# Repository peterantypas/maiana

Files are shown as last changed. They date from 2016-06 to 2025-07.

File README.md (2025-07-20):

# MAIANA&trade;: The Open Source AIS Transponder

I started this project around 2015 with the intention of experimenting and eventually building something for my own boat.
I was not impressed with commercial AIS class B transponders. They seemed bloated, expensive and some of them were particularly power-hungry. Also, my boat is rather small and I have very little room for "nav" instruments, so I didn't want a huge enclosure inside plus two external RF cables, one for VHF and one for GPS. So I set out to create my own "lean and mean" design and I sailed with it for 2 years.

Fast forward to 2023, and it has taken a life of its own:

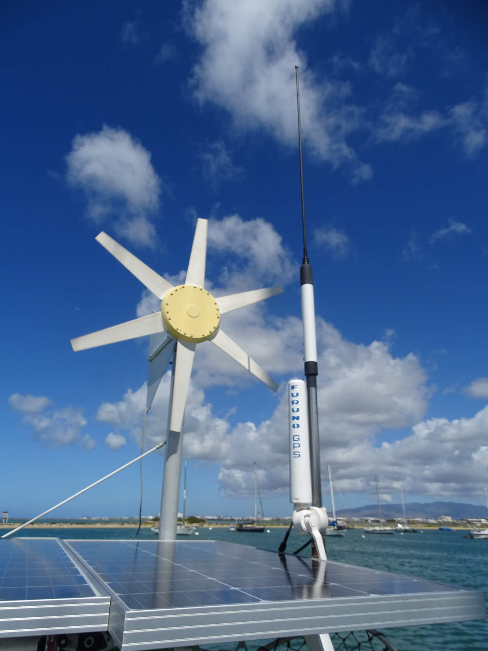
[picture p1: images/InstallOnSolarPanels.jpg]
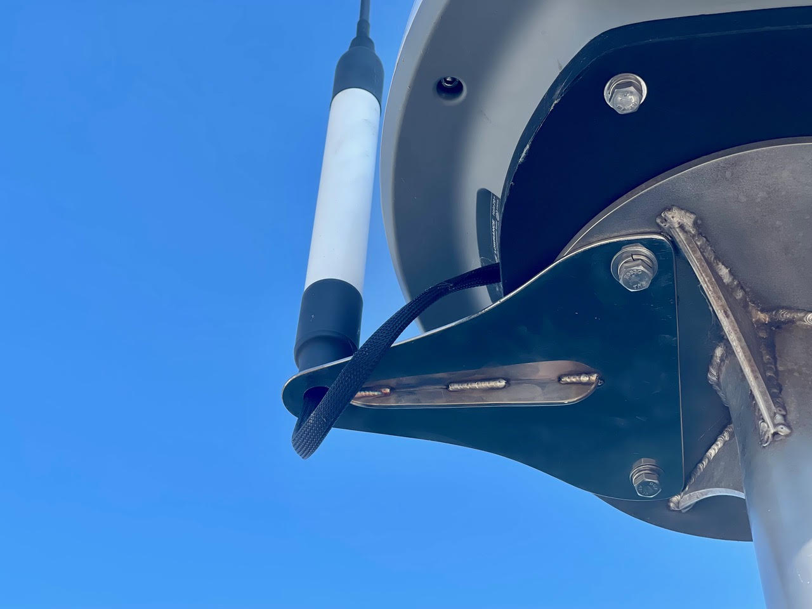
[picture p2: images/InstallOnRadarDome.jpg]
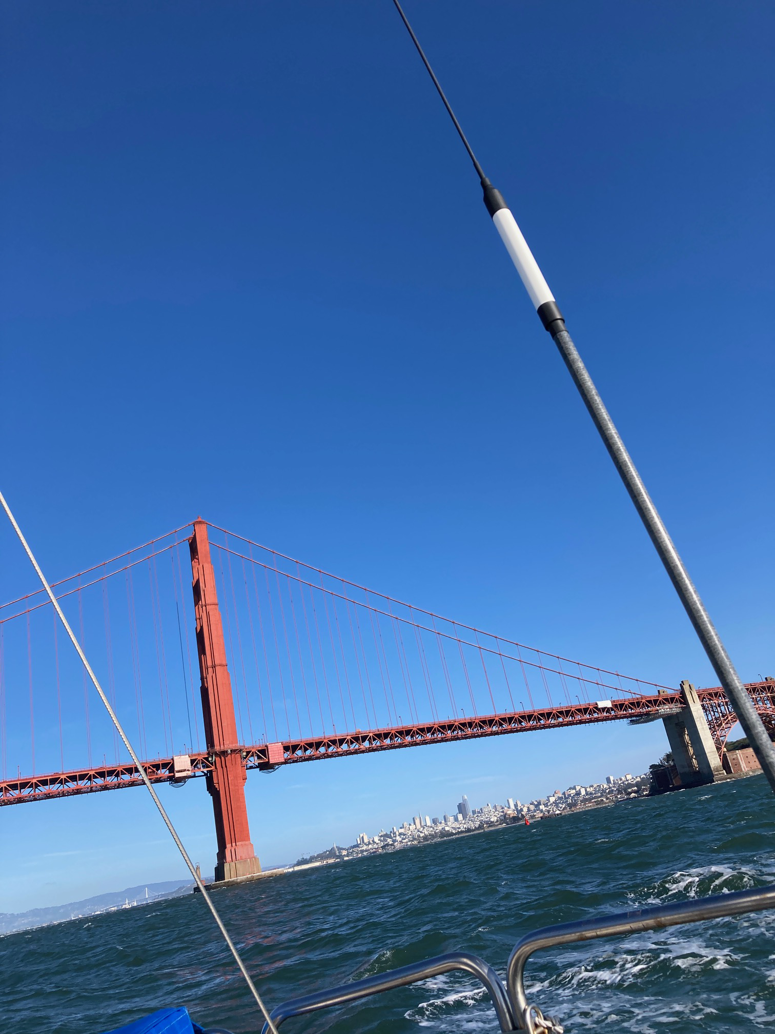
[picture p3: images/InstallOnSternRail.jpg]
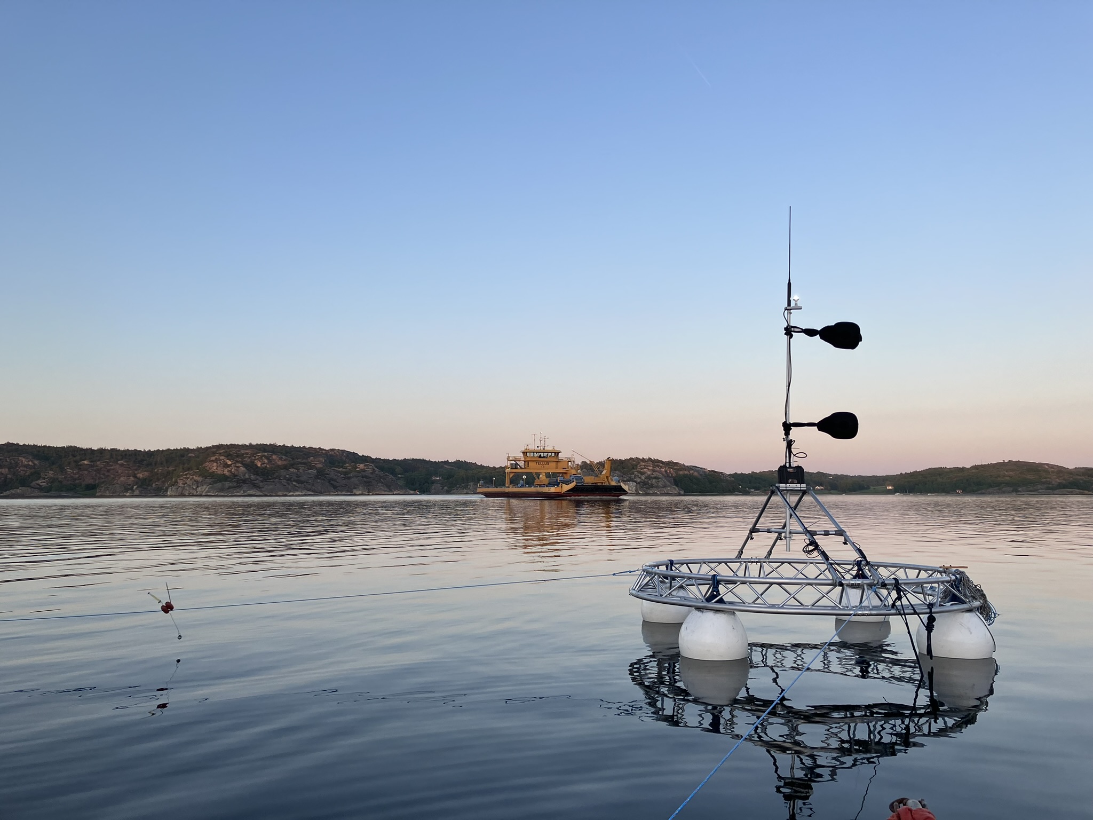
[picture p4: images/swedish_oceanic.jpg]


The main difference between MAIANA&trade; and every commercial transponder is that it's a self-contained unit, and thus its performance is 100% repeatable. The entire transponder circuit, the GNSS and all antennas are in the same housing. The design has been validated by fabricating _over 300 units_ now (July 2023).

So with all the core functionality kept outside and under tight control, the only other thing we need is power and data connections. Now, what's the most common cable that can carry a few signals 50 feet away? If you guessed "Ethernet", you guessed right. Commonplace Cat5 cable can deliver power plus serial data signals anywhere on an average sized pleasure boat. So that's how the exterior unit connects to the cabin, where one of these breakouts offers USB, NMEA0183 or NMEA2000 adapters to connect to the rest of the boat's systems. 

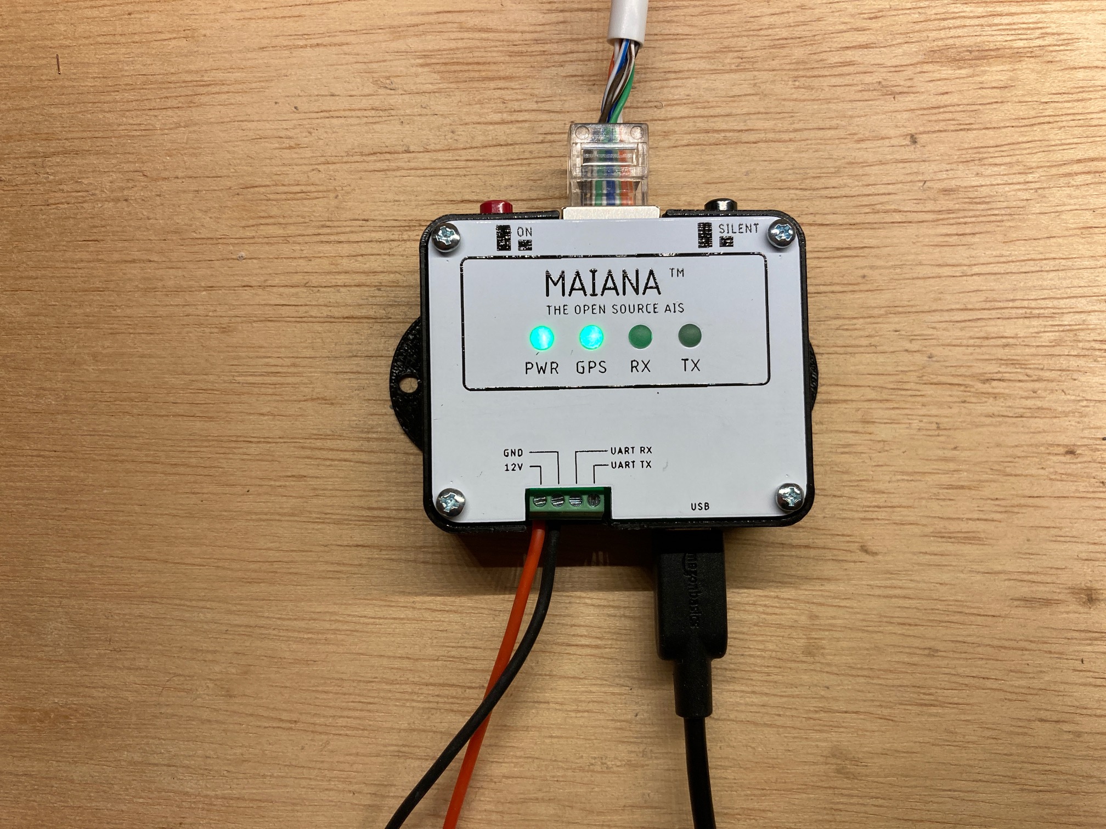
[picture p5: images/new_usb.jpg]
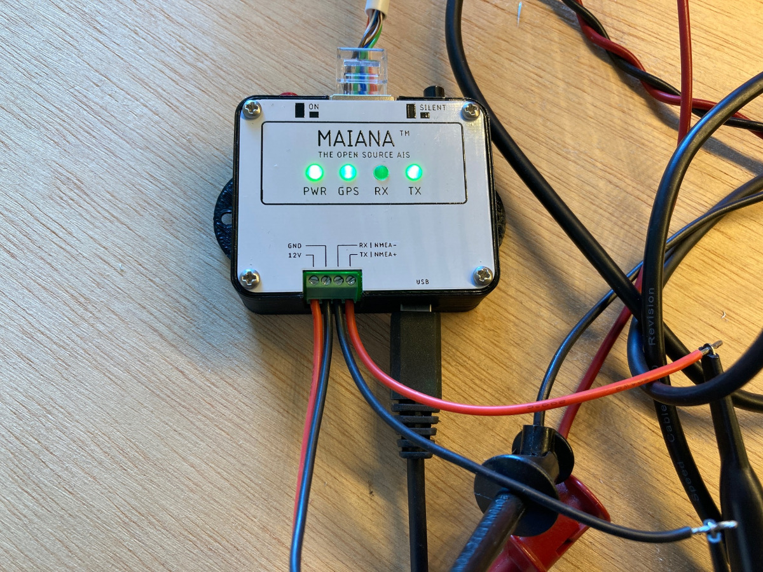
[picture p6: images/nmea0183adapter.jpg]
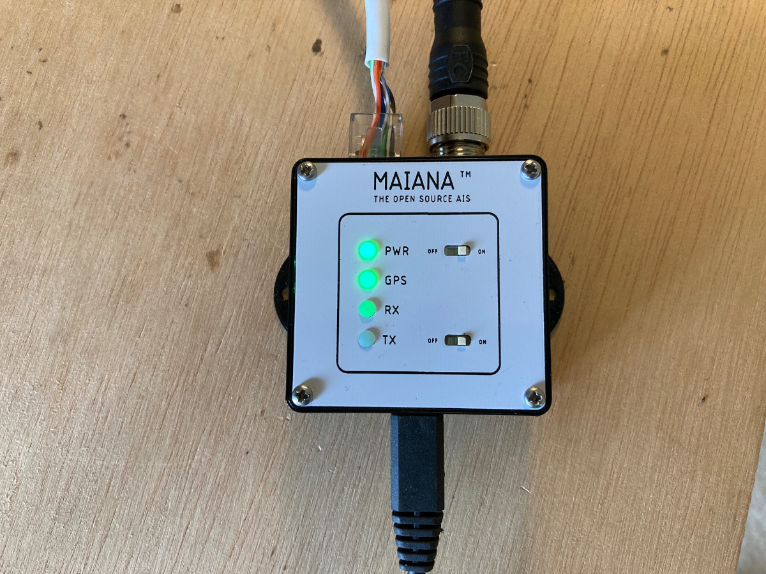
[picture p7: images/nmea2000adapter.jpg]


## Hardware Design

### Mechanical
The antenna casing that you see in these photos is a piece of 1" Schedule 40 "furniture" grade PVC pipe. It is the highest grade of such material, with a solid white PVC core (not a coated household grade pipe). Still, it's the most inexpensive UV resistant material available, and it looks great too!

The VHF antenna whip is built using an epoxy wound filament tube coated with high quality, UV resistant irradiated polyolefin ("heat shrink"). The company that makes this tubing (and helped me with this design challenge) also built the landing gear for NASA's Ingenuity helicopter on Mars, so they definitely understand how to deal with harsh environments. The bottomline is that unlike typical fiberglass antenna masts, this antenna is not going to degrade and "blossom" under continuous UV exposure. Starting with January of 2022, the antenna tube will be made of two telescopic pieces of the same material. This will greatly reduce the cost of shipping the kit to Europe and Australia.

The entire outdoor assembly is held together by the same high grade heat shrink tubing, so there is no need for any adhesives! The main water seal is formed by heat shrinking around a specially designed 3D printed cap made of PLA. This part naturally softens when heated and as it's compressed by the heat shrink tubing surrounding it, it forms a permanent, watertight colar around the antenna tube. This blocks rain water and salt spray from the top. A layer of clear heat shrink in the interior forms a secondary water seal encompassing the lower part of the antenna. Finally, the PCB can be sprayed with conformal coating for an added layer of protection. Silicone spray works best and has no appreciable detuning effect on the GNSS.

With no adhesives getting in the way, the unit can actually be opened and serviced by (carefully) cutting through the heat shrink tubing with a knife, then resealing with the same material and method as before. This, in fact, was one of my design goals from the beginning.

### Electrical
As I mentioned already, the transponder circuit is inside the antenna case. It's a 24mm x 84mm 4-layer PCB:

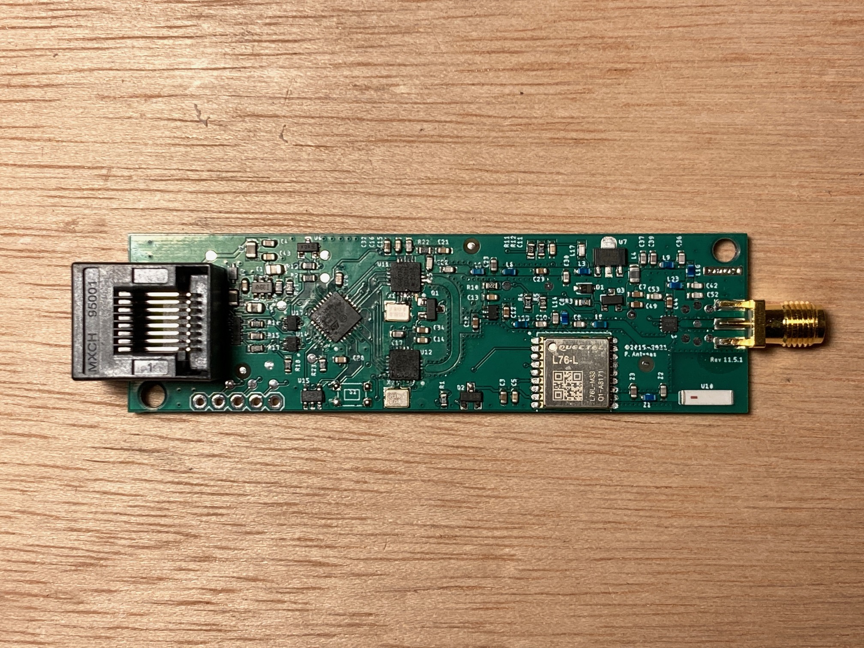
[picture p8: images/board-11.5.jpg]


The core design is based on two Silicon Labs "EZRadio Pro" series ICs. All kits shipping today are based on the Si4460.

The microcontroller on this board is a STM32L4 series (422, 431 and 432 supported). I chose these because the 80MHz clock allows the SPI bus to operate at exactly 10MHz which is the maximum supported by the Si446x ICs. This is important, as a transponder is a *hard real time* application, so SPI latency must be minimized. All kits today are based on the STM32L432KBU6.

The GNSS is now a Quectel L76L-M33 and relies on a Johansson ceramic chip antenna. It usually takes a minute to acquire a fix outdoors from a cold start. With the latest antenna tuning, it offers near-navigation grade accuracy (typical HDOP at sea is less than 2 meters).

The transmitter front end is based on a power MOSFET typically found in handheld VHF radios and outputs just over 2 Watts (+33dBm). It has a verified range of over 20 nautical miles on a masthead and 10+ miles on a pushpit.

The system is designed to run from a 12V battery and exposes a 3.3V-level UART for connecting to the rest of the boat. The UART continuously sends GPS and AIS data in NMEA0183 format at 38.4Kbps. It also accepts certain commands for management. The breakout boxes pictured above deliver this stream via USB, NME0183 (RS422) or NMEA 2000 (CAN). The 3 "fancy" breakouts feature _galvanic isolation_ of their USB connection to avoid causing unintended problems with laptops and other devices whose power supplies are meant to _float_. This also means that you cannot use USB to power MAIANA&trade; - it must connect to a 12V battery.

In addition, there is now a "bare bones" UART+USB breakout:

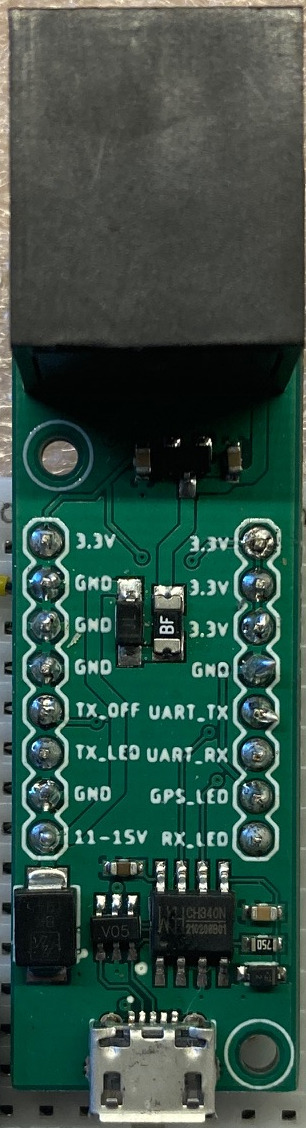
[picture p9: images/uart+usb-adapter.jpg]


This provides the simplest, lowest cost interface to a Raspberry Pi, Arduino or any other similar system you may want to wire directly. It is _not_ galvanically isolated to keep the cost really low. This adapter is now part of the base kit and ships with every configuration.

For the circuit to transmit, it must be configured with persistent station data (MMSI, call sign, name, dimensions, etc). This is stored in an EEPROM and is provisioned over a USB/serial connection via a command line interface. If station data is not provisioned, the device will simply run as a 2 channel AIS + GNSS receiver.

SOTDMA synchronization is based on the very acurate 1 PPS signal from the GNSS and the UTC clock. MAIANA&trade; does not synchronize itself to other stations because practical experience revealed that it's literally the "Wild West" out there: There are *many* commercial class A systems in operation today with buggy time slot management, so the simplest solution is to not rely on any of them. That said, the design behaves as a "class B" so it will not attempt to reserve time slots. It will just transmit autonomously and independently, based on Clear Channel Assessment, at the schedule permitted for this class of device. 

All adapters (except the "bare bones" one) feature a *silent mode* switch to explicitly disable transmission. If you need this for the UART adapter, you can wire one yourself.

In terms of power consumption, the main board draws about 45mA from 12V in receive mode, and spikes up to 700mA during transmission (for only 27 milliseconds). The adapters add an extra 0.5mA - 25mA depending on choice. So MAIANA&trade;'s most power hungry configuration needs about 0.6 Watts, which is a lot less than a typical LED-based cabin light.

### Software

The transponder firmware is an [Eclipse CDT project](latest/Firmware/Transponder) that you could clone and build. The code is C++ with a BSP abstraction layer so you need to tweak bsp/bsp.hpp or define one of the required symbols in the preprocessor to build for different board revisions. It contains snippets of STM32Cube generated code, but is does not follow ST's "spaghetti" structure.

The NMEA2000 adapter also has its own separate [firmware project](latest/Firmware/NMEA2000Adapter).

As of December 2021, MAIANA&trade; is fully integrated into [OpenPlotter](https://openmarine.net/openplotter). This means that it can be provisioned and managed entirely from its graphical interface, including firmware updates. To accomplish this, I had to make both a hardware and a software change: 

- The hardware change was to reinstate the I2C EEPROM that I used in earlier designs. This was necessary because STM32 applications that are interrupt heavy cannot safely erase and write any pages in the same flash bank, as the *entire* bank gets locked. This means that the next interrupt may be unable to execute, thus causing the processor to hang until the watchdog resets it. Moving persistence to an EEPROM solves this problem.

- The software change was to dust off the original [bootloader](latest/Firmware/Bootloader) that I wrote years ago and make it bulletproof: Even if you manage to brick the unit by uploading garbage firmware into it, it has a built-in "rescue" mode. All you have to do is toggle the TX switch a couple of times during the first 2 seconds after power-up and it will enter firmware update mode again.

### CAD

Everything is [here](latest/CAD). 

### Building the unit

This is going to be difficult for all but the most technically advanced. The board features all surface mounted components, with 4 QFNs, a few SOT-363s and tightly spaced 0603 passives. The antenna switch on board 11.3.0 is about 0.8 x 1 mm and you'll need a microscope to align it. So unless you're very skilled and well equipped, you will find it difficult to build. 

### Buying a kit

I have developed a kit which includes pre-soldered (and programmed) boards as well as the antenna, main casing and heat shrink tubing. See [the installation manual here](https://github.com/peterantypas/maiana/blob/master/latest/Manuals/MAIANA%E2%84%A2%20Assembly%20Manual%20(Rev%204).pdf) to get a better idea of the process.

If you are located in North America, send an email to *maiana.kits@_dontspam_gmail.com* (remove the spambot blocker of course). Tariffs have made it difficult to ship to Europe and vice versa, so [OpenMarine](https://shop.openmarine.net) is working with European based teams to build and ship directly from Barcelona, Spain.

### License

CAD and transponder firmware are licensed under GPLV3. I chose the most "copyleft" license to discourage commercial entities from ripping this off and then "close-sourcing" it. The flipside of this is that if you can fork the design and make something better, then you deserve the success! That said, MAIANA&trade; will become a registered trademark soon, so if you plan to do this you must use a different name.

The NMEA2000 adapter firmware is under MIT license to be consistent with the libraries it depends on. Feel free to use it as you wish.

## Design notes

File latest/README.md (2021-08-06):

## This is the current version

This folder contains the latest and greatest. Under CAD/, you'll find directories for each board revision with associated Eagle files and exports. 

Under Firmware/ you'll find two Eclipse CDT projects. One for the transponder, and one for the NMEA 2000 adapter.

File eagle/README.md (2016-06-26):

# Eagle CAD files

The hardware is made up of two boards. Although I officially baptised them the "Logic Stage" and the "RF Stage", I think it's better to think of them
as the "easy" board and the "tricky" board. 

The "easy" board holds the microcontroller (STM32F302, an ARM Cortex M4 running at 72Mhz), the USB interface, power regulator, EEPROM and GPS. It carries nothing
more than power and digital signals. No analog RF signal traverses any trace on it.

The "tricky" board, is effectively a mixed signal circuit. It holds the RF ICs (which share the same SPI bus), the LNA, the Front End Module and the associated 
analog filters. The critical RF traces are designed as coplanar waveguides with liberal quantities of via stitches, and they should be close to 50Ohm for 
Oshpark's 2-layer PCB and dialectric.

The two dual-layer PCBs are mirror images of each other and they mate with standard .01" male/female pins. Unlike Arduino and Pi hats, the boards mate 
"back-to-back", so as to maximize isolation between the MCU and the RF traces.

I chose to partition the hardware in this way to minimize the pain of iterating, since the analog RF stage went (and will continue to go) 
through more iterations than the MCU / EEPROM / GPS stage.

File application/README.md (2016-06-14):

# Main application

The main transponder application initializes the RF ICs and handles all interrupts from the GPS UART and the RF IC clock/data lines.
It also utilizes a few timers, one of which represents SOTDMA time slots and is continuously aligned with the PPS signal from the GPS.

Unlike many examples we see online, the microcontroller runs in _both_ thread and interrupt mode. After hardware initialization,
*main()* enters an infinite loop dispatching events and keeping the watchdog timer happy. Interrupt code (which is sprinkled throughout) 
performs as little work as possible and queues up events for non-real time operations to be processed in thread mode. There is no operating system (I could never
justify the overhead) so this is a very lean approximation of one.

Almost all memory is managed using pre-allocated pools of objects.

The Standard Peripheral Library for stm32f3xx is included.

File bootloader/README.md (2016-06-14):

# Bootloader
The bootloader is a small (~10K) application that occupies the first few pages of flash at 0x0800000.
Its only purpose is to determine whether an application is installed by inspecting a specific Flash page for special metadata. 
If the application is installed it just passes control to it, otherwise it enters UART software upload mode.

When an upload completes, the bootloader writes the special metadata page and resets the system, which will 
cause its next reincarnation to launch the application.

When the application receives a command to start a "software update", it will simply erase the special metadata
and reset the system, which will cause the bootloader to enter UART upload mode.

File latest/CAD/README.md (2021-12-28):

## Board design files

This directory contains Eagle CAD files as well as schematic PDFs and Gerber exports for board fabrication.

The board stackup is good enough for either OSH Park 4-layer, or JLCPCB 4-layer with controlled impedance (JLC2313). 

### Latest Board

Revision 11.5.2 does away with the (hard to source) regulator from ST and replaces it with a Zener + NPN combination that delivers about 8.5V to the PA under load.

### Breakouts
These directories contain Eagle and FreeCAD files for the NMEA0183, NMEA 2000 and USB adapters. Their front panels are PCBs so gerbers are
here as well. The UART+USB adapter is a very basic breakout board for those who would rather wire the transponder themselves.

### Antenna
This directory contains FreeCAD and STEP exports of the 3D printed parts that make up the antenna.

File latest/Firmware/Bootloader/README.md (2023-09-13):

# MAIANA Bootloader

This is a custom bootloader that installs at flash address 0x08000000. In addition to providing firmware updates, this bootloader
also performs integrity checking and can even rescue a board if a bad application firmware binary is installed.

## Installation

The bootloader must be built and flashed via SWD. An alternative is to use the ST ROM bootloader to install the binary via UART. 
This will require manipulation of the BOOT0 signal though, which is only exposed via a test pad for a bed-of-nails fixture.

## Firmware update

All application firmware must be installed via UART. See the example script in the Python subdirectory for the protocol.

## Integrity checking

This bootloader maintains a metadata page at flash address 0x08004000. It holds the size and checksum of the installed application image (if any). 
The application image must be linked for installation at address 0x08004800. If no application is present or the checksum fails, the bootloader enters
DFU mode automatically.

## Rescue mode

If the TX switch is toggled twice during the first 2.5 seconds after power-up, the bootloader enters DFU mode again, regardless of application firmware state.

## Pre-built binaries
The Binaries/ folder contains pre-built binaries for L422, L431 and L432. You can flash those via SWD into the top of flash (0x08000000) and then use one of the scripts in the Python folder for installing an application binary.

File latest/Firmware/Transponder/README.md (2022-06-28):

## Transponder firmware

This is a vanilla Eclipse CDT project. Import it into your workspace and (assuming you have ARM cross compiler installed) it should be straightforward.

The application is mainly interrupt driven, with an event queue being dispatched by main(). 

### Key updates

 - It turned out that FreeRTOS added no value, so it was removed
 - The TX_DISABLE signal is now supported. It is active low in board 9.x and active high in board 10.x and higher
 - Board 9.3 adds 3 "status" (LED driving) signals for GPS, RX and TX
 - Board 10.x needed a GPIO swap to make routing viable and inverted the logic of the TX_DISABLE signal, but it's all abstracted in the BSP 
 - The new 'cli' command was introduced to reboot the board into 'quiet' mode, making it a lot easier to program and verify the station data
 - Station metadata is now stored in EEPROM again.
 
### Building and flashing

You will need Eclipse CDT with the MCU package, plus the ARM GCC crosscompiler toolkit. You may need to tweak toolkit paths for the build to work.

The project supports the following STM32 MCUs: L412, L422, L431 and L432.

There are multiple build configurations. Some of these configurations can be installed directly at address 0x08000000, without any bootloader. 
Configurations with "bootloader" in the name are linked for use with the new MAIANA bootloader only and will not function if installed at the top of flash.

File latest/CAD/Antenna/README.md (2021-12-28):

### Antenna CAD

Cap version 7.0 and lower portion version 5.0 are used for the single piece antenna tube that currently ships domestically in the US. 

Cap version 9.0 and lower portion version 7.0 are used for the new split antenna tube that will ship starting January 2022.

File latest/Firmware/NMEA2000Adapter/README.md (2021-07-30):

# maiana-n2k
This is the firmware for MAIANA's NMEA 2000 breakout adapter.

It currently runs on an STM32L422 and relies on a MCP2515 CAN controller with a TCAN33 bus driver.

It incorporates a copy of [Timo Lappalainen's NMEA 2000 library](https://github.com/ttlappalainen/NMEA2000),  with a few modifications I found necessary. My main addition is PGN 129041 (AtoN report) which I was able to reverse engineer. I'm hoping to merge this back into Timo's library, but the rest of the changes are very much STM32-HAL specific so they probably won't be incorporated.

In addition, it incorporates a copy of the [modified CAN BUS Shield library](https://github.com/ttlappalainen/CAN_BUS_Shield), which I again had to modify slightly to be able to migrate away from Arduino.

Another library that is embedded here is [libais](https://github.com/schwehr/libais) which I had to modify to disable exceptions. This library is very good at parsing NMEA0183 messages, but it was really designed for a microprocessor rather than a microcontroller. Nevertheless, the STM32L422 seems to have enough RAM for it.

I am making no claims that this code base is clean and tidy ;P I can only attest to the fact that it works with at least 2 NMEA 2000 adapters: Digital Yacht iKonvert and Actisense NGW-1.

### Building
You will need Eclipse CDT with GNU ARM GCC. It's possible that the project configuration will not suit your own environment and you'll have to tweak settings. I never quite managed the art of Eclipse project sharing!

### Installing
The adapter must be placed into DFU mode using a pushbutton. This switches the USB serial adapter multiplexer to the MCU's USART1 so you can use ST's bootloader programmer for flashing the binary. There is no SWD interface exposed on that board. Also, the board is powered exclusively from the NMEA2000 bus so it must be plugged in.

### License
MIT, so it's consistent with Timo's license.

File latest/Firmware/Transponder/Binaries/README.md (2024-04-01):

## Pre-built binaries

This directory contains binaries for boards 11.3 and newer *purchased through the OpenMarine store*. **If you do not use OpenPlotter 
or you are unsure whether these apply to your board, please start a ticket or a discussion**. Do NOT attempt to flash these with an SWD programmer. They are not linked for the top of flash (0x08000000). Furthermore, they *must* be used in conjunction with the MAIANA bootloader and should only be written via the UART. The bootloader will checksum them, write their metadata in a dedicated flash page, and only then will it execute them.

### How to select the right firmware

Launch the MAIANA app and connect to the transponder. You may need to disable / disconnect MAIANA from Signal K first.
Make a note of:

- Your board's hardware revision (example: 11.6.0)
- Your board's MCU model (example: STM32L422)
- Your board's firmware revision (example: 4.0.0)

Locate the appropriate binary in this directory. Ignore the last digit of your board's revision -- it doesn't matter. So if you have board 11.3.0 with an STM32L422 processor, the right binary is maiana-stm32l422-hw11.3-fwXXX.bin where XXX is the latest revision you see here. If you already have this firmware on your board, there is no update.

## Firmware update history

### Version 4.4.1

This release fixes a bug introduced in 4.3.0, where boards with the L412 processor do not report the MCU in the CLI.

### Version 4.4.0

This release added a CLI for trimming the crystals during manufacturing. This will be necessary going forward.

### Version 4.3.0

This release includes enhancements for manufacturing

### Version 4.1.0

This firmware release corrects the tuning of the crystal oscillator for the Si4467 chips. This applies to boards made after November 2021 which contain the following
crystal:



The tuning changed by 5 KHz when the design had to migrate to this crystal due to supply problems. See issue [#103](https://github.com/peterantypas/maiana/issues/103)

### Version 4.0.0

This firmware release makes use of the new MAIANA bootloader.

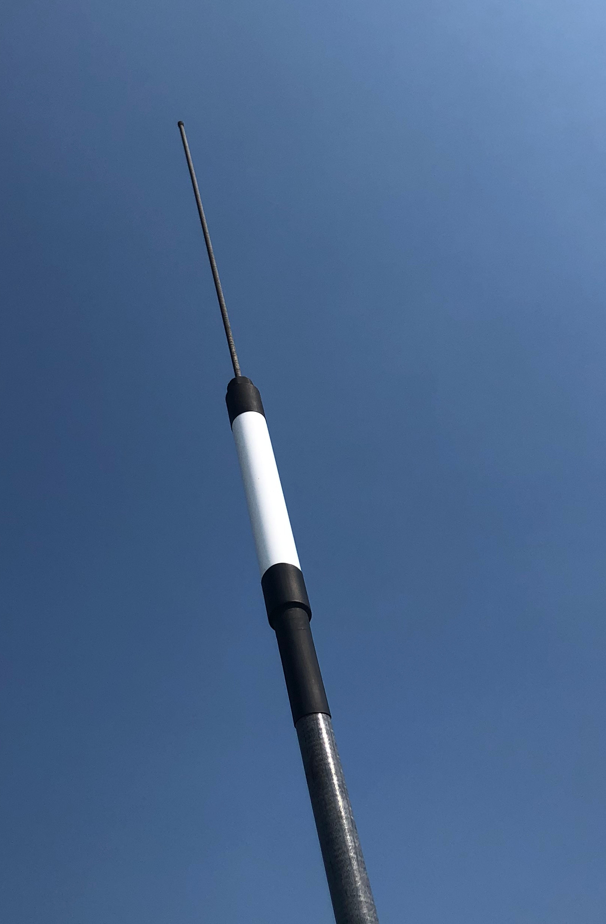
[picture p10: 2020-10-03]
images/UnitExterior.jpg

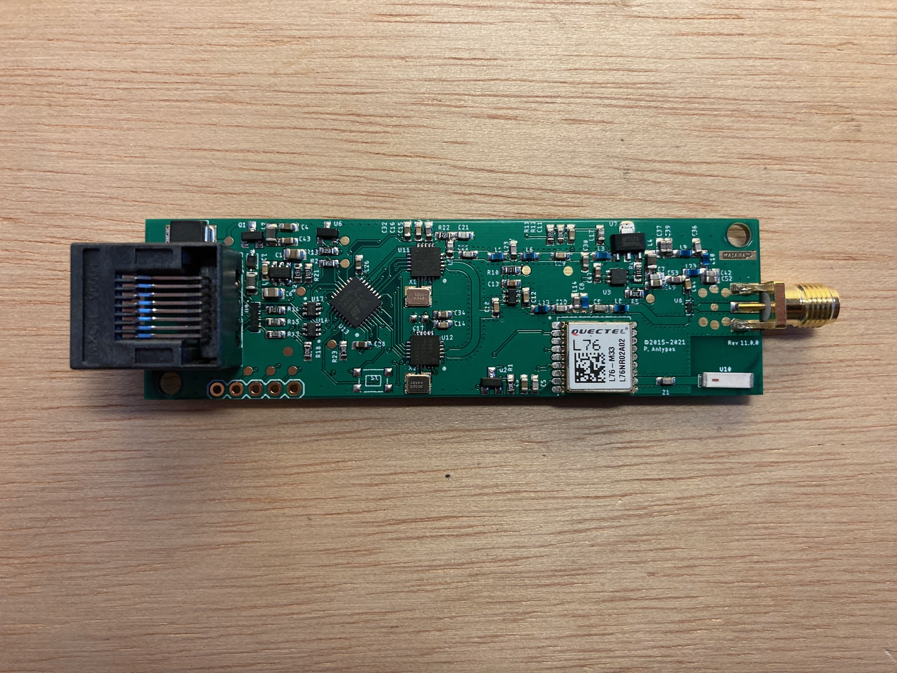
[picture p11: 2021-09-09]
images/board-11.jpg

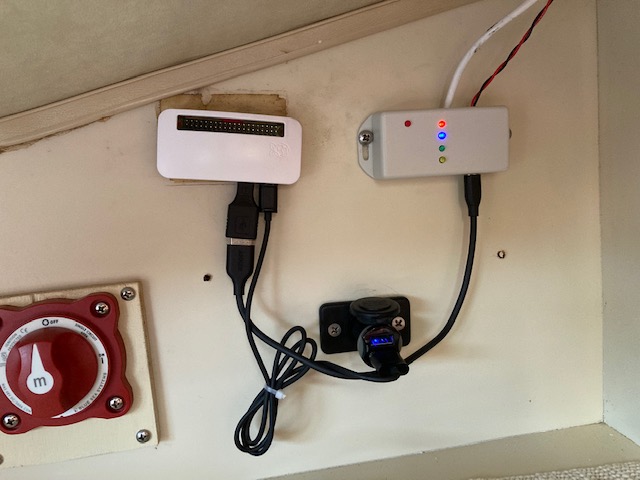
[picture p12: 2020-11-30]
images/MAIANA-ControlBox.jpg

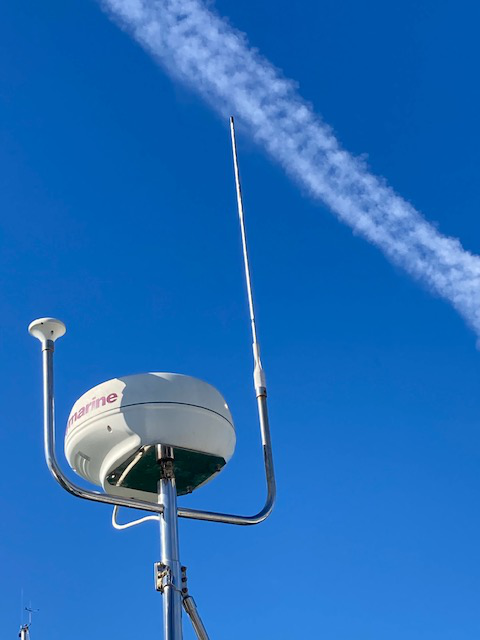
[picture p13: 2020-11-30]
images/Antenna-Example2.jpg

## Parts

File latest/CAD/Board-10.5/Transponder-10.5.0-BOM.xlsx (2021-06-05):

Qty | PartNo | Description | Value | Package | Reference Designators
2 | 1N4148WTQ-7 | Standard SMD silicon diode | 1N4148WTQ-7 | SOD523 | D5, D6
1 | 1575AT43A0040E | SMD Ceramic GNSS Antenna | 1575AT43A0040E | 1575AT43A0040E | U10
2 | 06035A360JAT2A | Standard SMD capacitor | 36pF | 0603 | C52, C53
1 | 54602-908LF‎ | RJ45 Jack | RJ45 | RJ45-8 | JP1
1 | AFT05MS003NT1 | RF MOSFET | AFT05MS003NT1 | SOT-89 | U7
1 | AP3211KTR-G1 | Buck converter | AP3211KTR-G1 | SOT23-6 | U1
1 | BAT41ZFILM | Diode | 250MA/100V | SOD-323 | D4
1 | BGA2818,115 | MMIC Wideband Amplifier | BGA2818,115 | SOT363 | U5
1 | BRC2012T2R2MD | Standard SMD inductor | 2.2uH | 0805 | L4
2 | BZT52C3V6T-7 | Zener Diode | BZT52C3V6T-7 | SOD523 | D1, D2
2 | CX3225SB30000D0FPLCC | Classic 4-pin 3.2 x 2.5mm crystal | CX3225SB30000D0FPLCC | NX3225 | X1, X2
1 | D3V3X8U9LP3810 | 8 CHANNEL LOW CAPACITANCE TVS DIODE ARRAY | D3V3X8U9LP3810 | U-DFN3810-9(B) | U9
3 | DMN63D8LDW-7 | Dual N-Channel MOSFET | DMN63D8LDW-7 | SOT363 | U4, U14, U17
1 | DMP3099L-7 | P-CHANNEL MOS FET | DMP3099L-7 | SOT23 | Q1
4 | EMK107B7104KAHT | Standard SMD capacitor | .1uF | 0603 | C4, C26, C28, C43
5 | EMK107BJ225KA-T | Standard SMD capacitor | 2.2uF | 0603 | C3, C32, C34, C47, C49
1 | EMK212ABJ106KG-T | Standard SMD capacitor | 10uF | 0805 | C1
1 | GCM1885C2A160JA16D | Standard SMD capacitor | 16pF | 0603 | C23
1 | GRM21BR61A226ME51L | Standard SMD capacitor | 22uF | 0805 | C6
6 | GRM188R71E223KA01D | Standard SMD capacitor | 22nF | 0603 | C2, C5, C11, C13, C14, C16
2 | GRM1885C1H3R3BA01D | Standard SMD capacitor | 3.3pF | 0603 | C9, C10
2 | GRM1885C1H200JA01D | Standard SMD capacitor | 20pF | 0603 | C22, C42
4 | GRM1885C1H222JA01J | Standard SMD capacitor | 2.2nF | 0603 | C12, C18, C29, C44
1 | GRM1885C1H390JA01D | Standard SMD capacitor | 39pF | 0603 | C36
2 | GRM1885C1H470JA01J | Standard SMD capacitor | 47pF | 0603 | C30, C37
2 | GRM1885C1H471JA01D | Standard SMD capacitor | 470pF | 0603 | C7, C21
1 | GRM1885C1H560JA01D | Standard SMD capacitor | 56pF | 0603 | C39
2 | GRM1885C2A240JA01D | Standard SMD capacitor | 24pF | 0603 | C24, C25
3 | GRM1885C2A910JA01D | Standard SMD capacitor | 91pF | 0603 | C8, C15, C17
2 | HK1608R47J-T | Standard SMD inductor | 470nH | 0603 | L5, L17
1 | L76-M33 | GNSS Module | L76-M33 | GPS_MODULE | U2
1 | LDFPVR | 1A Adjustable LDO | LDFPVR | DFN6-2X2 | U3
1 | LQW18AN10NG00D | Standard SMD inductor | 10nH | 0603 | L14
1 | LQW18AN18NG00D | Standard SMD inductor | 18nH | 0603 | L9
1 | LQW18AN22NJ00D | Standard SMD inductor | 22nH | 0603 | L10
1 | LQW18AN36NG00D | Standard SMD inductor | 36nH | 0603 | L3
1 | LQW18AN39NG00D | Standard SMD inductor | 39nH | 0603 | L23
1 | LQW18AN47NG00D | Standard SMD inductor | 47nH | 0603 | L1
1 | LQW18AN56NG00D | Standard SMD inductor | 56nH | 0603 | L11
1 | LQW18ANR10G00D | Standard SMD inductor | 100nH | 0603 | L7
1 | LQW18ANR13J00D | Standard SMD inductor | 130nH | 0603 | L6
2 | LQW18ANR27J00D | Standard SMD inductor | 270nH | 0603 | L8, L13
2 | MLZ2012M4R7WT000 | Standard SMD inductor | 4.7uH | 0805 | L2, L12
1 | RC0603FR-072K4L | Standard SMD resistor | 2k4 | 0603 | R11
1 | RC0603FR-1016KL | Standard SMD resistor | 16k | 0603 | R24
1 | RC0603JR-070RL | Standard SMD resistor | 0R | 0603 | R17
3 | RC0603JR-071K1L | Standard SMD resistor | 1k1 | 0603 | R2, R4, R13
8 | RC0603JR-0710KL | Standard SMD resistor | 10k | 0603 | R3, R5, R6, R7, R12, R16, R18, R23
1 | RC0603JR-0722RL | Standard SMD resistor | 22R | 0603 | R22
1 | RC0603JR-0751KL | Standard SMD resistor | 51k | 0603 | R21
3 | RC0603JR-07100RL | Standard SMD resistor | 100R | 0603 | R10, R14, R15
2 | SI4463-C2A-GMR |  | SI4463 | SI4463 | U11, U12
1 | SKY13330-397LF | SP2T RF Switch | SKY13330-397LF | QFN12 | U15
1 | SMBJ16CA-13-F | Bidirectional TVS diode | SMBJ16CA-13-F | SMB-BIDIR | D3
1 | STM32L412K8U6 |  | STM32L412K8U6 | QFN32 | U13
1 | ‎GRM1885C1H120GA01D‎ | Standard SMD capacitor | 12pF | 0603 | Z1

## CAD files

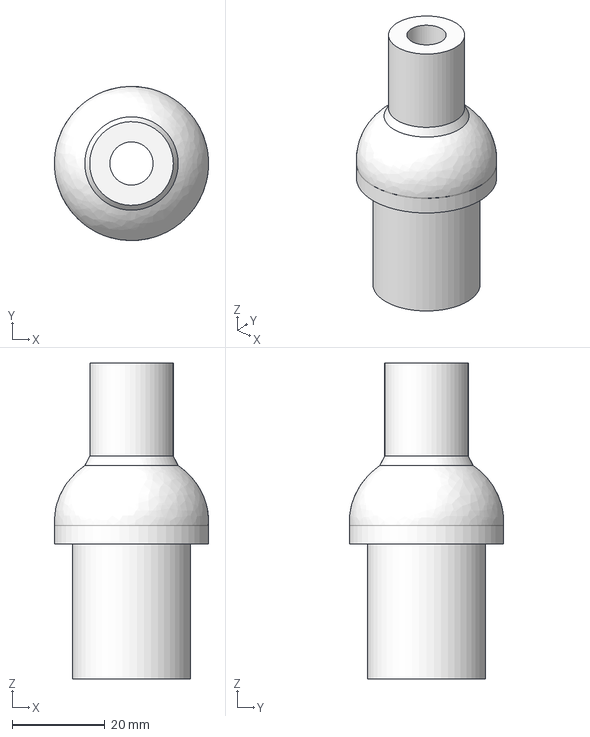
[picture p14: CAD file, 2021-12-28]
latest/CAD/Antenna/antenna_cap-9.0.step
33.2 x 33.2 x 68.0 mm

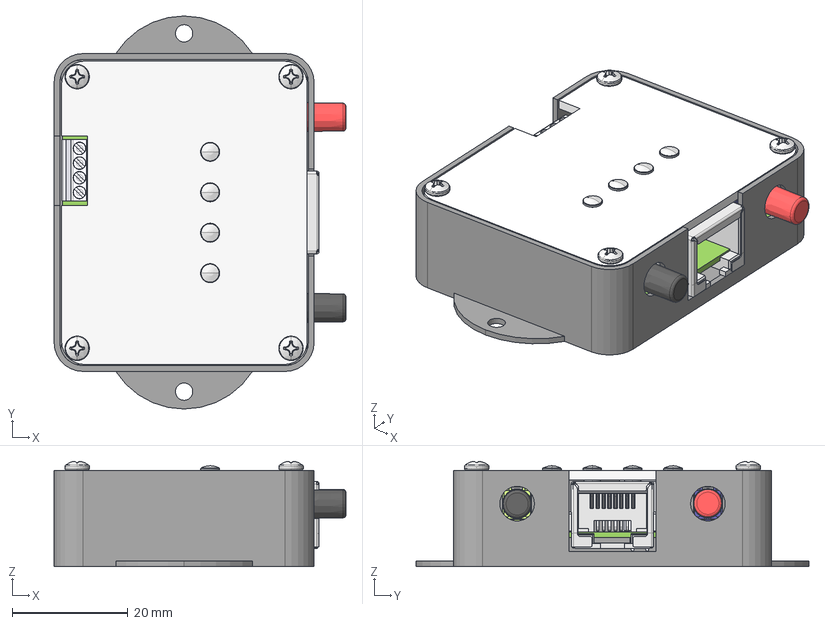
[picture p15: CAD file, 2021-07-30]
latest/CAD/NMEA0183Breakout/NMEA0183Breakout-3.0.FCStd
50.5 x 68.0 x 18.2 mm
PLP2_8MM001
PLP2_8MM
PLP2_8MM002
PLP2_8MM003
PCBWithCutouts
FrontPanelWithCutouts
RJ-82A86MMNL
P:\E-Switch Secure\3D_MODELS_STP_FORMAT\LC1258xxxP.stp
1Rxxx
P:\E-Switch Secure\3D_MODELS_STP_FORMAT\LC1258xxxP.stp001
1Rxxx001
mpt_0.5-4-2.54
90190A073
90190A074
90190A075
90190A076
90190A078
90190A077

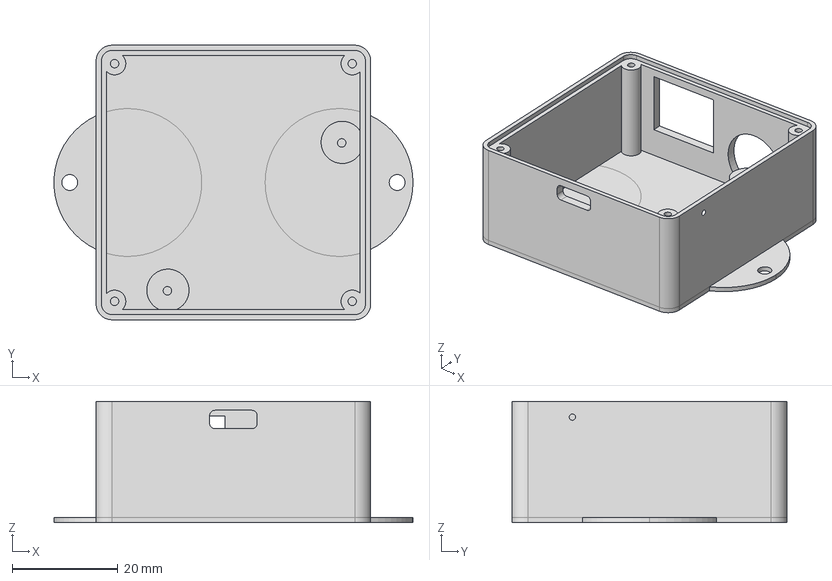
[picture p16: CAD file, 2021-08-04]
latest/CAD/NMEA2000Breakout/NewNMEA2000Breakout-1.1.step
68.0 x 52.0 x 23.0 mm

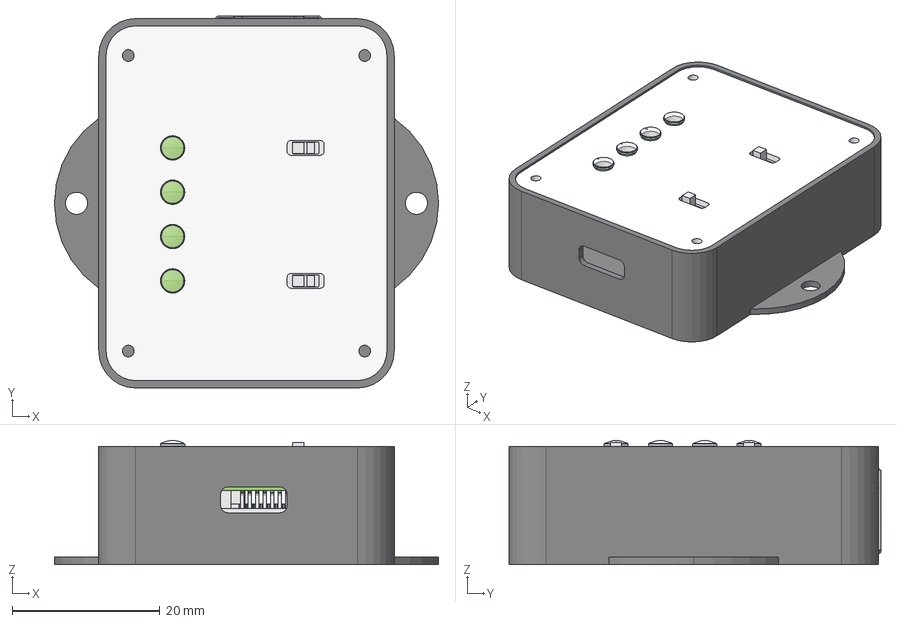
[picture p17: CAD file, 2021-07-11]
latest/CAD/USBBreakout/USBBreakoutEnclosure-2.0.FCStd
52.0 x 50.4 x 16.8 mm
RJ-82A86MMNL
691210910002 (rev1)
CL-SB-12B-01T001
CL-SB-12B-01T002
PLP2_125
PLP2_126
PLP2_127
PLP2_128
FrontPanelWithCutouts

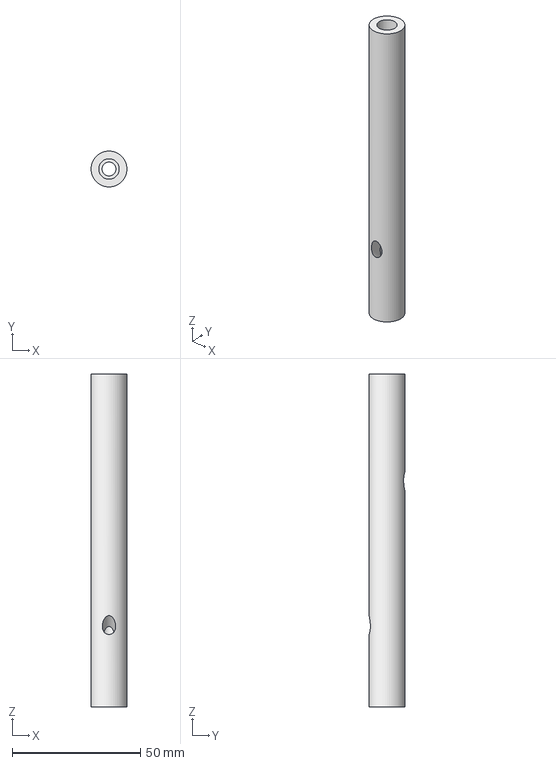
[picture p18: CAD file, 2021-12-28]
latest/CAD/Antenna/lower_antenna-5.0.step
14.0 x 14.0 x 130.0 mm

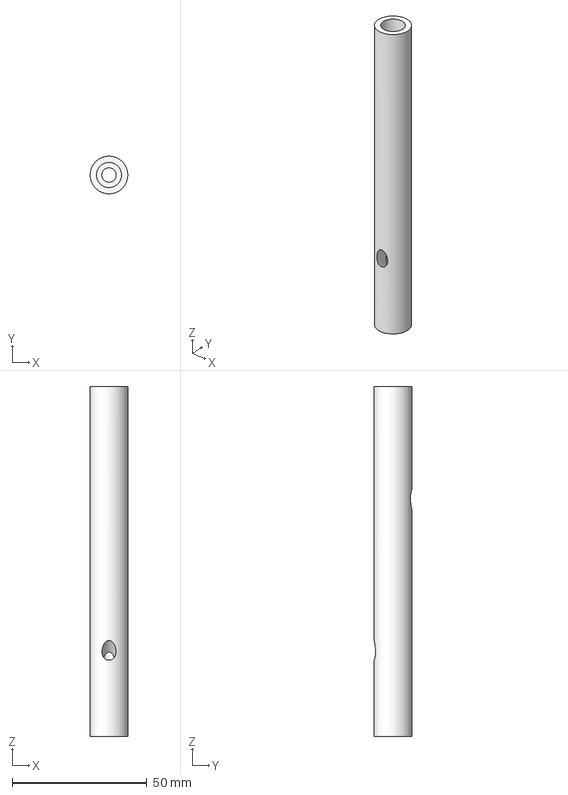
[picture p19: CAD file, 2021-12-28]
latest/CAD/Antenna/lower_antenna-7.0.step
14.0 x 14.0 x 130.0 mm

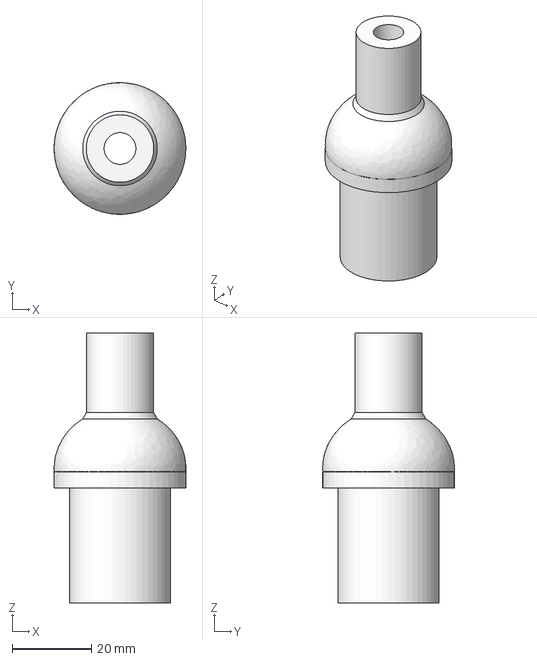
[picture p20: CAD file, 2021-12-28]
latest/CAD/Antenna/antenna_cap-7.0.step
33.2 x 33.2 x 68.0 mm

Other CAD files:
latest/CAD/Antenna/antenna_cap-7.0.FCStd
latest/CAD/Antenna/antenna_cap-9.0.FCStd
latest/CAD/Antenna/lower_antenna-5.0.FCStd
latest/CAD/Antenna/lower_antenna-7.0.FCStd
latest/CAD/NMEA2000Breakout/NewNMEA2000Breakout-1.1.FCStd

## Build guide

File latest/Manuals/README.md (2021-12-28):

### Assembly Manuals

As of January 2022, all kits ship in the configuration described in manual Rev 4. This manual combines and supersedes all other files in this directory.

Firmware updates for MAIANA will be carried out via the OpenPlotter app. The method described in the older manual here no longer applies.

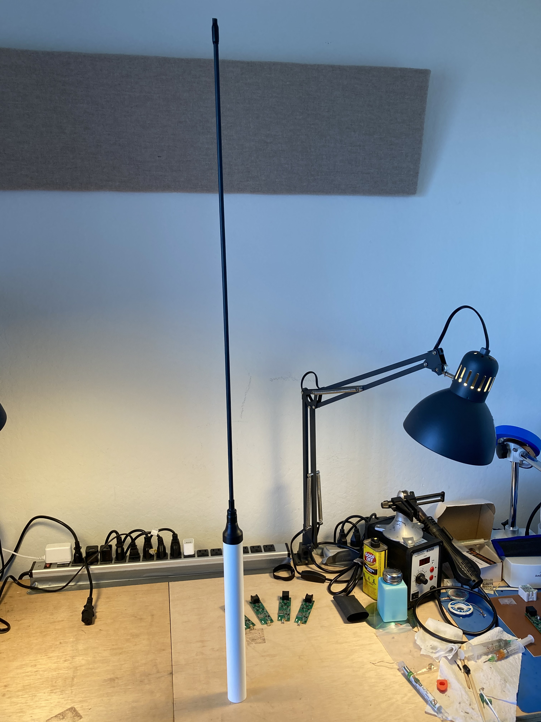
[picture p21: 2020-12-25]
images/Maiana-FinalAssembly.jpg

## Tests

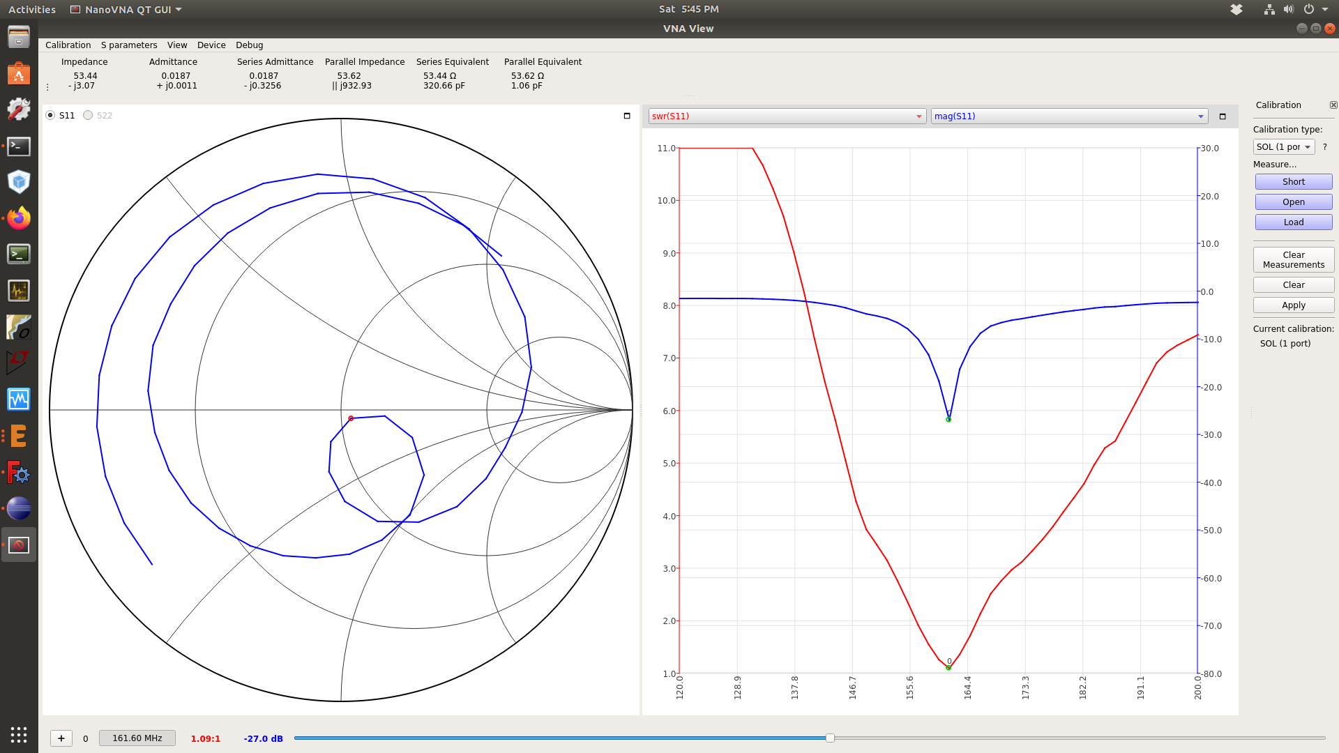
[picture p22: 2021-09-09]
images/maiana-tuning.png

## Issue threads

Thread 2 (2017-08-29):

AIS Transponder Full Development Kit

bobyboga092, 2017-08-29:
Dear Peter,

Do you have a complete set assembled development kit for ais transponder?
Thank you, hope hear from you soon.

Best Regards,

Boby H.

marktolson, 2017-11-09:
Is this project still in development?

peterantypas, 2017-11-13:
It depends on how you define "in development".

This project represents a snapshot of this effort that I decided to open source. There is a much more advanced private fork of this which has evolved substantially.

There's at least one party overseas who has built it and I'm helping them debug the firmware.

cerantonioclaudio, 2018-01-12:
Dear Peter, who has the transponder in recepction mode? Haw many nautical milles? Thank you
Best regards
Claudio

emanahov, 2018-03-01:
Dear Peter,

I am interested in getting access to this private fork and also to getting help from you for a more finished product.

Please, contact me at emanahov at gmail.com if you are interested to discuss your conditions.

Thanks
Eugeni

junkt1, 2018-08-07:
Dear Peter

I'm also interested in helping with prototypes. May I get access to the latest version? I have a plenty of HF measurement instruments available to qualify the RF part for instance and I’m interested in helping/realising a 5W SOTDMA Version

Thom

SvenHi, 2020-01-17:
Hi Peter,
thanks a lot for publishing this great project.
This is a great platform for my AIS experiments.
You wrote: "There's at least one party overseas who has built it and I'm helping them debug the firmware."
Does this already lead to a product? If yes it would be easier to buy the commercial one, and attach debug connector to it than build it up from scratch...
Could you explain, what's the purpose of the SI patch?
Thanks a lot.
Best Regards

junkt1, 2020-01-17:
Hi Sven & Peter
Can anyone of you explain me a bit how to get access to the project. As already written in august 2018 I’m interested in participating and helping in this project. The quasi standard AIS transceiver module from SRT is good but far not state of the art. Lets create our own!
Regards Thom

junkt1, 2020-01-17:
Hi Sven & Peter
Sorry I forgot to mention how to get access to more recent versions. The repository points to pretty old stuff

peterantypas, 2020-10-07:
It only took 2 years to finally get around to this ;P

SvenHi, 2020-10-11:
Hi Peter,
great job! Tindie would be best marketplace for this. It is serious, and there are already AIS items for sale.
If the kit will be available, I will buy one. Keep me informed when available.
I already ordered PCBs and parts for the previous design, but never started to build it up...
When there is a kit available, I could focus to set up the SDK for the firmware.
Thanks!
Best Regards Sven

Closed 2020-10-07.

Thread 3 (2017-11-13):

Missing component values

WillWill45, 2017-11-13:
Hello Peter,

I was just about to order the components to build the hardware.

However, a few of the component values seem to be missing. For example L20, C37 and R1 on the RF board are marked as 0 on the PDF schematic, also the values are not in the SCH file.

peterantypas, 2017-11-13:
Just replace them with 0 Ohm bridges.

peterantypas, 2017-11-13:
Also, C20 is not marked, can be anything between 100pF and 2.2nF.

WillWill45, 2017-11-13:
Thank you very much for the quick reply Peter. 👍

Also the logic board SCH file doesn't include any values around the STM32, I'll assume those values will be obvious from the datasheet.

adityadrs, 2017-11-13:
Can all the unmarked caps be of values ranging from 100pF to 2.2nF?
And the inductors in both the boards, what should be the value range?

WillWill45, 2017-11-21:
Hello Peter,

Having trouble working out the component values for the logic board. Any chance you could value them on the eagle file?

Many thanks,
William

peterantypas, 2017-11-24:
I pushed updated schematics with part values I used on my board.

veijavi, 2018-03-14:
Hello

I'm planing to order the components and build the project. Does anyone have ready made part list with digikey or mouser part numbers. It would ease the ordering process a bit.

BR
Vili

djcobylevy, 2018-12-04:
hey veijavi,
could you please share the list you have made?
im trying to build the project but also have some parts missing, such as C39 on RF board.

tnx

Closed 2020-10-07.

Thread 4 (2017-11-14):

Amazing project, but where to get (odd) components

GunnarHolm, 2017-11-14:
Hi !
This looks like a nice winter project to get going before the boating season starts again next summer.
But there are some unusual components that seems difficult and expensive to source one bye one from different ebay shops. Do you have any plans to sell kits with empty PCBs and the STM32F302, Silicon Labs 4463, GlobalTop  LadyBird, NXP BGA2869 and the Skyworks 66100 ?
Best regards,
Gunnar Holm (Stockholm Sweden)

peterantypas, 2017-11-16:
Generally these components are available from DigiKey. The GPS module is still being sold by Adafruit, I believe.

Closed 2020-10-07.

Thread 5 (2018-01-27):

Front end ?

robertobuti, 2018-01-27:
Hello,
i like this project and probably i will make two kit (single borad version) one for me and one for my friend, but i'm not expertise on AIS solutions, so what's about front end display ?
There are compatible software solutions with this project that can be used on tablet or something like it ?
can be connected to Nmea2000 interface to existing system on boat ?

peterantypas, 2018-01-27:
The output is NMEA0183, so it will need some kind of a bridge for NMEA2k. On my boat I pipe this to a Raspberry Pi which is a WiFi access point, and I connect iNavx on an iPad to it for overlaying AIS+GPS on the charts.

robertobuti, 2018-02-01:
ok great, but jut to know, implementation of NMEA2K my be a next SW step to be done ?
I see come commercial converter  from the two standard, are you using one of them con your configuration ?  can you share more detail on access point / NMEA0183 to be used on standard char plotter ?

thanks in advance,
regards

Lin4fun, 2018-02-06:
Hello Robert,
Hello Peter,

there is a library created by Timo Lappalainen which have also a NMEA0182 to NMEA2K gateway.
I am working with this library now for a couple of month I must say that it is genious! You can take a look on his github repository here:
https://github.com/ttlappalainen

In the arduino forum you find the NMEA 2000 Shield here: https://forum.arduino.cc/index.php?topic=50893.0

I ordered your board through OSHPark and they arrived today. so now I am looking for the partlist to order all parts to get it integrated to my NMEA 2000 network on board.

I am looking forward to see it working, thanks for the great job until now!

Closed 2020-10-07.

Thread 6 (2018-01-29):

Crystal Frequency

pggood, 2018-01-29:
What frequency is the Crystal for the processor X1 TXC_7A

rszemeti, 2019-03-17:
30.000 MHz

rszemeti, 2019-03-17:
For the microprocessor, 24.00 MHz,  for the RF stages, 30.00 mhz oscillator.

Closed 2020-10-07.

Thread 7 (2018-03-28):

Board availability

jimarcher, 2018-03-28:
This project looks fantastic! I have ordered boards and reflowed them in my toaster over (now dedicated to board reflow) but these components may be too fine pitch for me to do that. How are you guys making your boards for this project?

Thanks...

junkt1, 2018-12-06:
Where did you order the kit?

rszemeti, 2020-04-25:
Reflow was not a problem, but you need a GOOD stencil to make the paste print, and check the print before you start placing components.   Worked fine for me, no problems so far with the assembly.

Closed 2020-10-07.

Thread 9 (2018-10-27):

AIS preamble

SamSamKhan, 2018-10-27:
Dear Peter,
You have set the PREAMBLE_CONFIG to 0x21 in radio_config_ph.h file which put the si446x to standard preamble mode. whereas the AIS standard requires NRZI coding which led to non standard preamble pattern. could you please explain why?
thanks in advance,
Saman

peterantypas, 2018-10-27:
To the best of my recollection it didn't matter. The SYNC WORD is what the receiver keyed on, and that's set for the NRZI-encoded preamble: 001100110011, etc.

Closed 2020-10-07.

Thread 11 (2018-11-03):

Non standard Preamble

SamSamKhan, 2018-11-03:
Dear Peter,
As you know the Preamble in AIS in 24-bit non standard (1010... pattern), so the AFC and BCR of Si4463 cannot settle correctly as it has mentioned in the application notes. I am wondering if you have achieved good sensitivity? have you tested the sensitivity test or have you compared receive quality with commercial devices like Garmin or Comar?
thanks,
Saman

Closed 2020-10-07.

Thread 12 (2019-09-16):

Always get 0x08 for chip_status.Current when GET_CHIP_STATUS

nazmibojan, 2019-09-16:
Hi Peter,

Such a wonderful project!
But I always get 0x08 after GET_CHIP_STATUS, is it hardware problem for me or something wrong with the code?
I use the board and schematic from your repository.
Thanks.

nazmibojan, 2019-10-02:
I've choosen wrong revision of Si4463. You have to choose Si4463-C2 to make this code works.

Closed 2019-10-02.

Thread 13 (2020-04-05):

2020 Project Status?

ToddG, 2020-04-05:
Peter, this looks like an incredibly cool project. I have a boat, and I'd love to build one of these as the commercial options are expensive, bloated, and gobble up energy.

What's the status of this project?
Have you built and used one, and if so, what has been your experience using it?
Do you want/need contributors to this project? For one thing, a blog, and/or some current documentation might be nice.

So this ticket is really all about asking for a quick refresh of the docs, project status, project needs, etc.

rszemeti, 2020-04-25:
I am just completing the build of mine, I have some spare boards (unpopulated) available.  I may have some spare components (eg the Skyworks switch)  .. I'd like to at least get mine up and running first though.

ToddG, 2020-04-27:
It's a really cool project. I purchased a commercial AIS for my boat. But I think this could be both a great learning platform and a great open source project.

-------- Original Message --------
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

boelle, 2020-07-26:
i did not want to open an issue just to ask this one: but what does it cost to build one myself compared to getting a commercial unit?

rszemeti, 2020-07-26:
The basic cost in components is around maybe €75 to 100 euros, but you will
have to buy some parts in x5 even though you only need x1   You also need
the PCB .. I was able to mix the PCB with others I was ordering so my price
was not too bad, I have some spare PCB now.

You will also need to order a stainless stencil for the solder paste. You
will have difficulty mounting some of the smaller IC without a stencil for
the paste. The radio transceiver chips are quite small to mount, and the
T/R switch is very small (2mm x 2mm, 12 connections)  if you are not
experienced, it will be difficult for you.

I took quite some time to get the software to load and run. I forget what
the exact problem was, but it took a while to find it, I think it was in
the initial clock configuration.   Allow "some time" to get the software
loaded if you are new to the STM32. Maybe a day or two ... maybe more,
depending on your experience level.

On Sun, 26 Jul 2020 at 11:02, Bo Herrmannsen <notifications@github.com>
wrote:

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

boelle, 2020-07-27:
that is not so bad (price)

and i do have experience with SMD and have the tools (dispenser and oven)

mfrostus, 2020-08-29:
Are the hardware components list and schemas on OSH?

rszemeti, 2020-08-29:
They are on GitHub ...

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

peterantypas, 2020-08-29:
Hello all. I have suddenly found my self with spare time on my hands, and I'm thinking about reviving this project, or rather the evolved version of it.

I built the next version of the circuit on my boat (including antenna) and it has been operating for 3 years now. I'd like to start a discussion about the best way to make it available. Here are some basic facts about it (sorry, all the internal photos of it were lost overboard with my iPhone!)

- 1" wide 4-layer PCBA directly attached via SMA connector to custom "flowerpot" antenna, tuned to 162MHz with SWR of < 1.25:1
- Telit SE873 GNSS with ceramic antenna on the PCBA
- Full 2W output, using Toshiba AFTxxxx series RF MOSFET as PA, confirmed range of 10 NM
- Redesigned RX section, easily "sees" targets > 15 NM away depending on mounting height
- STM32L432 MCU with HAL code
- Running entirely from 12V with onboard buck converter and appropriate input filter
- TX burst current supplied by 10mF supercap on the PCBA

The design allows the transponder and antenna to be mounted as one piece somewhere up high, directly onto 1" railing, secured using UV-resistant heat shrink tubing (3 years and counting, still looks great). The 4-wire (phone) cable to the cabin travels inside the railing or mast, until it hits a control circuit where it's converted to USB for feeding into a RPi or some other similar device. I've had great success with 3.3V level UART travelling > 35 feet in twisted pair cable with no issues.

I have often thought about commercializing this, but the amount of regulatory pain here in the US is higher than my threshold (I deal with the FCC as part of my day job).

What if I made this available as a do-it-yourself kit? I think this would allow me to dodge the regulatory reef, but it comes with its own challenges. What would a system like this be worth?

Let's discuss here.

rszemeti, 2020-08-29:
A kit would be OK, but I think without the SMT stencil and the ability to
use a SMT oven, people will struggle.   I still have some spare PCBs if
anyone wants one.

I had some success, my board runs, and I can load software to it that
appears to function, but I've never seen a successful transmission from it
.. I put it on one side.   I found compiling as a non-HAL project to be
difficult, there are errors in the clock configuration in the project as it
stands, so it loads and then crashes. Debugging is dificult in this
condition.   What I did notice is I could successfully use the STM32 cube
programmer to load and run test code perfectly, but the same not the
bootloader ... it took me some time to find the clock config problem.

A kit might be interesting, but I already have large amounts of SMD
components so just a board and some of the harder to find pieces would be
good for me, or I just add a board to my next PCB order. Either is good.
It would be nice to see it make progress again, apart from the one I built,
I am not sure how many others have built one. A kit may improve that
situation, but they will need excellent SMD skills.

On Sat, 29 Aug 2020 at 18:01, Peter Antypas <notifications@github.com>
wrote:

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

peterantypas, 2020-08-29:
Thanks for the feedback. For sure, SMD will be a challenge. I'm thinking of bundling a 95% finished PCBA, the antenna, cabling and control box parts, plus instructions for programming firmware (which will be open source, here on github).These will require significant enough assembly to be considered a "kit" but will still be within the reach of a reasonably tech-savvy person.

marcelrv, 2020-08-29:
That would be really interesting.

As far as I understand a kit can be fairly complete... E.g. I understood the raspberry pi also got started that way (maybe still?). That is also a complete PCB.. just the fact that it was without housing was already enough.

What sort of cost are you expecting.. the cheap Chinese versions start @ 200€ already, can imagine this comes close.
Note have you considered having only the 12v and the nmea connection wireless, e.g. using additional esp32 or similar. E.g. having power already available in the mast, no need to run new wires
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
boelle, 2020-08-31:
a kit would be nice, and all you have to do to make it a kit is for the end user to do something to make it work

Soldering on a smd fuse or power connector would do the trick

A side Q i got in my head is if this could be connected to a chart plotter etc?

As for the hat and all in one idea i would not like that, spec if it means i had to get up the mast to do repairs
and pi's tend to get a corrupt sd card now and then.

rszemeti, 2020-08-31:
Hi Bo,

The basic idea is the "RF Unit" sends back serial data to a small processor
(Pi, Arduino .. whatever) and the small processor then processes the date
from the RF unit and converts/filters it into a suitable format to feed to
a plotter, eg NMEA 0183, NMEA2000 etc

On Mon, 31 Aug 2020 at 20:56, Bo Herrmannsen <notifications@github.com>
wrote:

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

peterantypas, 2020-09-03:
Update:

With the help of a former colleague-turned-consultant (an Apple/GoPro alum), I am finalizing the mechanical aspects of the transponder design to achieve IP68 while still being easy to assemble as a kit.

I have updated the EE design to lower the BOM cost and I'll be validating it next week. If all goes well, I should have the new design + updated firmware posted here within a month.

The kit will most likely become available for sale on tindie.com, but I'm not sure exactly how long it will take. The mechanical design will almost certainly require a custom moulded part, and that process always takes a couple of months or more.

I went sailing today and took a screenshot of the AIS overlay on iNavX. This should give you an idea of the performance.

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

marcelrv, 2020-09-03:
That's great news.
BTW, for the mechanical part, that sounds somewhat complex & expensive. Could you consider this as optional part of the kit.
I can imagine a 3D printed part would also work very fine. I'm using various 3D printed (replacement) parts on my boat with good succes

rszemeti, 2020-09-03:
I'd be interested to know (off list if you like) how you plan to do the
moulding. I have in the past had several projects that could use low volume
injection moulding, however the $30k+ tooling costs has always killed it.
If there is a cheaper/simpler route, I'd be very interested to hear about
it.

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

boelle, 2020-09-03:
> I can imagine a 3D printed part

i would vote for that too, you just have to pick the right filament for the job

rszemeti, 2020-09-03:
I have yet to see any 3D part that is really waterproof.

On Thu, 3 Sep 2020 at 09:42, Bo Herrmannsen <notifications@github.com>
wrote:

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

boelle, 2020-09-03:
it can be if done right

But you need to know what you are doing

boelle, 2020-09-03:
said in other words, the more requirements for the print the less the chance are that it will be done right

easy enough to do cookie cutters etc, but something that can hold pressure etc is a bigger challange

in the case of a boat it also has to be UV resistant or else it will break down the print and it will not be water proof

add on top of that it  has to be chemical proof (salt)

marcelrv, 2020-09-03:
Indeed the material choice is of great importance. This should e.g. not be printed in PLA.
However, in PETG or ABS it should be fairly UV resistant.

Note that exactly the same challenges if you manufacture this as a molded part.

marcelrv, 2020-09-03:
@peterantypas Wrt to the 3D print idea, if I can support your project and provide some printed parts for testing let me know.

rszemeti, 2020-09-03:
Every 3D printed part I have seen to date has been poor, either in surface
finish or brittleness.  That is my experience, and I would not put anything
3d printed on my boat at this time, based on what I have seen so far.

On Thu, 3 Sep 2020 at 10:34, Bo Herrmannsen <notifications@github.com>
wrote:

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

boelle, 2020-09-03:
> Every 3D printed part I have seen to date has been poor

you must have seen everything from cheap 50$ printers to 10.000$ printers

marcelrv, 2020-09-03:
@rszemeti yes, if perfect shiny / smooth is your requirement than indeed 3D print would not suit, at least not without painting.
You can always smooth it by painting.

Having said that, I don't mind the (little) surface roughness of 3D prints, I actually kind of find it appealing.
See below picture (very zoomed in, tip of pen as reference). even in close up you would need to look careful to see the .12mm layer lines.
This is with a $150 budget printer. On 30cm distance I can't see these lines anymore, it looks fully smooth.

Note that even with a moulded part, you need to allow for tolerances. Now you can get to very tight tolerances on moulded parts, but that requires quite an effort on the
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

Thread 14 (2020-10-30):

Switch to a different GNSS module

peterantypas, 2020-10-30:
Telit just confirmed that they're phasing out the SE873 in favor of the SE873Q5. Unfortunately, the Q5 contains a DC/DC switch which literally craps all over the marine VHF band, raising the AIS noise floor by several dB in its vicinity. I have confirmed this with spectrum analyzer and EMC probes as well as an A/B test.

The design will have to change. The good news is that the Teseo and its derivatives should fit, so that's encouraging:

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

Leaving this ticket here for visibility until I resolve this. As always, open to suggestions if you have any.

kagouraki, 2020-10-30:
I just ordered the pcb from JLCPCB. Is there a problem of using the SE873Q5 except of the range loss ?
Thank you very much for everything. It is a awesome project !

peterantypas, 2020-10-30:
There is no other issue with the Telit. I spent 2 years working on a wearable with it, I know this module in and out. It just isn't ideal for this application.

kagouraki, 2020-10-30:
Ok then i will not cancel my order on JLCPCB. Maybe i can still find the old SE873 witch has no range loss.

peterantypas, 2020-10-30:
Not sure where you're located but here in the US Telit products are sold by Symmetry Electronics. They do have a few still in stock.

kagouraki, 2020-10-30:
I am in Greece but i will order from them. They seem the only one to still have them (SE873GNS577R002). I would like to add you in facebook or instagram to talk more about this project if you like.

peterantypas, 2020-10-31:
It looks like ST's Teseo modules lack a front end, which means I'll need an external LNA + SAW filter + matching (which is never 50 Ohms IRL). I'm looking for ways to reduce, not increase BOM count, so I will look for complete drop-in modules (with built-in antennas) that aren't insanely expensive.

peterantypas, 2020-11-01:
I will be building a quick eval board with Quectel's L70 module this week. If it does the business with the existing antenna, I'll design it in and spin a complete board to validate. I have a direct relationship with Quectel and they are growing so fast that they keep spinning up factories, so I'm not worried about availability ;)

peterantypas, 2020-11-03:
Quectel uses a very standard 9.7x10.1 footprint which appears to be mostly compatible with several Mediatek based modules, so we should have a few choices. Hopefully one of those works out:

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

peterantypas, 2020-11-03:
Telit had an "Enable" pin that was instrumental in getting the ROM bootloader to work without interference from the GPS UART. With other modules, this is not available, so my solution was to introduce a buffer:

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

This should work with any module.

peterantypas, 2020-11-05:
Quectel L70-RL in form factor prototype worked indoors. I think the GPS problem is solved.

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

For extra paranoia, I'm going to test the L70-R (with no LNA at the input) to see if it works outdoors. I feel better about not having an LNA really close to the transmitting antenna.

peterantypas, 2020-11-07:
The only funny thing about the Quectel is that is emits this spike as seen with a near field probe:

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

It shouldn't matter for this application. The overall noise floor at 162MHz is where it should be. There is a 20dB gain amplifier at the input, so it lands around -98dBm.

peterantypas, 2020-11-08:
The L70-RL works fine in close proximity to the AIS transmitter, so that settles it as far as the design goes. It will show up on board rev 9.2 once some mechanical design issues have been resolved.

peterantypas, 2020-11-20:
Board 9.3 (not yet published) with Quectel module works OK, pending an actual field test (as in going sailing with it):

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

peterantypas, 2020-11-21:
Board 9.3 is in the master branch and this ticket can be closed.

astuder, 2020-11-21:
Interesting decision to change RX to single-ended and drop the matching network. Did you do any lab tests to verify the impact on sensitivity or does it just work good enough in practice? Not questioning your decision, but I'm an RF n00b and always scared when deviating from the reference design in the datasheet :)

peterantypas, 2020-11-21:
I'm not claiming extensive RF expertise either but I live in the best AIS
lab you can possibly find: Surrounded by water in 3 directions, next to two
major airports and multiple FAA towers, in the presence of VHF television
signals and several FM radio stations, not to mention my neighbors' random
sources of sub-200MHz EMI (s.a. LED lights). This design outperformed
everything else I tried and I've tried a lot of things.

On Sat, Nov 21, 2020 at 12:03 PM Adrian Studer <notifications@github.com>
wrote:

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

astuder, 2020-11-21:
Aka, the proof is in the pudding :) Thanks, I will have to give this design a try myself.

Closed 2020-11-21.

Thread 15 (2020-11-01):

Reduce instructions in bit clock ISRs

peterantypas, 2020-11-01:
There is too much going on in the Receiver::onBitClock() method, which can cause significant delay and loss of bits from the other IC. I confirmed this by removing RSSI measurement and observing an instant boost in message count.

Will need to re-architect firmware to perform a single GPIO read in the ISR and then queue the bit value for processing in thread mode (or RTOS task).

peterantypas, 2020-11-02:
The main culprit is RFIC::readRSSI() which requires a blocking SPI transaction that takes 80us and there's nothing else that can be done about it. Furthermore, AIS being a "hard real time" application means that this logic cannot move to a task.

The total time budget per bit clock IRQ is 1/9600 = 104us.

I'm going to change the way RSSI is measured and evaluated for Clear Channel Assessment.

Only the Transceiver IC will do RSSI measurements, and only when it has a transmission pending. The NoiseFloorDetector and its associated events will be removed. This will eliminate calls to FreeRTOS xQueueSendFromISR() which I have clocked at over 50us and should restore RX packet yield to normal levels.

astuder, 2020-11-02:
Noise floor probably varies a lot based on the local environment, so not sure if calibrating a unit is a feasible approach.

You can configure FRR_A to hold the current RSSI value, see FRR_CTL_A_MODE. The command FRR_A_READ uses a lot less time than GET_MODEM_STATUS. Besides transferring fewer bytes, it responds immediately without having to wait for CTS.

The EZRadioPRO also has a feature to automatically indicate RSSI level with a GPIO pin. You set the RSSI threshold for CCA to go high in MODEM_RSSI_THRESH. You'd still have to periodically measure the noise floor to determine a sensible threshold.

What I did with my receivers is move all SPI commands out of the bit clock ISR. When I need to read the RSSI or switch channels, I set a flag during the bit clock ISR and do the SPI transaction in the main loop. I didn't see any issues with missed bits while a SPI transaction is running - though no RTOS involved in my case.

astuder, 2020-11-02:
Never mind about FRR_A, that's only for latched RSSI, i.e. not useful outside of receiving a message.

peterantypas, 2020-11-02:
Yes, that's the issue. There is no faster path to read RSSI other than GET_MODEM_STATUS. With the receiver I can see why you don't have many real-time constraints, but with the transmitter I do: Transmission has to begin within a few microseconds of CCA or it will go over the slot boundary.

I agree that noise floor should be dynamically inferred, I just have to change how it's done so it does not involve pushing events from an ISR to the main event queue, because for some reason this takes 80us. I'm going to debug the RTOS itself to see how much of that is xQueueSendFromISR() vs my code. I suspect there's too much memcpy() going on ...

peterantypas, 2020-11-02:
The culprit is FreeRTOS. I am going to go back to my original non-RTOS code with a slightly improved ring buffer and give it a try.

peterantypas, 2020-11-03:
The bottleneck proved to be memcpy(). I transitioned back to object pools and queues of pointers and now things are much better. Still, the restarting of RX (which is necessary to take advantage of sync word detection), takes over 180us which is longer than a bit period. I'm going to revise the logic to perform this operation at the very end of the slot boundary where I can afford to drop 2 bits with few consequences.

peterantypas, 2020-11-03:
Looking further into SPI transactions, it seems that the bulk of time is spent waiting for CTS. After initialization, the longest command transmit time I've measured is 52us. The longest response time was 212us. This can absolutely be taken off the "fast path" and reduce time spent in ISR.

Ideally, though, we should never spend more than 52us in an ISR, so we can service the other IC's clock interrupt as well. This will require careful management but it's very doable.

peterantypas, 2020-11-04:
Alright, the bare_metal branch seems very happy now:

- RSSI sampling is done at a low duty cycle and never on consecutive ISRs
- START_RX starts in an ISR and completes asynchronously
- 99.9% of bit clock ISR take less than 97us to complete

There is a very rare case of an ISR clocking at 112us which I haven't been able to explain yet and probably won't bother. I'm going to live with this code for about a week and them merge to master.

peterantypas, 2020-11-04:
I have also confirmed that TX is exactly inside the SOTDMA slot boundary (barely). To buy a little extra margin, the plan is to use a GPIO and the Si4463 hardware-based CCA mechanism in the next board design. This will eliminate 70us of RSSI interrogation in the fast path. There is nothing I can do about the fact that START_TX takes 400us. I have already dealt with this by reducing the number of ramp-up and ramp-down bits in the packet.

FWIW, I have seen all kinds of misaligned transmissions from other boats during the past few years while developing this. Not to mention several malfunctioning class A devices ...

peterantypas, 2020-11-07:
Done. New firmware in master greatly improves RX yield.

Closed 2020-11-07.

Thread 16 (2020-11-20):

Output power calibration

peterantypas, 2020-11-20:
Unfortunately, the current design cannot output a consistent amount of power. I am seeing a significant amount of variance and keep finding myself adjusting the PA bias voltage divider to dial in +33dBm.

So the final (rev 9.4) board will have to incorporate a trimmer in that section like this:

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

The nominal value for R11 is 3K, but I have had to adjust it down to 2.2K or even 1.8K in one board.

This will make it harder for folks to build this board without an RF power meter but I would argue that if you're not properly equipped for this type of work, you should probably just buy the kit when it surfaces.  With the kit, you will know that every board has been programmed, tested and tuned.

peterantypas, 2020-11-21:
I decided against using a manual trim pot, as it is impractical for automated production. For one-off builds, it's better to just try different resistor values for R11 starting with 3K and working downward. The production board will feature an I2C digital rheostat to facilitate automated calibration.

peterantypas, 2020-11-23:
I am planning to complete 5 board builds over the Thanksgiving break (2 already done). If a single resistor value comes close enough to achieving the desired output power on 4 of them, then this will be it and there will be no need for a new design.

rszemeti, 2020-11-24:
I'm ordering various boards for various projects from JLC right now ... do you think 9.3 is "close enough" to be worth ordering a board/stencil set?   I obviously have all the test gear, spectrum analysers, HP power meters etc, and I think enough components left over from the "fullboard" build ..

rszemeti, 2020-11-24:
One question ... is it just choosing the right gate voltage to achieve the desired  quiescent Ids that is the problem, or is it different device gains that need to be accommodated by varying Ids to get the gain required?  Is it variations in the drive level?

One solution would be to use a smaller device and drive it hard into class C to provide a consistent output level.   The same idea could be used to level off the drive levels if it is variation in drive to the final PA.  I've used a "current mirror" technique to auto set a consistent bias point in GaAsFET preamps that works quite nicely, and sets a consistent Ids without the need for a pot, but I don't think it does need a sense resistor in the top of the drain in order to sense  drain current, which would reduce output.

peterantypas, 2020-11-24:
I think 9.3 is great, except for the need to play with R11 to get the right power output. I'm not sure if the variation is in Id or in drive level due to component tolerances. If you have any ideas on an alternate power stage, I'm all ears. I have to migrate away from this MOSFET anyway, as it is EOL now.

peterantypas, 2020-11-25:
Looking further into class C, I think it will be problematic for this application given the increased harmonic output. It was hard enough to deal with the 2nd in an A/AB design.

rszemeti, 2020-11-25:
That's a fair point.  I guess it really comes down to identifying the cause
of the variation ... is it drive levels out of the radio IC .. bias points
in the final OP,   or gain variation in the final output ... maybe just
running the final output hard enough to drive it to the P1dB point?  There
is an auto-bias circuit based on a constant current course I have used on
preamp mosfets, but it would need some sort of sense resistor in the 5V
feed, which may not work for a PA ...

[image: image.png]

On Wed, 25 Nov 2020 at 16:53, Peter Antypas <notifications@github.com>
wrote:

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

peterantypas, 2020-11-25:
I will try to get to the bottom of it over the Christmas break. I plan to build 10 boards between now and then. There's a lot of components between the RF IC and the PA for the matching network and first low pass filter, so even 2% tolerances there could add up. Then I realized I was using 5% resistors for the bias voltage divider as well (oops!). I have 1% on order to try again.

rszemeti, 2020-11-26:
Sounds good.  I might as well add a 9.3 board to my next JLC order then, it
will give me something to build over Christmas ... alongside a 1.8kw LDMOS
amp for 144MHz ..

On Wed, 25 Nov 2020 at 17:22, Peter Antypas <notifications@github.com>
wrote:

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

peterantypas, 2020-11-26:
That should be able to make a fine cup of tea ...

peterantypas, 2020-12-10:
OK, this has been resolved. With R10 at 10K, R11 must be 2.4K. The variance was due to mixing part values by accident. Once I rebuilt the backend section (from the IC output to the MOSFET gate) with all the correct parts, output power variance was less than 1dB across 5 units.

Closed 2020-12-11.

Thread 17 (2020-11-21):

Control box design

peterantypas, 2020-11-21:
I'm going to leave this ticket open as a discussion forum around the control box. This is the unit on the opposite end of the transponder cable. It's not a strict requirement for the transponder to operate, but I have found mine useful over the past 2 years.

I started by designing custom cutouts in a Hammond enclosure and 3D printing it. I expect this process to take a few iterations over a couple of months.

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

I don't intend to make this an IP6x rated enclosure. This unit is supposed to be inside the boat cabin or some other "mostly dry" environment.

The current design features an on/off latching switch, 4 status LEDs, a transmit on/off switch, and plain wire interfaces for 12V input and NMEA+/NMEA- outputs as well as USB. It only works with the Cat5 cable option. To support the 4-wire option, it will need a basic MCU to intercept and interpret NMEA messages, as well as different cutouts, so I will probably end up with two variants.

kagouraki, 2020-11-23:
Hello !
I am a cnc machinist, an electronics hobbyst and a sailor.
I am very interested in your project !
If i can help with design and manufacture of the control box just tell me !

peterantypas, 2020-11-23:
Thanks, I'll keep this in mind. Once I have the design down, maybe you can help me machine the cutouts in the stock enclosures. The stock box is very cheap (under $3), but Hammond wants quite a bit of money per unit to CNC those cutouts.

kagouraki, 2020-11-24:
I will be glad to help ! Just say the word !

Closed 2020-12-16.

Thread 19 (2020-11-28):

Reverse polarity protection is defeated in board 9.3

peterantypas, 2020-11-28:
A mistake in the schematic caused the reverse polarity protection PMOS (Q1) to be bypassed. This will be resolved in rev 10.0

peterantypas, 2020-12-13:
Board 10.0.1 has been posted and resolves this.

Closed 2020-12-13.

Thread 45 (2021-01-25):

Transponder receives its own transmission

peterantypas, 2021-01-25:
This appears to be a regression from earlier board and firmware versions. Need to investigate.

peterantypas, 2021-01-30:
This issue is a symptom of #46

Closed 2021-01-30.

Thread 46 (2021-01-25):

RX performance degrades after running for a few hours

peterantypas, 2021-01-25:
I confirmed it twice by checking the RX status indicator on the boat system. Will need to attach a serial terminal next time to debug further. Power-cycling the system restored things. This is a regression. Board 4.3 worked flawlessly for months.

peterantypas, 2021-01-30:
I have reproduced the bug. It appears to be a regression in the channel-swap logic that occasionally causes the receiver to enter a bad state or continue listening at the same channel as the transceiver.

peterantypas, 2021-01-30:
Just pushed a fix to master. Will keep testing a board overnight, but I believe it's fixed now.

peterantypas, 2021-01-31:
This has been fixed.

peterantypas, 2021-02-24:
This has not been fixed. I have reproduced it with 2 boards now, one on the boat and one running overnight here. Both boards have the same IC configuration: Si4467 for transceiver and Si4362 for receiver.

peterantypas, 2021-02-24:
I have also confirmed there is nothing electrically wrong with the board voltages. The RF switch is in the RX position, the LNA is powered, and messages do get received, albeit at a very low rate. It's as if the ICs have gotten detuned, or sync word detection has been disabled. A reset of the MCU which re-initializes the ICs corrects this.

peterantypas, 2021-02-24:
I have posted a question on the Silabs forums to see if anyone else has encountered this.

peterantypas, 2021-02-24:
I set up a 24 hour A/B test. The only difference between these two boards is that one has 2 x Si4463s, the other has Si4467 and Si4362. Let's see what happens.

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

astuder, 2021-02-24:
Do you restart RX at the end of a packet if there was a valid sync? The receiver switches gears after detecting the preamble/sync and restarting RX is the only way to get out of this mode AFAIK.

peterantypas, 2021-02-24:
Yes, I always do that, but I just noticed I don't log any failures there ... let's see what happens by tomorrow. If it repeats, then more debugging is warranted.

peterantypas, 2021-02-25:
Here we go:

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

The board with 4467 and 4362 is on top, the dual 4463 on bottom.

peterantypas, 2021-02-25:
This is after running for a little over 6 hours. It's perplexing, for sure.

peterantypas, 2021-02-26:
I added an hourly reset for all devices that contain chips other than the 4463. So far it seems to hold well. I'll run this for a few days.

peterantypas, 2021-02-26:
I expanded this to reset the MCU every hour regardless of hardware.

Closed 2021-02-26.

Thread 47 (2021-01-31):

GPS antenna is out of tune

peterantypas, 2021-01-31:
The antenna layout is not exactly ideal and it's no surprise that it's out of tune. Board 11 will incorporate a matching network.

As this plot shows, it's off by 100MHz:

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

peterantypas, 2021-01-31:
This should work better:

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

From module -> antenna we have a shunt 4.7pF cap and a series 3.3nH inductor.

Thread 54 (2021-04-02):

SMA connector missing from BOM

mikkosivulainen, 2021-04-02:
on 10.0 version there is no SMA connector in BOM, or I need new glasses.

peterantypas, 2021-04-02:
This may be true indeed, as I don’t have a part number for them. Any generic SMD edge connector for 1.6mm board will work.

Sent from my iPhone

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

Closed 2021-07-29.

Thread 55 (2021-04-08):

Ais class A

shakibmehr, 2021-04-08:
Is it possible to build a class A ais with this project?

peterantypas, 2021-04-08:
Short answer is ‘I don’t know’. I have not looked into it at all. But I imagine it should be possible to fork and build the SOTDMA reservation mechanism that it requires. Of course, a class A must have a display and a much more  powerful PA.

Sent from my iPhone

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

shakibmehr, 2021-04-08:
Class a is also SOTDMA and its power is 12 watts

peterantypas, 2021-04-09:
It's more than that. A class A must reserve time slots and implement a different set of messages from a class B. It also needs integration with other systems so it can report things like heading and rate of turn.

shakibmehr, 2021-04-11:
Is the device you made SOTDMA?
And can class A be implemented with this device?

peterantypas, 2021-04-30:
It is SOTDMA in the sense that it resolves and conforms to the time slots very well and it doesn't do so based on other transmitters; it does it strictly based on GPS and UTC.

Closed 2021-07-29.

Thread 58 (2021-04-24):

Build it from modules

muebau, 2021-04-24:
Hi,
when I saw this project for the first time I ordered some modules to build a simple AIS from modules. The parts arrived mid 2020 but the project made a lot of progress and changed a lot. As the project is a little bit on hold I wondered if I could use the current source code and build a poor mans versions.
It would be bulky but would give me a simple AIS receiver. The transmission power I to low but might be better than no transmission at all.

What do you think?

The modules:

GN-801 GPS
https://www.aliexpress.com/item/32951163811.html

SX1278 170mhz 1W
https://www.aliexpress.com/item/33044516902.html

SI4463 170Mhz 500mW
https://www.aliexpress.com/item/32802449702.html

Stm32f302cbt6
https://www.aliexpress.com/item/4000906426082.html

SMA cable Y pigtail RG316
https://www.aliexpress.com/item/1005001693573105.html

JohnDevine, 2021-04-25:
I am very interested too. Any way I can help? I build quite a lot of IOT gear and code in C++ and node red. I have a 3d printer as well. We also have a yacht that the lightning has trashed our AIS transponder ... so I have motivation :)

Closed 2021-09-03.

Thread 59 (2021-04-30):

Set Ais info

shakibmehr, 2021-04-30:
How to set Ais information(MMSI, ......)?

peterantypas, 2021-04-30:
You will need to establish UART connection. First, send the "cli" command. If the UART is working, you should see the board reboot into CLI mode with no NMEA stream. This will make it easier to do this.

Here is a sample command:

`station 987654321,NAUT,,37,0,0,0,0`

I haven't written a document for this, look in CommandProcessor.cpp to see how the arguments are parsed:

Boat type is an enumerated value defined in the AIS spec.

```
     /*
       * The station command format is:
       * station mmsi,name,callsign,type,len,beam,portoffset,bowoffset
       */
```

shakibmehr, 2021-04-30:
Tnx.

peterantypas, 2021-07-29:
Closing, since this is out of scope for MAIANA.

Closed 2021-07-29.

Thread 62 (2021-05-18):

Help

david-522, 2021-05-18:
Very nice Job. I am trying to build the project(firmware folder) in eclipse mars.2 DS-5 Professional Edition
Version: 5.26.2.  I just downloaded the eclipse  and it dose not show any toolchain in tool chain editor to select.  I keep getting this error: make: *** No rule to make target 'all'.  Stop.
I tryed to add ARM plug in but I could not do it.
How could I compile and build the project for Arm processor.

Thanks.

peterantypas, 2021-05-18:
Why such an old version of Eclipse? I would start here:

[https://www.eclipse.org/cdt/downloads.php](https://www.eclipse.org/cdt/downloads.php
)

peterantypas, 2021-05-18:
Also, after you install Eclipse CDT (not the Java one), you must still install this package:

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

david-522, 2021-05-19:
Thank you very much Peter. That was very helpful. the project is build completely now. I am not able to Generate Hex file .  is it necessary to have hex file or just elf format will be fine.

Regards,
David.

peterantypas, 2021-05-21:
This is often an issue with plain Eclipse. I find that I need to add those rules explicitly.

First, configure the build page for outputting a raw binary (not hex). Then do this:

![Uploading Screenshot from 2021-05-21 15-37-35.png…]()

david-522, 2021-05-22:
Thanks Peter. I really love this job you did.I am using STM412 and  I build the project with eclipse and also uses J-Flash software to load the elf file into the micro. I send Cli command  but I dont get any reaction. if it is possible for you Please give me your email then I will send you the elf file that I make. I will appreciate if you take a look at it.

peterantypas, 2021-05-22:
I've seen this on occasion too, what happens when you powercycle/reset and try again? Also, can you confirm the UART signal is getting through? The test pads for the UART are here:

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

david-522, 2021-05-24:
Thanks for the Advice. I have checked the UART and it is working OK. I wrote a code in keil and looped the send and receive pins.
When I rest the board I dont see any reaction. cli command do nothing So I guess the elf file that I made is not OK. Is it possible for you to send me your elf file so I could check it on my board. I am very interested to so how it works.
d.zeinali.n@gmail.com

Thanks,
Regards.

peterantypas, 2021-05-24:
Is your terminal sending CRLF at end of line?

Sent from my iPhone

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

peterantypas, 2021-08-04:
@david-522 did you ever resolve this?

david-522, 2021-08-08:
Thanks for asking. Nothing actually. could not get any reply.

peterantypas, 2021-08-08:
What board revision did you use? I can try sending you a binary to flash into it directly.

david-522, 2021-09-28:
it is 10.0

peterantypas, 2021-09-28:
Try this (gunzip first)
[maiana-transponder.bin.gz](https://github.com/peterantypas/maiana/files/7245425/maiana-transponder.bin.gz)

peterantypas, 2021-09-28:
Also, you may want to replace R1 and R2 with 0 ohm bridges and lose the Zeners next to them just in case they're interfering ...

Closed 2022-05-24.

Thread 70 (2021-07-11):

Incorrect bit padding in NMEA output

peterantypas, 2021-07-11:
For certain single frame messages, the NMEA encoding is not strictly correct, as it lacks the "padding" information at the end.

Example:

!AIVDM,1,1,,B,H5NThl1=LTIB0pE=<0000000000,0*5D

Even though most clients will process this message correctly, an "anal" AIS parser will reject it for having the wrong number of fill bits. In this particular case, the package is 27 AIS bytes long, so it must have 2 bits of padding in order to be a multiple of 6.

The correct encoding is:

!AIVDM,1,1,,B,H5NThl1=LTIB0pE=<0000000000,2*5F

The bug is probably in NMEAEncoder.cpp, which incorrectly assumes that single frame messages are always zero padded:

        if ( numSentences > 1 )
          {
            if ( i == numSentences )
              sentence[k++] = '0' + fillBits;
            else
              sentence[k++] = '0';
          }
        else
          {
            sentence[k++] = '0';
          }

peterantypas, 2021-07-11:
This bug does not seem to affect iNavx or OpenCPN. But it does affect applications relying on libais (and possibly others I can't test).

One possible symptom: Message 24 part A may not be processed at all, so Class B vessel names will not appear on the display.

peterantypas, 2021-07-11:
This fixes it:

  if ( numSentences > 1 )
        {
          if ( i == numSentences )
            sentence[k++] = '0' + fillBits;
          else
            sentence[k++] = '0';
        }
      else
        {
          sentence[k++] = '0' + fillBits;
        }

Closed 2021-07-14.

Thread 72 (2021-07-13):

TX switch may prevent transponder from booting

peterantypas, 2021-07-13:
The current design (including board revs shipped in the kit) directs the "TX_OFF" signal to the GPIO PA12. This was an unfortunate choice, as it turns out, because this pin is USB D+ and the effect of the "TX off" setting is for it to be pulled down to GND hard via a buffer MOSFET.

This causes some boards to hang and draw a significant amount of current during POR. But not every board does this.

The best workaround is to always keep the breakout switch to "TX on" position during power-up.

gah67, 2021-07-14:
I was just looking at the NMEA0183 breakout schematic to see if a capacitor could be added to make an RC circuit to delay the +5V signal and I have a query - isn't the 'TX_DISABLE/3.1B' on the 'wrong' side of R9? Where is is is not current limited is it??

----- On 13 Jul, 2021, at 20:54, Peter Antypas ***@***.***> wrote:

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

> The current workaround is to always keep the breakout switch to "TX on" position
> during power-up.
> Even the latest board (10.9) has this issue.

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

peterantypas, 2021-07-14:
R9 was there to prevent a floating signal during post-SMT testing (prior to soldering the switches). But the circuit has to change now to introduce an RC delay. Even a very short (200ms) delay seems to work when I test this manually.

peterantypas, 2021-07-14:
So the short-term solution is I redesign both the USB and NME0183 breakouts. I will email the folks who bought kits (there's quite a few already) and explain.

peterantypas, 2021-07-14:
The NMEA2000 breakout contains a GreenPAK. It's trivial to add a delay for TX control in there.

peterantypas, 2021-07-14:
I can validate this by reworking a USB breakout board. I will cut this trace on the bottom and scrape solder mask to make an RC delay.

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

gah67, 2021-07-14:
That's a very handy via!

----- On 14 Jul, 2021, at 16:37, Peter Antypas ***@***.***> wrote:

> I can validate this by reworking a USB breakout board. I will cut this trace on
> the bottom and scrape solder mask to make an RC delay.

> [
> https://user-images.githubusercontent.com/1565933/125650364-57cc9b71-a365-41fe-b3d8-a25ec56d657f.png
> ]

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

peterantypas, 2021-07-17:
I have confirmed that all STM32L4x series MCUs drive PA12 high during reset, and shorting it to GND causes all kinds of problems. Time delay is one possible fix, but a better fix is to introduce the right pull-down resistor value to limit that inrush current during bootup. Long term fix is to redesign the transponder board.

peterantypas, 2021-07-18:
Turns out that this is more of a POR glitch:

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

Yellow is NRST, purple is PA11, blue is PA12, green is BOOT0.

peterantypas, 2021-07-18:
PA12 wants to rise above 2V during power-up. But this condition expires withing 400us so a delay will take care of it.

peterantypas, 2021-07-18:
Alright, 10K + 1uF RC delay took care of this. All breakout boards have been redesigned and are in fab.

Closed 2021-07-27.

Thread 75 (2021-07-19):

USB needs galvanic isolation

peterantypas, 2021-07-19:
When a USB cable is plugged into any breakout, the CH340N IC is on and presents 3.3V at both its TX and RX pins, regardless of the status of the remaining voltage rails.

This means that the a weak USB voltage (which is regulated to ~3.6V via a Zener) leaks into every IC on every board that has a galvanic, direct or indirect connection with the TX/RX pins. This includes both the remote transponder board (in the antenna housing), as well as the local MCU in the NMEA2000 adapter.  The end result is that approximately 2V presents itself on the main transponder 3.3V rail, as well as the local board's 3.3V rail, both of which should be at zero.

This is not ideal and it should be dealt with, as it can cause some pretty nasty power-up glitches under the right (or rather "wrong") conditions. An added side effect is that the USB and NMEA0183 breakouts can appear to be "on" with their LEDs dimly lit due to backpowering, when in fact they are not.

peterantypas, 2021-07-19:
For the USB and NMEA0183 breakouts, the new design is in fab and it adds a tiny GreenPAK (SLG465110V):

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

This works great and keeps the cost super-low, but it has one negative side effect, which is the additional requirement for GreenPAK development and programming.

peterantypas, 2021-07-20:
In the NMEA2000 breakout, 2 GreenPAK ICs are necessary: The above buffer plus a UART multiplexer / DFU manager.

peterantypas, 2021-07-27:
This has not been resolved. It needs a different approach.

gah67, 2021-07-27:
Would the 'proper' way be opto-isolation of the CH340 outputs? as that could also remove the fact that you are connecting the gnd of the laptop (or other eqmt) via USB to 12v GND which may (or may not) be at the same potential.

peterantypas, 2021-07-27:
Yes, we'll definitely need isolation. I have a Chinese chip I bought from LCSC for a different project years ago, I'll give it a try.

peterantypas, 2021-07-27:
This is it: https://datasheet.lcsc.com/lcsc/2001070531_2Pai-Semi-%CF%80122U31_C471590.pdf

peterantypas, 2021-07-27:
It worked. But now, every breakout has to migrate to this configuration ...

peterantypas, 2021-07-27:
Done. All breakouts redesigned with this USB section and sent to the fab.

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

peterantypas, 2021-08-04:
This has been resolved with the new designs.

Closed 2021-08-04.

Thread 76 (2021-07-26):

Allow configuration of display & DSC bits

sivu, 2021-07-26:
The vessel might have a separate VHF DSC/AIS receiver that has a display and supports DSC, so advertising them should be configurable in message 18

peterantypas, 2021-07-26:
I believe this flag in message 18 indicates whether the transponder itself is equipped with a DSC receiver for frequency management. Could be wrong, of course.

sivu, 2021-07-26:
I think it doesn't matter if the display/dsc is a separate physical device if they both operate under same MMSI?

peterantypas, 2021-07-26:
Look at the fields in the message descriptor here:

https://www.navcen.uscg.gov/?pageName=AISMessagesB

and here:

http://vislab-ccom.unh.edu/~schwehr/software/noaadata/ais-messages/ais_msg_18.html

What do you make of these? To me, all those flags in that section indicate whether the unit can be switched outside of the default AIS channels, via message 22 and DSC transmissions.

Can you locate a more thorough explanation?

sivu, 2021-07-26:
I checked them before and saw that the description speaks of "this device". But if I have two devices right next to each other and the other has display and DSC, (also AIS receiver but that is irrelevant) and the other is sending AIS class B messages, for all intents and purposes they are basically the same device?

peterantypas, 2021-07-26:
Not from the AIS perspective. The question this flag answers is:

"Does this unit contain either a dedicated or time shared DSC receiver so it can listen for frequency management messages on channel 70 and thus change its frequency of operation?"

The answer for MAIANA's current design is always "no".

peterantypas, 2021-07-26:
Here is a bit more context (this is a length doc):

https://www.navcen.uscg.gov/pdf/AIS/AIS_ChMgmt_(view%20bookmarks).pdf

sivu, 2021-07-26:
I understand that from MAIANA's point of view. But like I said, if the vessel has a separate receiver that fulfils that requirement for the same MMSI, MAIANA should be able to be configured to advertise it.

They are in the same vessel, using same MMSI.

If for some reason MAIANA had two different microcontrollers in separate PCBs, other dedicated for DSC and other for AIS, would it set the bit on? I think yes.

In my point of view what I'm asking is exactly the same, the only difference is that the microcontrollers just happen to be physically located in different case / PCB.

peterantypas, 2021-07-26:
In order for this flag to be "yes", MAIANA should have:
- A built-in DSC receiver tuned to channel 70 (or figure out how to do with one of the Si446x ICs)
- The ability to decode frequency management messages on that channel
- The ability to automatically switch its own frequency of operation (both RX and TX) in response to that message while operating in the regions described in those frequency management messages

Are you saying that you plan to augment its functionality with this capability based on your existing setup?

sivu, 2021-07-26:
No, I am saying that I already have a device that has:

1. DSC receiver tuned to channel 70
2. The ability to decode frequency management messages on that channel
3. The ability to automatically switch its own frequency of operation (both RX and TX) in response to that message while operating in the regions described in those frequency management messages

What the device is not doing is sending AIS Class B messages, which is the job of MAIANA.

peterantypas, 2021-07-26:
OK, now I get it. Still though, MAIANA is not capable of automatically (or manually) switching its operating frequency right now. So even though it might advertise the capability you're proposing, it will keep operating at the default channels anyway. Now, if you want to implement a mechanism by which you can use your other AIS receiver to control MAIANA's operation, then that's interesting.

sivu, 2021-07-26:
> Now, if you want to implement a mechanism by which you can use your other AIS receiver to control MAIANA's operation, then that's interesting.

I was thinking about this (and also to implement a parser for receiving GPS / heading related NMEA messages), but instead of USB I would rather use the nmea2000 interface so I'm waiting for that.

peterantypas, 2021-07-26:
First N2K boards should be coming this evening, so I will know by tomorrow if it's finally ready.

That said, the N2K code (which I haven't released to Github yet) does not register as a consumer for any N2K messages, it's only a node, so that would need to be changed for bidirectional interaction. Would this be done using a custom PGN? I'm not aware of any AIS frequency management PGNs.

sivu, 2021-07-27:
Yes, custom PGN would be the way to go

sivu, 2021-07-27:
but in any case, the display bit should be straightforward and it would be just enough to set it to user configurable.

peterantypas, 2021-07-27:
Agreed on the display bit

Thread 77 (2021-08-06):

Add hardware based mechanism to prevent runaway transmission

peterantypas, 2021-08-06:
Currently, if anything happens during transmission that causes firmware to stop executing or jump to the ROM bootloader, the most likely outcome is that the transceiver IC will remain in direct TX mode, clocking a constant bit value (probably 0), while transmitting indefinitely.

There needs to be a hardware based mechanism to shut down both RF ICs during reset. Perhaps pullups on their SDN pins?

peterantypas, 2021-08-06:
RF MOSFET bias will fall to 0V, powering off the PA.

Closed 2021-08-06.

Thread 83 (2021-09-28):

Problem with programming the MCU

ali90reza, 2021-09-28:
Hello. At first I have to thank you for this repository and for your efforts.
I built and assembled your hardware and then I tried to compile the firmware.
I was able to install required toolchain for compile project in Eclipse after many attempts. I installed 2021-9 version of Eclipse IDE for c\c++ developers. Then I installed CDT and "GNU MCU Eclipse plugin" from "http://gnu-mcu-eclipse.netlify.com/v4-neon-updates".
Then I installed latest version of arm-none-eabi-gcc from developer.arm.com.
After that I open your project in Eclipse (application directory in legacy directory, Eclipse detected it as an arm project with this name: ais_transponer)
Then I chose "CDT internal builder" as current builder in "Toolchain Editor" in properties menu of the project.

Finally I build the project and I get .elf output file. I set some settings in properties menu of the project and I get .hex output file too!

I program both of files (.elf and .hex) on the hardware with j-link programmer (with j-flash software) and st-link programmer (with st-link utility software).

The microcontroller detects and programs very well, but unfortunately I did not get any sign that the program is working.

So I tried to write a simple blinking program in Eclipse. I wrote that and build it. Then I program .hex file on my stm32f4-discovery board. But unfortunately I did not get any response.

So what should I do at this step? How can I write a simple program in Eclipse and compile it?
And which programmer and software should I use to program the output of Eclipse?

Thanks very much.

Closed 2022-05-24.

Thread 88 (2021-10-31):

mSlotNumber

chumikov2005, 2021-10-31:
Hello Peter!

Thanks a lot for your project! This is very interesting to me and I'm trying to figure out in detail how it all works. Please tell me how to calculate the slot number in this line of code:

// To keep things simple, we only start the AIS slot timer if we're on an even second (it has a 37.5 Hz frequency)

mSlotNumber = (mTime.tm_sec % 60) * 2250; // We know what AIS slot number we're in

For example, if the current second is valid 10, then the slot number should be 10 * 37.5 = 375.

But if you substitute the value 10 in your formula (mSlotNumber = (mTime.tm_sec % 60) * 2250), then we get the value of the slot 22500, but this value should not be as the slot numbers are from 0 to 2249. Please help me figure it out.

Thanks!

peterantypas, 2021-10-31:
This is indeed a bug but it doesn't have real world consequences, that's why it stayed under the radar for so long. The slot number isn't really used anywhere. Nevertheless it is still a bug.

peterantypas, 2021-10-31:
@chumikov2005 do you want to fix and send a PR?

chumikov2005, 2021-10-31:
I don’t know how the formula for calculating the slot should look like ... Maybe so - mSlotNumber = (mTime.tm_sec% 60) * 37.5; 19:47, 31 октября 2021 г., Peter Antypas ***@***.***>:
@chumikov2005 do you want to fix and send a PR?

—You are receiving this because you were mentioned.Reply to this email directly, view it on GitHub, or unsubscribe.Triage notifications on the go with GitHub Mobile for iOS or Android.

-- Отправлено из мобильного приложения Яндекс.Почты

peterantypas, 2021-10-31:
Correct, but only if the second is even. Do nothing for odd seconds.

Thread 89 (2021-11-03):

MAIANA needs its own bootloader

peterantypas, 2021-11-03:
The ROM bootloader built into the STM32 MCU has no means of verifying the integrity of application firmware. It simply jumps to 0x08000000 (flash base) if the first 8 bytes contain a valid stack pointer and program counter. So if a previous firmware update failed mid-flight, but the first flash page looks valid, then the MCU will start executing a corrupt application. This will almost certainly brick it.

This presents a real risk for a device like MAIANA which is out-of-reach. If this were to happen, the only way to rescue the unit would be to disassemble it and attach an SWD programmer.

The solution to this is to introduce a *minimal* bootloader which only performs firmware integrity checking. This program will occupy the first page of flash at 0x08000000, so it will be the first block to be erased and flashed during an update. The  page will also contain the metadata for the actual firmware image (address, size, checksum) so it will be completely self-contained.

During reset, this bootloader will check for the presence of a valid application firmware image. If the image passes the integrity check, then it will jump to it. If not, then it will jump to the ROM bootloader for another firmware update. This way, if a previous firmware update failed halfway through, the next reset will always enter firmware update mode rather than execute a corrupt application.

muebau, 2021-11-03:
Will this minimal bootloader be written once and most likely newer written again or will it be written every time a new MAIANA firmware update is done?

If there would be a way to only write the memory pages of MAIANA the bootloader has now risk of being corrupted in other case the critical memory of 0x08000000 could become corrupted even if very unlikely because of the small size, simple functionality, etc. .

peterantypas, 2021-11-03:
That's entirely up to us to define. The ROM bootloader can erase and write any address in flash, so we can arbitrarily push application firmware to 0x08000800 or even higher. Additionally, we can also write protect page 0 via option bytes. So we can actually have a one-time write of that page with this basic bootloader, but then we can never change it again either.

muebau, 2021-11-03:
Some systems employ a A/B partition scheme to make sure there is no way to flash anything without a way back to some working code. I can't think of a trick to do that in MAIANA except with some watchdog or physical switch to choose the "other" bootloader.
Anyway this way it would be save to flash bootloader B from bootloader A and reboot into bootloader B. If some sort of verification (watchdog, signature, etc.) fails the next boot would go again with bootloader A else A could be flash as a next step. I think its clear.

The other thing could be a switch to decide which bootloader will be used. I think there is no 'free' switch for the boot process, is it?

peterantypas, 2021-11-03:
The STM32 platform doesn't support such a scheme, as there is no hardware "switch" to force booting from an address other than 0x08000000. A software bootloader at that page is the only way to do this.

That, you can't just deploy a firmware binary at any arbitrary address in flash; it has to be _linked_ for that address. And that makes an A/B scheme impossible.

peterantypas, 2021-11-03:
I think the immutable bootloader at flash page 0 is the best option. The question now is how and where do we write firmware metadata (address, size, checksum) for the bootloader to pick up and verify. It has to be in flash, as the bootloader will not have any peripherals such i2c initialized (code won't fit otherwise).

I'm leaning toward dedicating flash page 1 (0x08000800) to that metadata and linking binaries to start at page 2 (0x08001000). Under this scheme, page 1 would be erased first and written last, only after the entire new binary has been flashed. Any corruption of that page will just trigger firmware update again.

I'm open to other ideas as well.

peterantypas, 2021-11-03:
There is another way to achieve the desired effect: Redesign the hardware to allow the user to force firmware update upon power-up. This can be achieved by manipulating the BOOT0 pin which is currently just a test pad for the jig and it's not exposed outside the main board (there are no more signals left on the Cat5 to wire it either).

This could be done by adding a GreenPAK to the board which monitors the TX switch and counts the number of edges in a given time period. To force a FW update, the user would need to cycle the TX switch on/off very quickly a few times, then the GreenPAK would force a boot into DFU mode in the same way it's done inside the NMEA2000 adapter right now.

Under this scheme, there would be no need for any bootloader and firmware would remain as is.

peterantypas, 2021-11-06:
A simpler way to achieve "atomicity" in firmware update is to erase page 0 immediately and write it last. If something breaks in the interim, the system has no firmware as far are the ROM bootloader is concerned, so it will enter DFU mode upon reset.

peterantypas, 2021-11-09:
Done. Tested it multiple times, killing power during the update. Rebooted into DFU mode every time and was rescued.

peterantypas, 2021-11-14:
After multiple users in the field reported problems with the built-in STM32 bootloader and using STM32CubeProgrammer, it is now clear that this is not a good choice. MAIANA will need to have its own bootloader.

peterantypas, 2021-11-15:
The bootloader does exist. I used it for my original test systems on my boat, so it has been exercised sufficiently. Time to dust it off!

peterantypas, 2021-11-15:
Rescue mode verified on 2 different board revisions. Also, the LEDs are used to indicate DFU status which makes troubleshooting a whole lot easier.

peterantypas, 2021-11-26:
The new bootloader has been released under FW 4.0.0 and OpenPlotter integration is complete as well. Closing.

Closed 2021-11-26.

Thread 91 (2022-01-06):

wxPython based GUI utility for configuring and maintenance of the unit.

mgrouch, 2022-01-06:
wxPython based GUI utility for configuring and maintenance of the Maiana AIS unit.
Forms can be easily designed using wxFormBuilder (included in bareboat necessities OS ver >= 2022-01-04)

There is something in openplotter which is not standalone and tightly coupled with OP.
(So it can't be used as-is by any generic unix distribution)

Thanks!

peterantypas, 2022-01-06:
Yup, on the roadmap.

Sent from my iPhone

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

sailoog, 2022-01-07:
Yes, openplotter-maiana app is not just a GUI to occasionally configuring and updating a MAIANA devices but a full integration with Signalk K and OpenPlotter notifications and IoT systems. You can even configure the device on the fly without taking control of the serial port for example enabling/disabling transmission.

But it would not be difficult to adapt this GUI to work standalone, you should just remove some dependencies, some daemons and you are done. It is pure wxPython, the GUI is quite simple so no need of wxFormBuilder. Let me know if you need help with this.

peterantypas, 2022-01-07:
I’ve built wxPython apps before (including native executable packaging for Windows and Mac).

But yeah, it might be easier to fork your code and strip stuff out. I’ll take a look.

Sent from my iPhone

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

peterantypas, 2022-01-07:
I need to do this regardless for FW updates outside of OpenPlotter.

Sent from my iPhone

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

peterantypas, 2022-02-03:
Version 0.1 of a standalone wxPython app is in https://github.com/peterantypas/maiana/tree/master/latest/Apps/maiana-update

No native executable packaging yet.

mgrouch, 2022-02-03:
Nice!
As a someone with plenty of experience designing UI forms, I have one small
comment:

Labels of input fields should be right aligned next to the input field.
Use flag wxALIGN_RIGHT
It's much easier to read

(Most form designs I see are doing it wrong, by left aligning labels)

mgrouch, 2022-02-07:
Does it need to be run as root or a user can be just a member of certain groups?
Which groups?

Thanks

gah67, 2022-02-07:
As it is accessing a serial port it is usually wheel or dialout depending on the distribution

----- On 7 Feb, 2022, at 18:27, Mikhail Grushinskiy ***@***.***> wrote:

> Does it need to be run as root or a user can be just a member of certain groups?
> Which groups?

> Thanks

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

Closed 2022-02-21.

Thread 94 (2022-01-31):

maiana setup with extisting VHF antenna

zjttoefs, 2022-01-31:
If the boat already has a VHF antenna at the mast head, is it possible/sensible to use this instead of the bundled antenna?

Having two antennas up there would cause some interference, I would guess and it is extra wiring hassle.

kagouraki, 2022-01-31:
You can use the vhf antenna on the mast.
You will need something similar to these ones.
https://www.milltechmarine.com/Antenna-Splitters_c_19.html

zjttoefs, 2022-02-01:
Great! Thanks for the quick response.

Closed 2022-05-24.

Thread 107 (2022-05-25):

Board 10.5 is not transmiting

kagouraki, 2022-05-25:
Hello Peter,

I bought a kit board 10.5 with nmea183 breackout board last summer but i havent used it yet. Now i am trying to make it work. I assembled everything and i am recieving AIS signals and gps is all working. My problem is with the transmission. I programmed my Station data. The string i sended is this one : station 239108400,AIDA,SY7899,36,12,4,0,0
It is programmed probably because i see the TX led blinking once in a while.
Is there a command to send to test the transmission? I have a chinese clone spectrum analyzer but i cant take it with me and im my garage i dont get gps signal for the board to transmit. I dont have another AIS reciever to check. I see in marine traffic. I had it on on a trip with marine trafic coverage for two hours but i was not on marinetraffic.

How should i procceed ?

Thank you !

peterantypas, 2022-05-25:
If you see $PAITX sentences in the NMEA output and the TX LED blinks momentarily, then it's transmitting. Another AIS receiver is really the only reliable way to verify though. MarineTraffic isn't 100% reliable from experience.

peterantypas, 2022-05-25:
I'm not sure how old the FW is on your board, but there should be a "tx test" command which will generate a 1-second randomly modulated signal on a random channel. You can use a spectrum analyzer to capture it, but you'd better make sure you have a lot of attenuation as you could easily fry its front end with +33dBm. Even my HP8563 doesn't tolerate this input level.

kagouraki, 2022-05-25:
Ok i will try with montesier hat and report back. I see the $PAITX sentence and led blinks. Give me an hour i will test it now. Thank you for your immediatly response.

kagouraki, 2022-05-25:
Sorry took longer than i was hoping.
You can close this Issue. The unit is transmitting. Marinetraffic SUCKS.
By the way. The icon was yellow on opencpn and never turned green.Also the name was not displayed. The units where 3 meters apart. Is this normal ?
Also the flag was Great Britain. How do i change it to Greece?

peterantypas, 2022-05-25:
The static reports are transmitted every 5 minutes. Did you wait long enough?

kagouraki, 2022-05-25:
Yes. I was about 20 minutes there. Is there a way to change the flag ?

peterantypas, 2022-05-25:
There is nothing on the AIS side that controls "the flag". That's OpenCPN
interpretation of MMSI

On Wed, May 25, 2022 at 2:48 PM Koretsis Georgios ***@***.***>
wrote:

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

kagouraki, 2022-05-25:
Perfect. I had a random number. Thank you peter ! Goodnight. Or day in America 😅

Closed 2022-05-30.

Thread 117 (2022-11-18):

LC79H?

JosefWN, 2022-11-18:
Hello Peter, really cool project!

Have you seen the new LC79H from Quectel? It seems to be in the same price range as the one you are using: https://www.quectel.com/product/gnss-lc79h

With it you would have dual-band L1/L5 and could go from an accuracy of 2.5m CEP to 1m CEP, seems to slice the power consumption in half compared to your current GNSS module as well. I'm not an electrical engineer, but it's the one my company was recommended when building something of similar nature.

peterantypas, 2022-11-18:
The L76-L has a built-in SAW filter and LNA. It's optimized for a direct connection to a well matched passive antenna.
The L79X series is optimized for an active front end with external LNA + SAW filter. In addition, they're 1.8V devices only so I would have to add an LDO and a level shifter. Finally, they operate at 115200 bps, so the firmware would have to figure out that part.

Is it worth looking at? Maybe, but I'd like to hear from more folks.

peterantypas, 2022-11-18:
There are two variants of this module and the one in stock is not optimal for a passive antenna design. It needs an xternal front end (LNA+SAW) plus it only works at 1.8V so the HW design would have to change substantially.
Is it worth it? Maybe, but I'd like to hear from more folks.

JosefWN, 2022-11-19:
Ah, gotcha. Sorry for the stupid question: is the passive antenna requirement a consequence of the tight form factor or to keep the power consumption down?

Closed 2024-01-09.

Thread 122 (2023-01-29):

ESP32 as a wifi gateway for NMEA2000

factoidforrest, 2023-01-29:
Hi there, sorry for the off topic issue but I wasn't sure how to reach you @peterantypas

I'm wondering if you've given any thought to using an ESP32 as an NMEA gateway. It seems like a simple and obvious choice given the 3.3v logic, great library support, great wifi and Bluetooth performance, and low power usage.

Do you have any input for me before I start a project like that? I don't know much about the NMEA2000 protocol, or the protocol used by wifi gateways. Hopefully it is just the NMEA data over a socket, or something.

Thanks!

peterantypas, 2023-01-31:
ESP32 as a gateway for NMEA0183 data is under way and it's going to be part of the "portable" MAIANA version. You can find it in the "wifi" branch of this repository, although it's probably not going to live here permanently.

ESP32 as a gateway for NMEA2000? What exactly would it be? A generic CAN<->IP bridge?

jafrado, 2023-01-31:
Use NMEA over UDP
http://stripydog.blogspot.com/2015/03/nmea-0183-over-ip-unwritten-rules-for.html

Drone software already does the above. Simple to write a framer. Wireshark
is a simple way to debug.

On Tue, Jan 31, 2023 at 12:11 PM Peter Antypas ***@***.***>
wrote:

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

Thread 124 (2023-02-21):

Trying to re-create custom Maiana AIS Rx

handiko, 2023-02-21:
Hi all,

I'm in the middle of re-creating Maiana as a custom AIS Rx.
My hardware is consisting of STM32L432KB, Si4463, 30MHz xtal for silabs, EEPROM, without GPS, and without TX amplifier chain.
The schematics are attached
[Schematic_AIS Rx STM 4463_2023-02-21.pdf](https://github.com/peterantypas/maiana/files/10790678/Schematic_AIS.Rx.STM.4463_2023-02-21.pdf)

I'm using firmware from https://github.com/peterantypas/maiana/tree/master/latest/Firmware/Transponder "L432-NewBreakouts".
I've been successfully flash the firmware.
On start-up, the receiver puts out 3 sentences on serial:

$PAISYS,11.x,4.1.0,,STM32L432,1,051
$PAISTN,0,,,0,0,0,0,011
$PAITXCFG,1,0,1,0,0*0A

But nothing else. I have a dummy AIS Tx to test my other AIS receiver, but not been received by the maiana rx. The dummy AIS Tx was always received and decoded by my other AIS Rx.
I probed the SCK, MISO, and MOSI lines between the MCU and the silabs ICs, and there is activity on the start-up (or after reset). No further activity afterward.
I probed the TRX_IC_DATA, TRX_IC_CLK, RX_IC_DATA, and RX_IC_CLK lines, no activity at all.

Are there some steps I missed?

Thank you all.

Regards,
Handiko

s991116, 2024-10-19:
Hi @handiko
Did you succeed recreating the AIS Rx?
I am considering recreating the project myself.

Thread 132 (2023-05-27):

Contents of nmea messages

zjttoefs, 2023-05-27:
I am doing initial testing of my unit and the AIS information that OpenCPN is displaying has location, course, heading, rate of turn, speed, class, flag and MMSI. It is missing the vessel name, dimensions, destination and ETA.
Is that the expected outcome? I could not find any limitations mentioned in the documentation. But it also doesn't give an example sentence or screenshot.
If that normal, please document that.
If I should see all fields populated, I'm happy to debug it I did something wrong. Any hints what could cause this would also be appreciated.

zjttoefs, 2023-05-28:
Okay. I do get some complete information now. Not for all vessels but some. Probably has something to do with my antenna position, then. This is initial testing and nothing has been mounted yet. But I've moved it up a bit and get better results.

I expected AIS data to arrive in atomic packets, that either come through completely or not at all. This doesn't seem to be the case.
Consider adding a sentence to identify and troubleshoot reception issues, if you want. Otherwise just close.

sailoog, 2023-06-27:
MAIANA should work OK in Openlotter.

OpenCPN v5? that is really old, are you in openplotter v2?

Docs for openplotter v3: https://openplotter.readthedocs.io/en/3.x.x/maiana/configuring.html

Docs for openplotter v2: https://openplotter.readthedocs.io/en/2.x.x/maiana/configuring.html

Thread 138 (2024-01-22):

MAIANA must not operate without a proper GND connection

peterantypas, 2024-01-22:
One of the pitfalls of designing low power circuits is that said circuits can be inadvertently back-powered from weak power sources.

As it turns out, if the CAT5 cable's "GND" connector is severed, MAIANA can actually run via the UART with its I/Os acting as a "false ground", despite the fact that these pins feature 1.1 KOhm series resistors. This causes unsafe voltages to appear at the adapter and can damage it.

Right now, I'm leaning toward redesigning the main board to use a fully isolated DC/DC module plus appropriate isolators for all of its I/Os. This will push all galvanic isolation into the main board and away from the adapters. It will also require a supercapacitor for the transmitter as well as slightly higher power draw than before.

If anyone has a simpler idea, please leave a comment here.

marcelrv, 2024-01-22:
Sound like a good idea. On the boat connections can be unreliable. Making the MAIANA more resistant to these is good idea

peterantypas, 2024-01-23:
I started a layout and this is the only way it will work. The board had to be elongated by a few mm as well. The upside is that I have figured out how to shorten the antenna stem a bit so the overall fit will not change.

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

The main issue with 12V modules is availability. CUI is completely out of 9-18V tolerant isolated DC/DC converters that would fit this form factor, so here is my plan:

- The original buck converter migrates to the AP63205 which gives a fixed 5V output and tolerates up to 32V of input
- The isolated DC/DC converter is a 5V<->5V module. There's a ton of these available in this form factor shown here
- The NCP163 LDO will be used to power the entire isolated 3.3V domain. I've used this with good results on other RF circuits
- A cheap 3.3V LDO (SE8533X2-HF) is used on the house battery domain to power the host side of the UART isolator chip. This part can tolerate 35V of input.
- Photo-transistors will be used for LED driving (I/Os must be open collector for compatibility)
- I have yet to decide the best way to isolate the TX on/off signal
- The RJ45 jack will change to the mid-mount version used on all the adapters. It's the only way for this assembly to fit into the tube
- The RF output stage will feature the same supercap as the now-defunct "MAIANA-2".

peterantypas, 2024-01-23:
The hardest part will be to fit all I/O isolators in this section:

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

peterantypas, 2024-01-23:
A side benefit of this exercise is that MAIANA should be able to operate in 24V systems as well.

peterantypas, 2024-01-23:
Initial schematic:

[transponder-12.0.0.pdf](https://github.com/peterantypas/maiana/files/14029922/transponder-12.0.0.pdf)

peterantypas, 2024-01-25:
I reproduced the problem by constructing an adapter on a breadboard. The culprit is the TX_OFF signal. This signal is a 3.3V "high" logic to the MAIANA main board to inhibit transmission. The source of the signal is each adapter's local 3.3V rail.

When the GND contact is severed, the entire MAIANA mainboard is floating at about 10-11V with respect to the adapter's GND, and that causes large reverse current flow into the adapter's 3.3V rail if the TX_OFF signal is high (TX disabled). When the TX_OFF signal is low (pulled directly to GND), MAIANA appears to work until it tries to transmit and then things go haywire.

The solution is to modify all adapters to have a large inline resistor with this signal. 2.2KOhm seems to work well. I will try to find the largest value that is still safe, given that it forms a divider with a 10K pulldown inside MAIANA and it has to drive an NMOS gate.

astuder, 2024-01-25:
FYI: On the MacArthur HAT, we have a 4.7k resistor in series between the 3.3V LDO and the TX_OFF switch. Mainly to limit current in case someone shorts the connector to GND.

We also had a user accidentally connect an Ethernet router to the RJ45 connector (easy to mix up when stacked on a Pi), which blew an ESD diode on our board. The 12V ends up coming back out of the TX_OFF pin if you do that. Due to this, we planned to add a diode on TX_OFF for a future rev.

peterantypas, 2024-01-25:
I'm very close to 11.9.0 being ready (like a day before sending to fab). I'll add a diode to TX_OFF now.

astuder, 2024-01-25:
I didn't had a chance to test the diode fix yet. So caveat emptor.

astuder, 2024-01-26:
Just checked your latest commit, and I think you misunderstood my comment re the diode.

The 12V issue is with the adapter boards, not MAIANA itself. When a 12V powered adapter board is plugged into a regular network router. The 12V will travel via the magnetics in the router back to the adapter board, coming out of the TX_OFF pin.

I don't think much will happen if someone plugs MAIANA itself into a network, as in that case MAIANA won't be powered.

peterantypas, 2024-01-26:
The issue occurs when MAIANA loses the Cat5 GND while plugged into any of the existing adapters. If TX_OFF is pulled to GND, a false, high impedance ground is created via some path that causes MAIANA to brown out during transmission. If TX_OFF is high, the 3.3V rail will see 11+ V from MAIANA and cause the regulator to burn.

I tested the diode and series resistor on the TX_OFF signal and it fixed this. Now if the Cat5 GND is lost, MAIANA stops working which is what should happen.

peterantypas, 2024-03-22:
11.9.1 has addressed this. Back-powering is no longer possible.

Closed 2024-03-22.

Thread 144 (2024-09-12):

Is there a rev 11.9 firmware?

TimVosch, 2024-09-12:
Got some issues with a self-assembled unit, but still working on debugging by process of elimination. See details below for more.

My main question is, what precompiled fw should I use with the latest pcb being rev 11.9.1, with the STM32L432KBU6?

Also, what arm toolchain version is used, my Eclipse CDT is having a tough time compiling:
```
/home/timvosch/.local/xPacks/@xpack-dev-tools/arm-none-eabi-gcc/13.3.1-1.1.1/.content/arm-none-eabi/include/c++/13.3.1/bits/requires_hosted.h:34:4: error: #error "This header is not available in freestanding mode."
```
_and 360 other errors..._

<details><summary>More debugging info im working on</summary>
<p>
I will preface this that hardware issues are not ruled out as I assembled the PCB myself. I got the - mostly - proper tools for assembly and component placements, but I am not perfect at all.

I am having issues with the transponder. I have built the latest pcb from the main branch, flashed the l432 bootloader to offset and used the python script to flash `Binaries/maiana-stm32l432-hw11.3-fw4.4.1.bin`. All goes well here.

I had an RFIC error (yes through uart in the form of a NMEA sentence) for both 1 and 2, after a resolder RFIC error 2 was gone and I only got an error for 1. I replaced the whole Si4460 component but now I am getting no uart feedback at all. I did accidentally apply 12V on the  `tx_off` - even before swapping the rf ic's -, causing the esd protection to let out a little smoke...

**how I flashed using openocd:**
```
(gdb) mon flash write_image erase unlock /home/timvosch/src/maiana/latest/Firmware/Bootloader/Binaries/maiana-bootloader-l432.bin 0x8000000
```

In gdb I see `[stm32l4x.cpu] clearing lockup after double fault` and it being interrupted. The address is a bit over the place but mostly around 0x20000800.
</p>
</details>

TimVosch, 2024-09-12:
Got it to build by using toolchain `gcc-arm-none-eabi-10-2020-q4-major` as found somewhere in a setting file (Is my Eclipse even loading the project properly..?!?!..)

Messing around with building the L432-NewBreakout in debug and loading the firmware as elf on the system. I had a succesful commandline once after loading and resetting where i continuously got:

```
$GPRMC,000023.869,V,,,,,,,060180,,,N,V*3E
$GPVTG,,T,,M,,N,,K,N*2C
$GPGGA,000023.869,,,,,0,0,,,M,,M,,*4E
$GPGSA,A,1,,,,,,,,,,,,,,,,1*03
$GPGSA,A,1,,,,,,,,,,,,,,,,2*00
$GPGSV,1,1,00,0*65
$GLGSV,1,1,00,1*78
$GPGLL,,,,,000023.869,V,N*7C
$GPRMC,000024.869,V,,,,,,,060180,,,N,V*39
$GPVTG,,T,,M,,N,,K,N*2C
$GPGGA,000024.869,,,,,0,0,,,M,,M,,*49
$GPGSA,A,1,,,,,,,,,,,,,,,,1*03
$GPGSA,A,1,,,,,,,,,,,,,,,,2*00
$GPGSV,1,1,00,0*65
$GLGSV,1,1,00,1*78
$GPGLL,,,,,000024.869,V,N*7B
```

after a reboot it stopped working again. This time I got an error output:

```
[ERROR 2]
[ERROR 5]
```

TimVosch, 2024-09-19:
Unfortunately no luck yet. I've assembled two new PCB's (I bought extra's just in case...). All of them showing the same issue.

I am gonna try and get a reason for the hardfault. But I am still suspecting that it might be an Eclipse build error.

TimVosch, 2024-09-19:
Moved the source away from eclipse because I didn't get it.

I've started debugging using gdb and stepping over lines, it consistently hardfaults after enabling the gnss module. See both screenshots.
Sometimes it gets to the `Error_Handler` function, sometimes it just hardfaults and locks up. Sometimes the crash address lays in some source code.
It almost appears as if the program counter becomes corrupted. Perhaps a stack overflow of some kind?

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

TimVosch, 2024-09-20:
@peterantypas been working on this for a few days now. Would you happen to have an idea what could be the cause?

Have you tested the latest cad board with the L432?

peterantypas, 2024-09-21:
I just pushed firmware to an L432 board. No issues. For reference my ARM toolchain is version 12.2.rel1

TimVosch, 2024-09-21:
Thanks for the response!

Then it MUST be either my tool chain version or more likely my way of
flashing the firmware. Event though its just OpenOCD.

I'll be back in the workshop Monday to test this!

Sincerely,
Tim

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

TimVosch, 2024-09-23:
Tried with 12.2rel1. No luck. It's down to either openocd, the swapped mosfet at Q2 and Q7 ([DMP2045UQ-7](https://nl.mouser.com/datasheet/2/115/diod_s_a0009189345_1-2265577.pdf)) or some stupid mistake I'm making.... Probably the latter!

Now lets order an ST-Link.

Would you mind uploading the latest elf/bin for L432? If possible without bootloader, just to eliminate an extra possible factor.

TimVosch, 2024-09-23:
### Solved

It was the MOSFET I swapped for a nearly identical one. However, this one consumed probably barely one milliampere more which causes issues on PC14 since PC14 is connected to the internal power circuitry. (See screenshot above).

peterantypas, 2024-09-23:
Thanks for the update. I may need to add some series resistors to that gate for version 12 of the board.

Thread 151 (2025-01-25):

NMEA2000 board short under screw

anm, 2025-01-25:
Rev 8.1 NMEA2000 breakout routes what seems to be a 12V power track under a mounting screw, which shorts it to ground.

A board I bought from OpenMarine shows the problem:
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

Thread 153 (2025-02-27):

N2K v8.1 adapter firmware

Haimana, 2025-02-27:
Hello Peter,
I'm trying to make the N2K adapter, v8.1 schematic with L432.
It seems the latest FW are not working with v8.1 board.
I tried to adapt the code but not success. Maybe my knowledge is not enough... :)
So, it is possible to publish the FW for v8.1 board? Or point me in the right direction if the actual FW should work?
Thank you,
Seb

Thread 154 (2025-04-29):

STM32L412KB (128k) bootloader seems to work but fails to start firmware

unkn0wn107, 2025-04-29:
Got my first batch of 10 for testing and couldn't flash a working firmware (bootloader fault ?).

I chose the **STM32L412KB** in its 128k version but found out the 412 binaries were compiled for it's 64k variant K8.
I didn't think it could be an issue and memory map seems similar from the datasheets ; it's probably were I am wrong.
The bootloader reports working boot after SWD flash : Maiana bootloader ready.
I flashed the firmware 412 - 11.9 - 4.4.1 (and other versions) through uart with python script fw-update, which reports success and rebooting. **Nothing happens anymore, even after rebooting. No uart output.**

Magic seems right :
00001800: beba adab b0d2 0000 9c84 7e5f 0000 0000
And application starts at 00002000, all seems normal for 64k configuration : [#if defined STM32L412xx && __SHRINK_TO_64K__==1](https://github.com/peterantypas/maiana/blob/31b6c8514b29a5ad21446009eafd63dff95347e9/latest/Firmware/Bootloader/Inc/config.h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)

Bootloader is maybe jumping to a wrong address or maybe memory map differences between 64k and 128k would break something.

I tried with different compositions of bootloaders and firmwares. Firmware never works, only bootloader L422 seems to work and writes magic at expected 000040000 and firmware at 000048000 (128k config). This bootloader doesn't help neither to start a working 412 firmware (also tried 422 without much convictions due to board revision)

I also tried to write manually magic and crc32 and firmware to both locations (64k / 128k).

Second approach I attempted was to build the binary for 128k STM32L412KB
I first started to compile but struggled with Eclipse config (not really used to this IDE).

Then tried to recreate the STM files from the scratch with latest STM32MX latest soft so I would start with cmake (more used to) and the proper L412 startup file, drivers etc. I tried to port Peter's code to the new file structure but I couldn't compile yet an acceptable bootloader : 16k instead of 5,9k and wrong ouput to uart (maybe just baud rate misconfig). The 16k being the very maximum size of the bootloader.

Does someone have some hints of what I could have done wrong, for debugging or to set-up a proper build environment ?
Or maybe have compiled firmware for STM32L412KB ?

Haimana, 2025-04-30:
Sorry to hear that.
Just a hint:
Try to remove the MOSFET which powers the GPS module. It could draw too much current for that pin and block the STM.
I did this for L432, too, to make it work.
At the end I replaced the MOSFET with lower gate current.
Good luck

unkn0wn107, 2025-05-09:
Thank you so much for pointing it out and sorry for late reply.

I will give it a try soon !

Here is the MOSFET I chose from UMW : [AO 3401A](https://mm.digikey.com/Volume0/opasdata/d220001/medias/docus/2969/UMW%20AO3401A.pdf).

After reading STM32L datasheet note about PC14 characteristics and GNSS consumption, I am thinking BSS84 would be more suitable : 30pF load better align with the SMT32L specs and 130mA seems more than required for GNSS module.

What about a gate resistor ?

Which MOSFET did you end up chosing ?

unkn0wn107, 2025-05-11:
You are true, the MOSFET is the culprit. I shorted it and Maiana now starts and sends GNSS sentences. Thank you !

11.8 version was using PJM3415PSA but this one seems also oversized, with a 1181pF input capacitance, much higher than STM32L specs of 30pF.

Haimana, 2025-05-12:
Great, I'm glad you fixed it.
If I remember correctly, I used AO3409.
I did not try with a serial resistor but it should work, too.

Benlamar, 2025-05-19:
I faced a very similar issue, and removing the MOSFET resolved it for me. Thanks  @Haimana , @unkn0wn107 — this post was extremely helpful!

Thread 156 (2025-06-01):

Board Revisions

ukmook, 2025-06-01:
I have been asked to build this for a friend. There are several board designs and want to make sure that i am building the correct one.
The readme states that 11.5.2 is latest but i see that 11.9 is the latest. Which one to build ?

Thanks for any help you can give me.

Benlamar, 2025-06-03:
I tested it using 11.9V, and it seems to work, although there are some issues with the MOSFET, as discussed earlier here [github.com/peterantypas/maiana/issues/154]

ukmook, 2025-06-03:
Thank-you for the info very helpful i will change the mosfet.

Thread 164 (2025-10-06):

Maiana AIS 11.9.1 UART Issue

JavadMS, 2025-10-06:
I built the 11.9.1 version with the STM32L432KCU6 and programmed it using STM32CubeProgrammer via SWD. I used the file maiana-stm32l432-11.3.0-v4.2.0-fullimage.bin for programming and did not perform any additional steps.

However, when I connect the "bare bones" UART+USB breakout (UART TX from the breakout to RX on an Arduino), I do not receive any data. I also tested it with Minicom on a Raspberry Pi. I only get some garbage characters if a common ground between the devices is not established.

Could you please advise on what steps I should take to receive proper NMEA sentences

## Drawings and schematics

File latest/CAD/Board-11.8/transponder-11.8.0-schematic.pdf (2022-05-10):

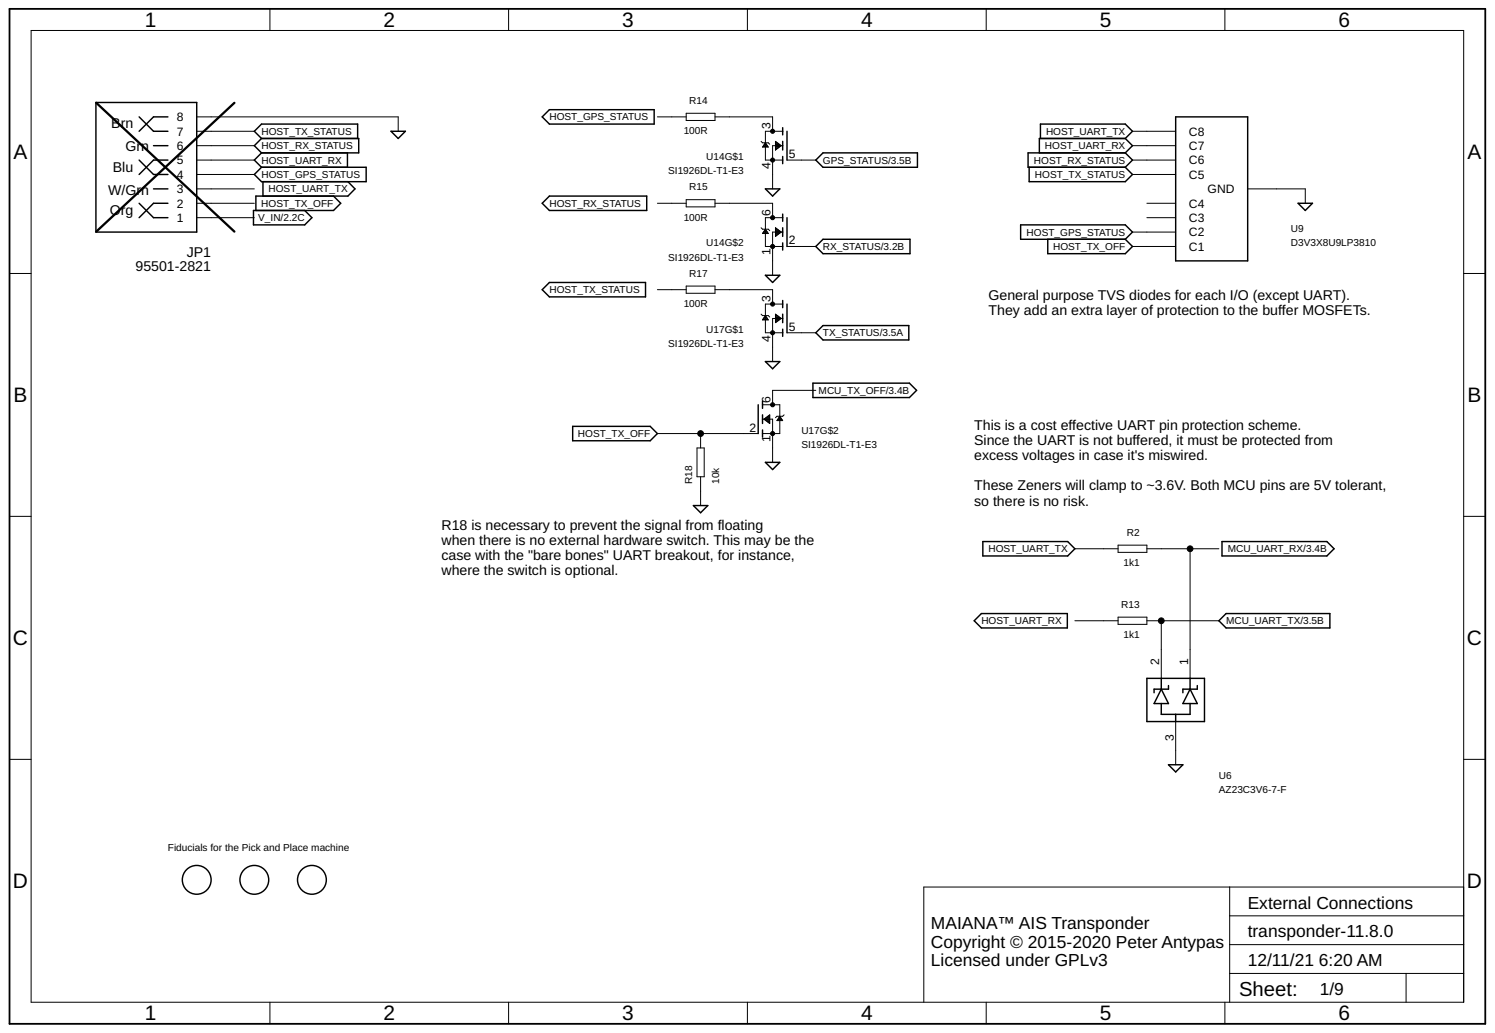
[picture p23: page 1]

General purpose TVS diodes for each I/O (except UART). They add an extra layer of protection to the buffer MOSFETs.

This is a cost effective UART pin protection scheme. Since the UART is not buffered, it must be protected from
excess voltages in case it's miswired. These Zeners will clamp to ~3.6V. Both MCU pins are 5V tolerant, so there is no risk.

R18 is necessary to prevent the signal from floating when there is no external hardware switch. This may be the
case with the "bare bones" UART breakout, for instance, where the switch is optional.

Fiducials for the Pick and Place machine

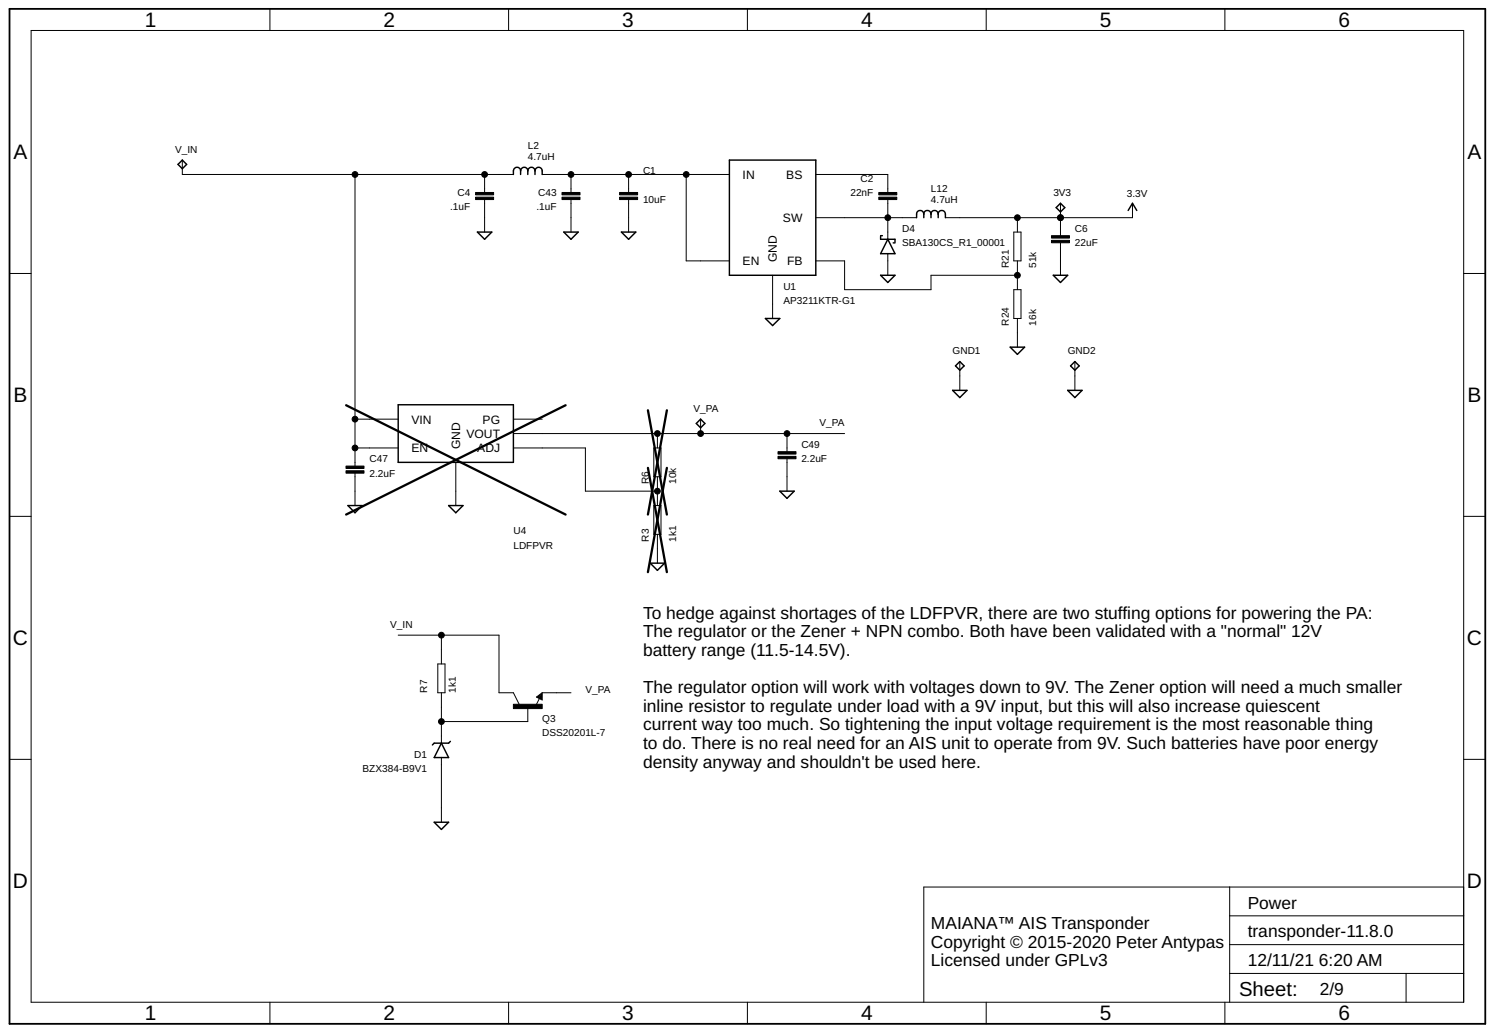
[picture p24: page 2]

To hedge against shortages of the LDFPVR, there are two stuffing options for powering the PA:
The regulator or the Zener + NPN combo. Both have been validated with a "normal" 12V
battery range (11.5-14.5V). The regulator option will work with voltages down to 9V. The Zener option will need a much smaller

inline resistor to regulate under load with a 9V input, but this will also increase quiescent
current way too much. So tightening the input voltage requirement is the most reasonable thing
to do. There is no real need for an AIS unit to operate from 9V. Such batteries have poor energy
density anyway and shouldn't be used here.

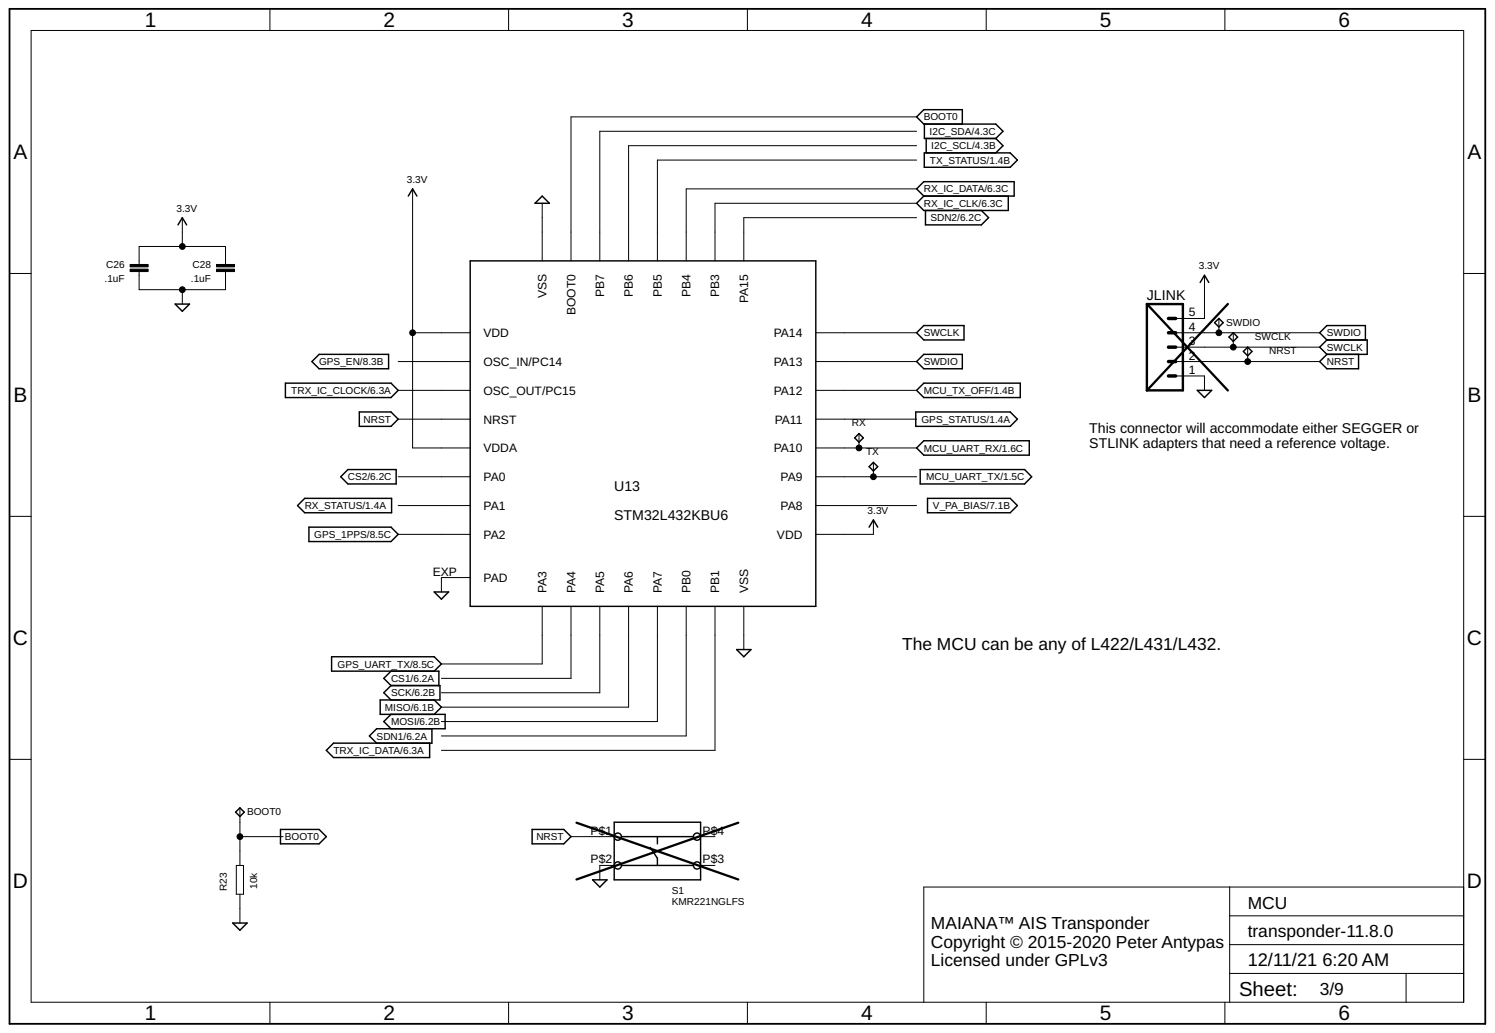
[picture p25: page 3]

This connector will accommodate either SEGGER or STLINK adapters that need a reference voltage.

The MCU can be any of L422/L431/L432.

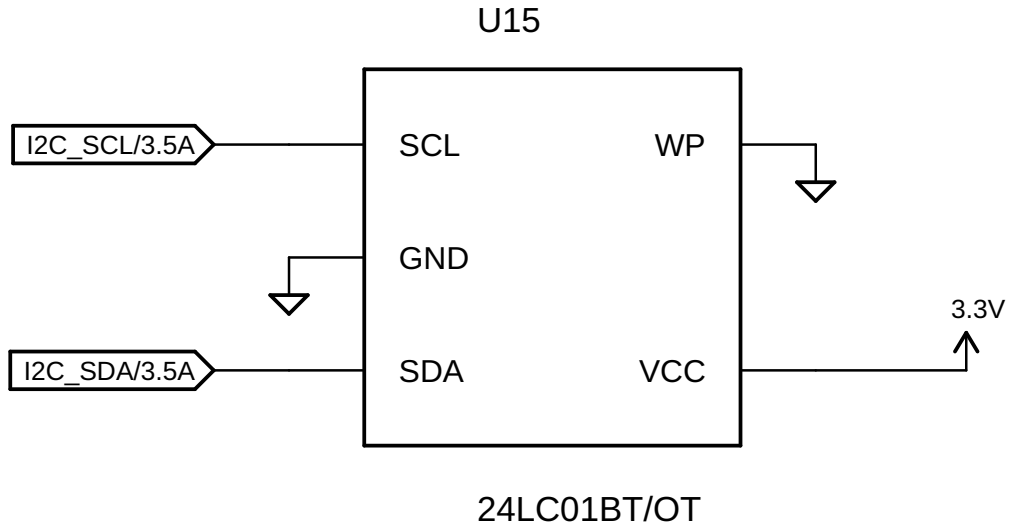
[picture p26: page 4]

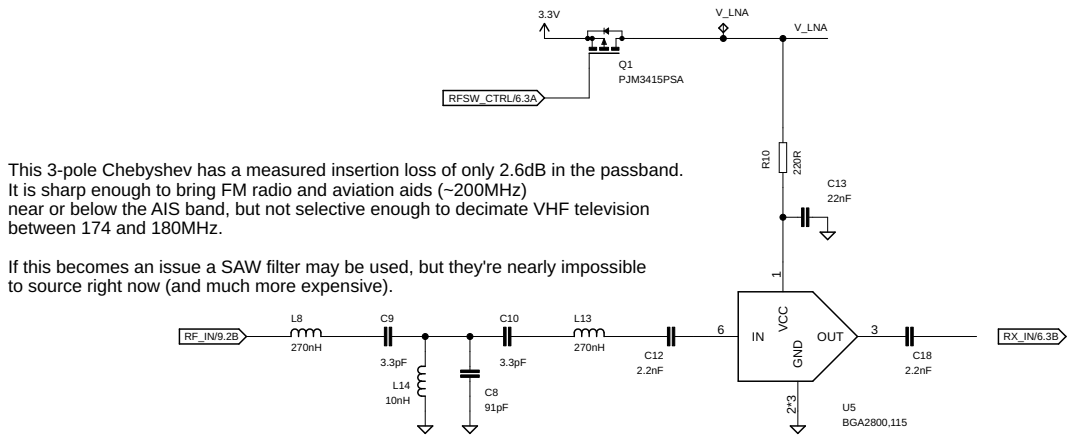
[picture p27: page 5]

This 3-pole Chebyshev has a measured insertion loss of only 2.6dB in the passband.
It is sharp enough to bring FM radio and aviation aids (~200MHz)
near or below the AIS band, but not selective enough to decimate VHF television
between 174 and 180MHz.

If this becomes an issue a SAW filter may be used, but they're nearly impossible
to source right now (and much more expensive).

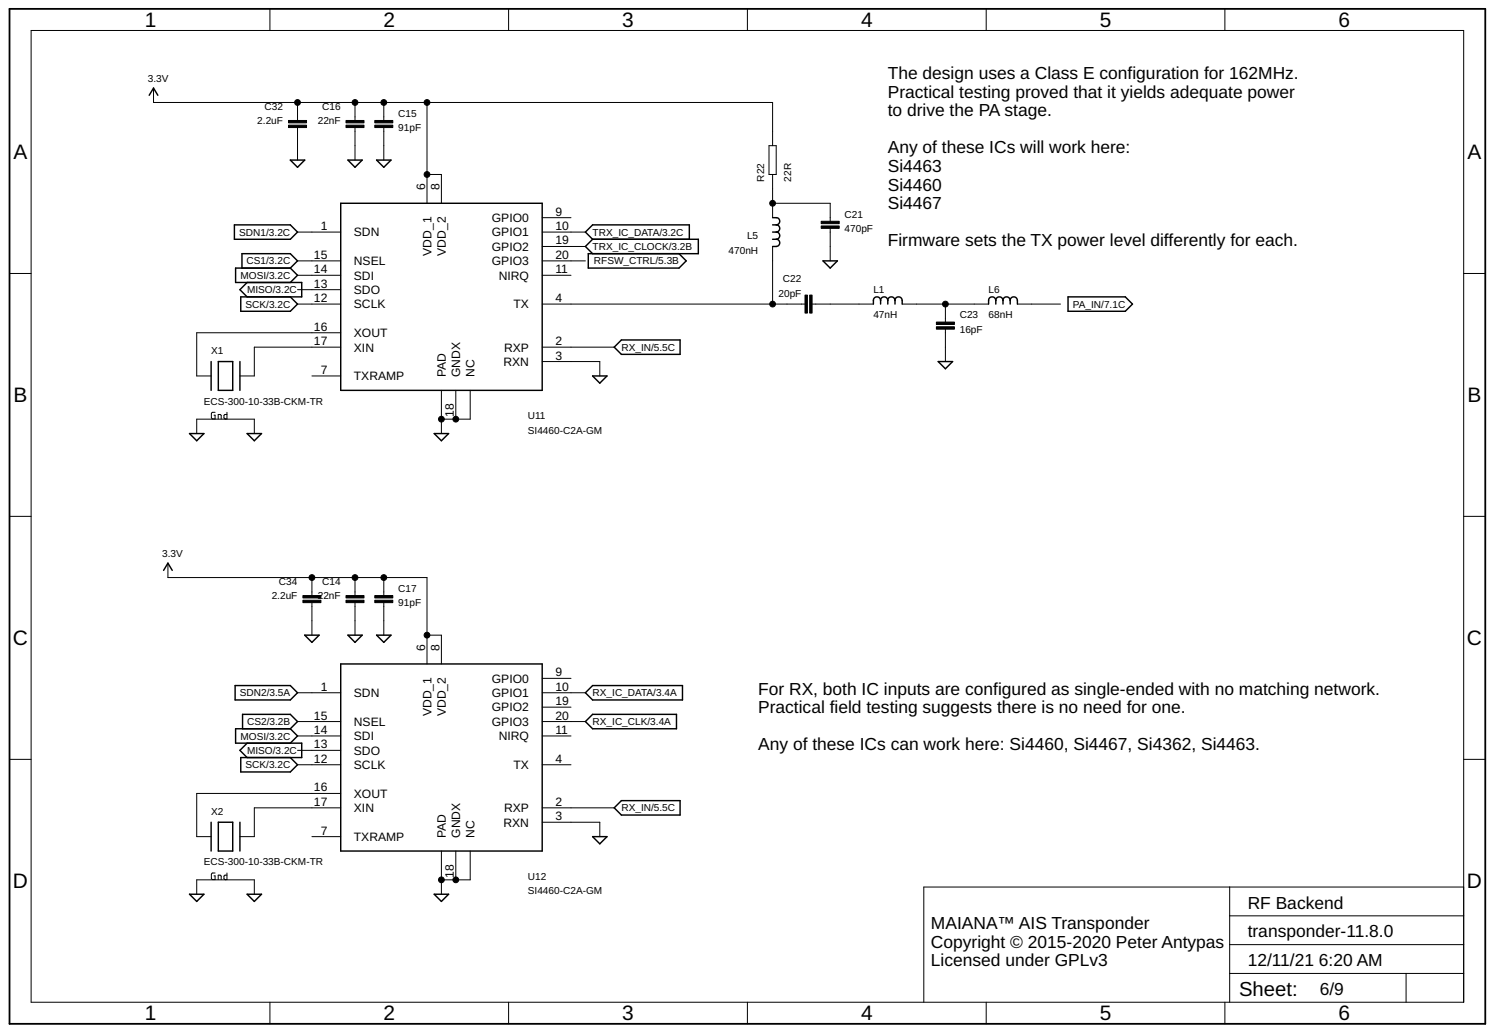
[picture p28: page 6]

The design uses a Class E configuration for 162MHz. Practical testing proved that it yields adequate power

to drive the PA stage. Any of these ICs will work here:

Firmware sets the TX power level differently for each.

For RX, both IC inputs are configured as single-ended with no matching network. Practical field testing suggests there is no need for one. Any of these ICs can work here: Si4460, Si4467, Si4362, Si4463.

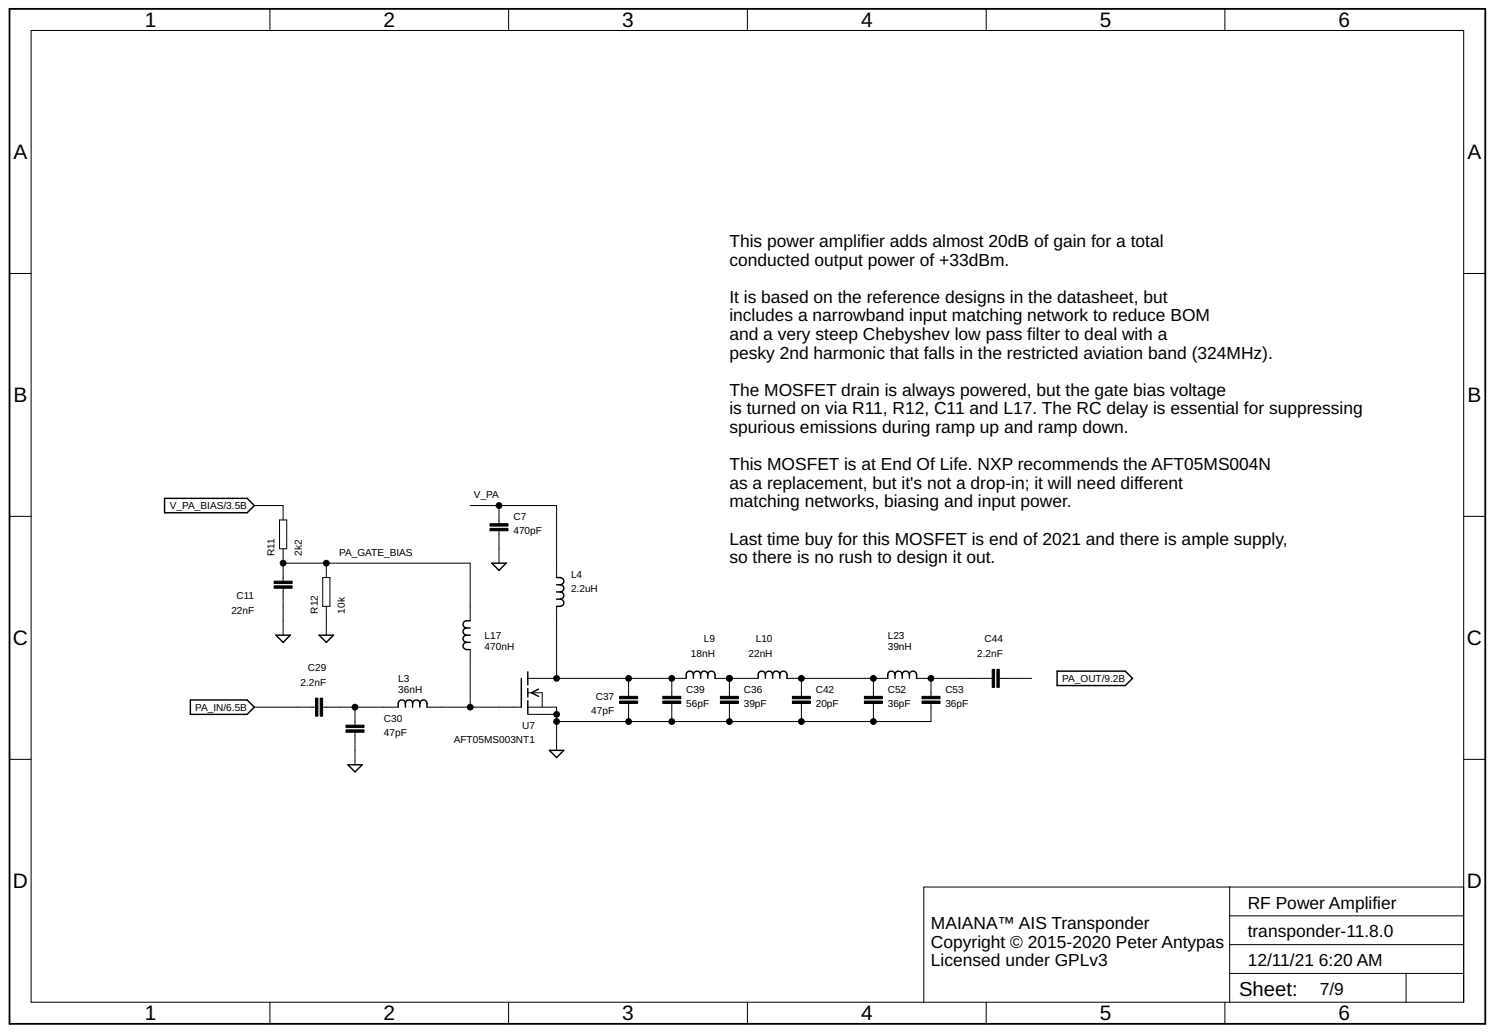
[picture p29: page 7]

This power amplifier adds almost 20dB of gain for a total
conducted output power of +33dBm.

It is based on the reference designs in the datasheet, but
includes a narrowband input matching network to reduce BOM
and a very steep Chebyshev low pass filter to deal with a
pesky 2nd harmonic that falls in the restricted aviation band (324MHz). The MOSFET drain is always powered, but the gate bias voltage

is turned on via R11, R12, C11 and L17. The RC delay is essential for suppressing
spurious emissions during ramp up and ramp down. This MOSFET is at End Of Life. NXP recommends the AFT05MS004N

as a replacement, but it's not a drop-in; it will need different
matching networks, biasing and input power. Last time buy for this MOSFET is end of 2021 and there is ample supply, so there is no rush to design it out.

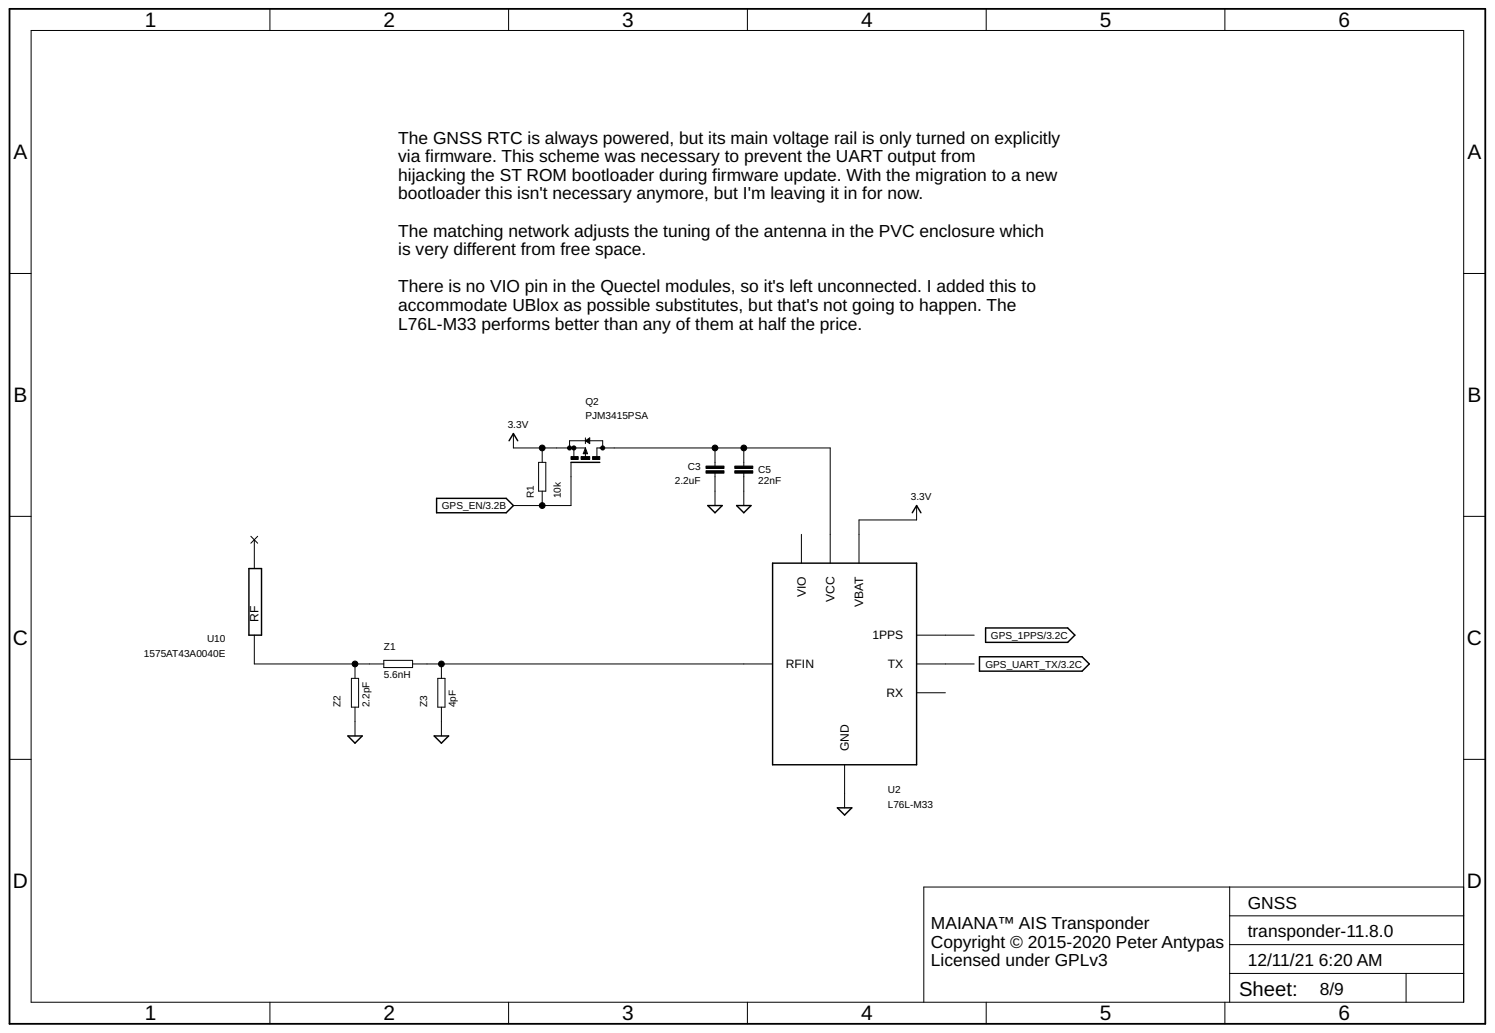
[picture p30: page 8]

The GNSS RTC is always powered, but its main voltage rail is only turned on explicitly
via firmware. This scheme was necessary to prevent the UART output from
hijacking the ST ROM bootloader during firmware update. With the migration to a new
bootloader this isn't necessary anymore, but I'm leaving it in for now. The matching network adjusts the tuning of the antenna in the PVC enclosure which

is very different from free space. There is no VIO pin in the Quectel modules, so it's left unconnected. I added this to

accommodate UBlox as possible substitutes, but that's not going to happen. The
L76L-M33 performs better than any of them at half the price.

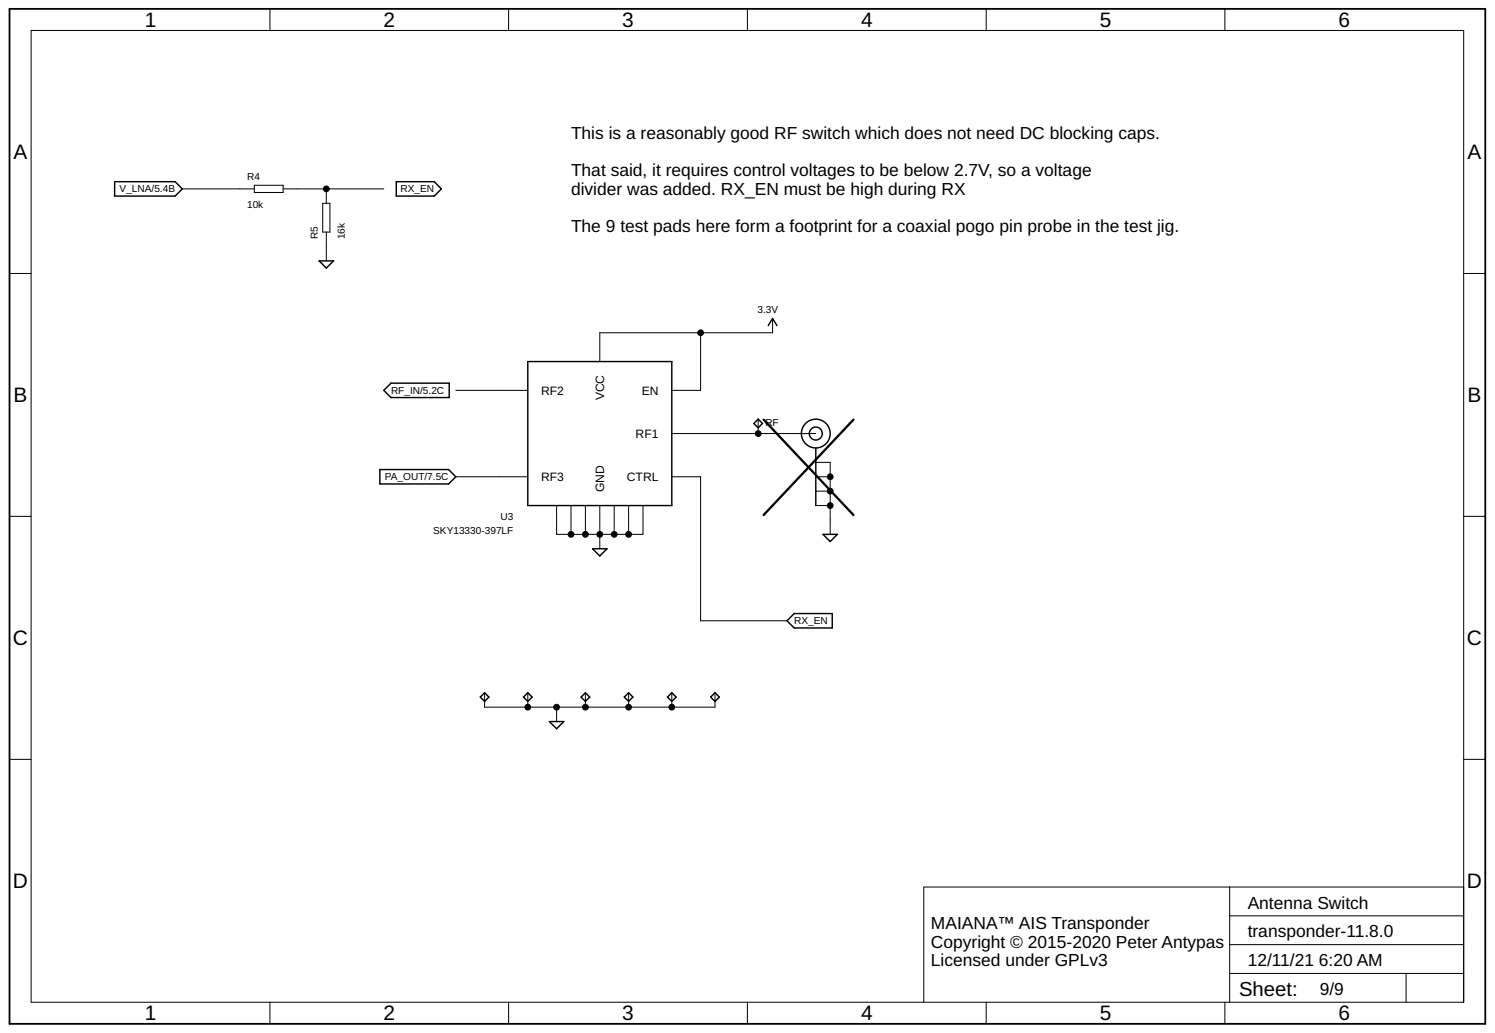
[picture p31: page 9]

This is a reasonably good RF switch which does not need DC blocking caps. That said, it requires control voltages to be below 2.7V, so a voltage

divider was added. RX_EN must be high during RX

The 9 test pads here form a footprint for a coaxial pogo pin probe in the test jig.

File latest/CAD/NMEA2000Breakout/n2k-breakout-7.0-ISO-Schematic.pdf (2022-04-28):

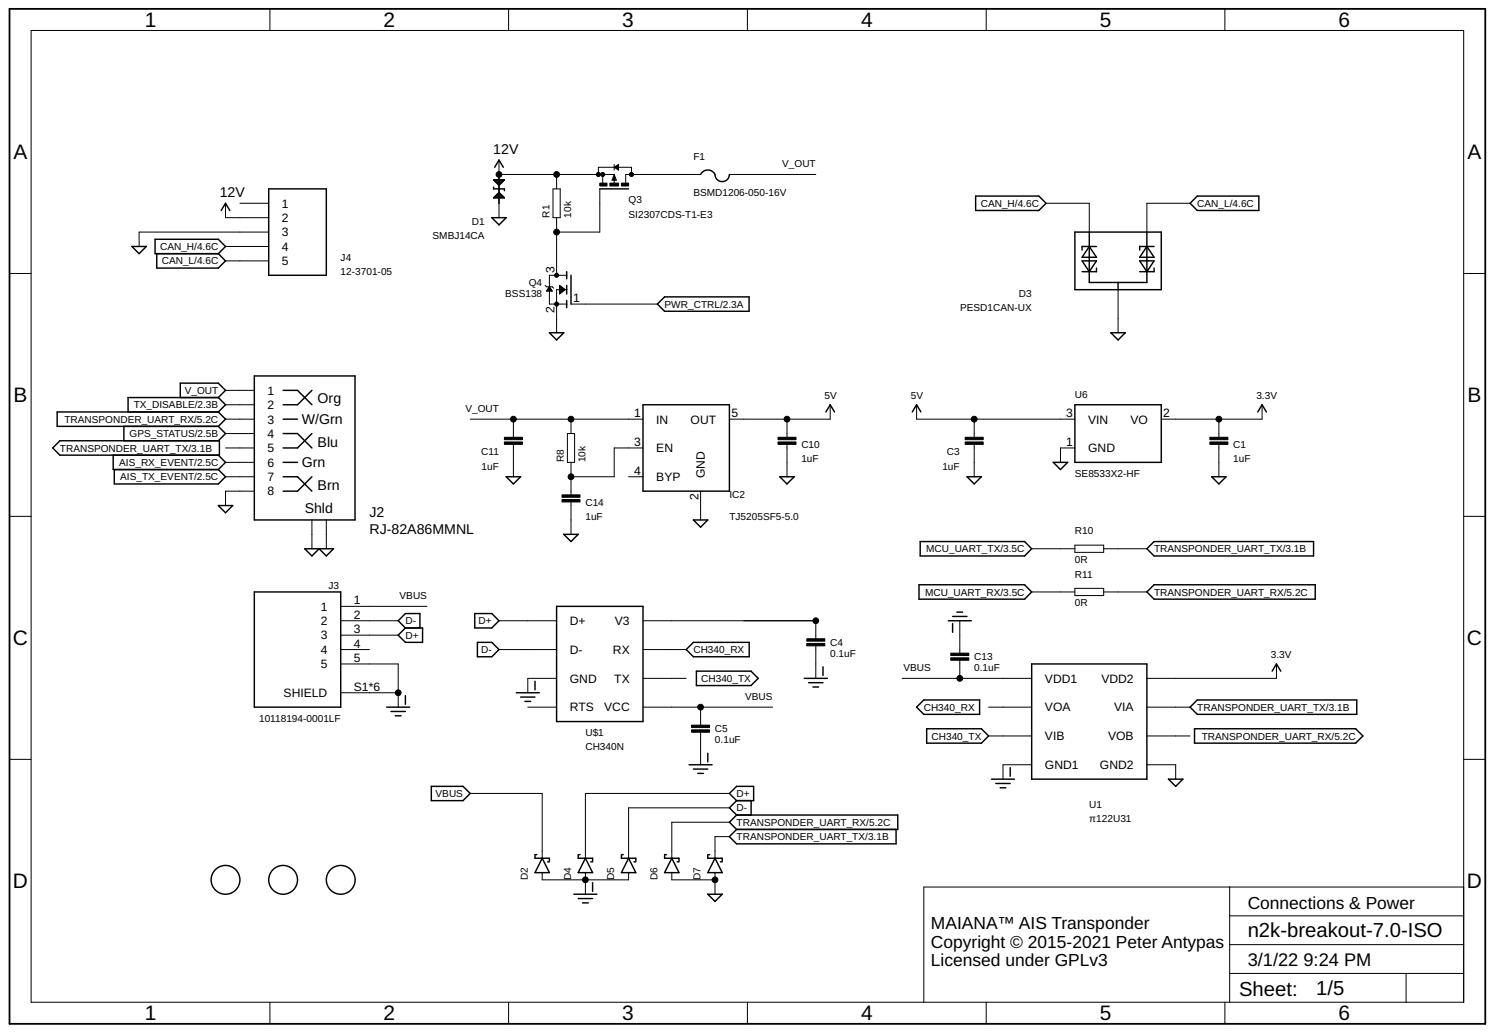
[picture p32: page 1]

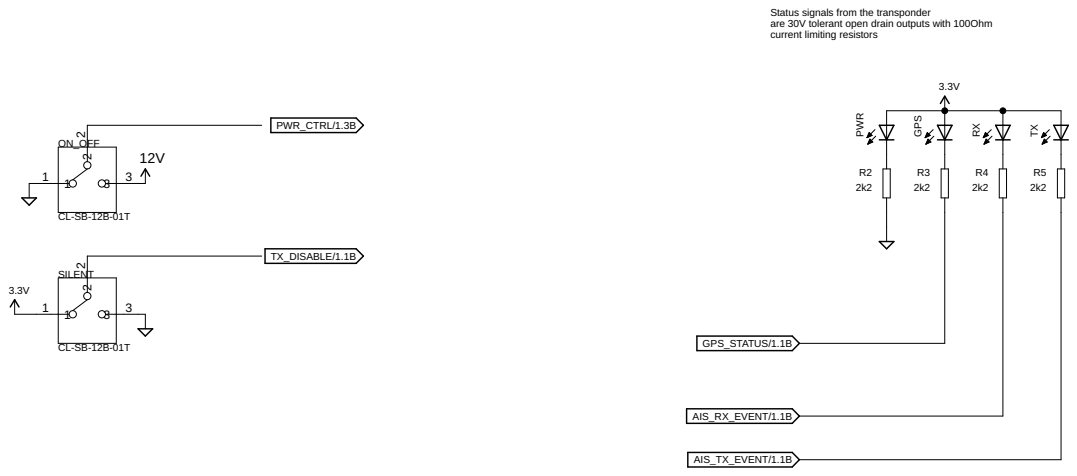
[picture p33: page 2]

Status signals from the transponder are 30V tolerant open drain outputs with 100Ohm

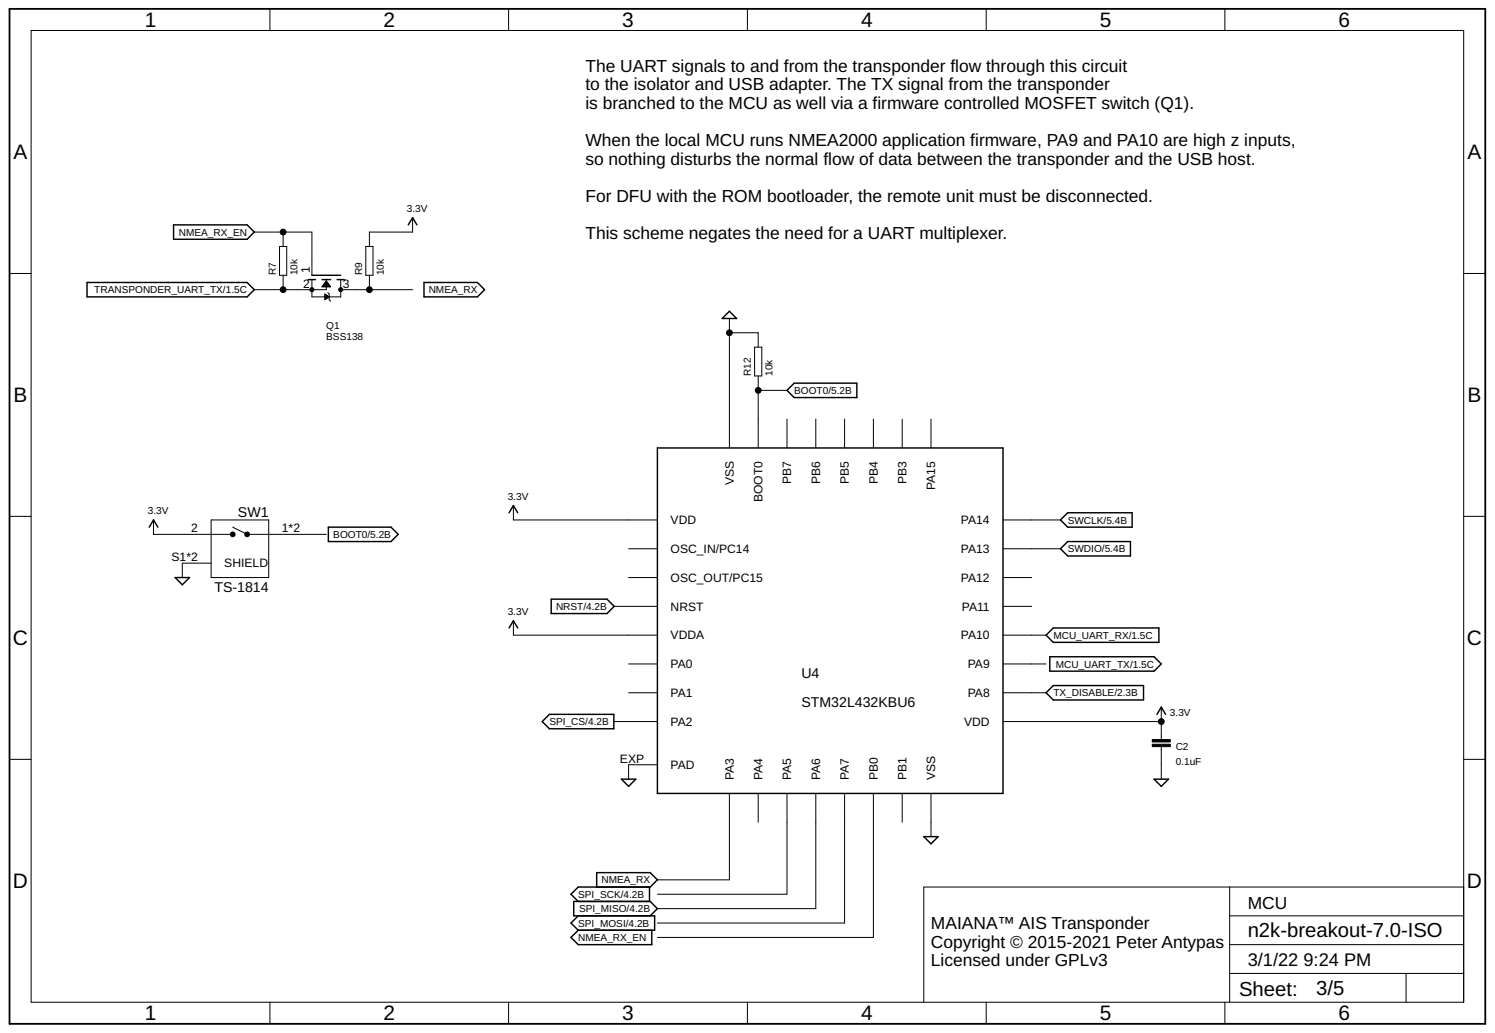
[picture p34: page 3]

The UART signals to and from the transponder flow through this circuit
to the isolator and USB adapter. The TX signal from the transponder
is branched to the MCU as well via a firmware controlled MOSFET switch (Q1). When the local MCU runs NMEA2000 application firmware, PA9 and PA10 are high z inputs, so nothing disturbs the normal flow of data between the transponder and the USB host. For DFU with the ROM bootloader, the remote unit must be disconnected. This scheme negates the need for a UART multiplexer.



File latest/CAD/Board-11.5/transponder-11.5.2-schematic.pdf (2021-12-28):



This connector will accommodate either SEGGER or STLINK adapters that need a reference voltage.

The MCU can be any of L412/L422/L431/L432.



This 3-pole Chebyshev has a measured insertion loss of only 2.6dB in the passband.
It is sharp enough to bring FM radio and aviation aids (~200MHz)
near or below the AIS band, but not selective enough to decimate VHF television
between 174 and 180MHz.
If this becomes an issue a notch filter will need to be inserted after the amplifier.


The design uses a Class E configuration for 162MHz. Practical testing proved that it yields adequate power

to drive the PA stage. Any of these ICs will work here:

Firmware sets the TX power level differently for each.

For RX, both IC inputs are configured as single-ended with no matching network. Practical field testing suggests there is no need for one. Any of these ICs can work here: Si4460, Si4467, Si4362, Si4463.


This power amplifier adds almost 20dB of gain for a total
conducted output power of +33dBm.

It is based on the reference designs in the datasheet, but
includes a narrowband input matching network to reduce BOM
and a very steep Chebyshev low pass filter to deal with a
pesky 2nd harmonic that falls in the restricted aviation band (324MHz). The MOSFET drain is always powered, but the gate bias voltage

is turned on via R11, R12, C11 and L17. The RC delay is essential for suppressing
spurious emissions during ramp up and ramp down. This MOSFET is at End Of Life. NXP recommends the AFT05MS004N

as a replacement, but it's not a drop-in; it will need different
matching networks, biasing and input power. Last time buy for this MOSFET is end of 2021 and there is ample supply, so there is no rush to design it out.



This switch does not need DC blocking caps. RX_EN must be high during RX and

The 9 test pads here form a footprint for a
coaxial pogo pin probe in the test jig.

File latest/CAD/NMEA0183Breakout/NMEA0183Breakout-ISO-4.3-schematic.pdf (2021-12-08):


For proper power sequencing, a delay is added to the EN

signal of this LDO to ensure
the remote unit has fully powered up before enabling



Status signals from the transponder are 20V tolerant open drain outputs with 100Ohm


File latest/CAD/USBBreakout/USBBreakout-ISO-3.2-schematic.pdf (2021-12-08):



Status signals from the transponder are 30V tolerant open drain outputs with 100Ohm


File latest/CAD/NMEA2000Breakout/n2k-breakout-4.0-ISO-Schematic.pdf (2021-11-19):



Status signals from the transponder are 30V tolerant open drain outputs with 100Ohm




This GreenPAK is: - A 2:1 UART multiplexer for the USB interface (transponder vs this MCU)

- A UART Tx buffer (transponder UART->MCU USART2)
- A DFU reset circuit for this board's MCU

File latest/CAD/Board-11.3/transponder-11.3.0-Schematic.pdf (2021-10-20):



This connector will accommodate either SEGGER or STLINK adapters that need a reference voltage.

The MCU can be any of L412/L422/L431/L432.



This 3-pole Chebyshev has a measured insertion loss of only 2.6dB in the passband.
It is sharp enough to bring FM radio and aviation aids (~200MHz)
near or below the AIS band, but not selective enough to decimate VHF television
between 174 and 180MHz.
If this becomes an issue a notch filter will need to be inserted after the amplifier.


The design uses a Class E configuration for 162MHz. Practical testing proved that it yields adequate power

to drive the PA stage. Any of these ICs will work here:

Firmware sets the TX power level differently for each.

For RX, both IC inputs are configured as single-ended with no matching network. Practical field testing suggests there is no need for one. Any of these ICs can work here: Si4460, Si4467, Si4362, Si4463.


This power amplifier adds almost 20dB of gain for a total
conducted output power of +33dBm.

It is based on the reference designs in the datasheet, but
includes a narrowband input matching network to reduce BOM
and a very steep Chebyshev low pass filter to deal with a
pesky 2nd harmonic that falls in the restricted aviation band (324MHz). The MOSFET drain is always powered, but the gate bias voltage

is turned on via R11, R12, C11 and L17. The RC delay is essential for suppressing
spurious emissions during ramp up and ramp down. This MOSFET is at End Of Life. NXP recommends the AFT05MS004N

as a replacement, but it's not a drop-in; it will need different
matching networks, biasing and input power. Last time buy for this MOSFET is end of 2021 and there is ample supply, so there is no rush to design it out.



This switch does not need DC blocking caps. RFSW_CTRL must be low during RX. The 9 test pads here form a footprint for a

coaxial pogo pin probe in the test jig.

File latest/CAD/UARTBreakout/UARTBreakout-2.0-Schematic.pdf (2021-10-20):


Battery input w/ ESD and
reverse polarity protection. (Working voltage range: 9-18V)

RJ45 connector from exterior unit

A 3.3V/80mA rail is made available for LEDs, a TX_DISABLE signal or other optional components.

TRANSPONDER_UART_TX: 3.3V UART output from transponder board
TRANSPONDER_UART_RX: 3.3V UART input into transponder board
RX_LED: Open drain output, pulled low for 20ms during packet RX
TX_LED: Open drain output, pulled low to indicate TX enabled, toggled during TX event
GPS_LED: Open drain output, pulled low when GNSS has valid position fix
TX_OFF: Input. Drive with 3.3V or higher to disable TX. Leave floating if not needed.

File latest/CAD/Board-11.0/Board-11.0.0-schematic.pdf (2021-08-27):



This connector will accommodate either SEGGER or STLINK adapters that need a reference voltage.

The MCU can be any of L412/L422/L431/L432.

In either case, firmware fits well within 60K, so
configuration is persisted at flash address 0x0800F800
and there is no need for an external EEPROM or I2C
bus anymore.


This 3-pole Chebyshev has a measured insertion loss of only 2.6dB in the passband.
It is sharp enough to bring FM radio and aviation aids (~200MHz)
near or below the AIS band, but not selective enough to decimate VHF television
between 174 and 180MHz.
If this becomes an issue a notch filter will need to be inserted after the amplifier.


The design uses a Class E configuration for 162MHz. Practical testing proved that it yields adequate power

to drive the PA stage. Any of these ICs will work here:

Firmware sets the TX power level differently for each.

For RX, both IC inputs are configured as single-ended with no matching network. Practical field testing suggests there is no need for one. Any of these ICs can work here: Si4460, Si4467, Si4362, Si4463.


This power amplifier adds almost 20dB of gain for a total
conducted output power of +33dBm.

It is based on the reference designs in the datasheet, but
includes a narrowband input matching network to reduce BOM
and a very steep Chebyshev low pass filter to deal with a
pesky 2nd harmonic that falls in the restricted aviation band (324MHz). The MOSFET drain is always powered, but the gate bias voltage

is turned on via R11, R12, C11 and L17. The RC delay is essential for suppressing
spurious emissions during ramp up and ramp down. This MOSFET is at End Of Life. NXP recommends the AFT05MS004N

as a replacement, but it's not a drop-in; it will need different
matching networks, biasing and input power. Last time buy for this MOSFET is end of 2021 and there is ample supply, so there is no rush to design it out.



This switch does not need DC blocking caps. RFSW_CTRL must be low during RX. The 9 test pads here form a footprint for a

coaxial pogo pin probe in the test jig.

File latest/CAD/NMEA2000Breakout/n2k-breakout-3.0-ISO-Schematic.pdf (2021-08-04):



Status signals from the transponder are 30V tolerant open drain outputs with 100Ohm




This GreenPAK is: - A 2:1 UART multiplexer for the USB interface (transponder vs this MCU)

- A UART Tx buffer (transponder UART->MCU USART2)
- A DFU reset circuit for this board's MCU

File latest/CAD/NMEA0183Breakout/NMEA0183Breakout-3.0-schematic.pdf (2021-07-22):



The CH330N only works when it's bus powered, and its UART logic level is dictated by VCC. That's why we use a 3.3V Zener to regulate it.


Status signals from the transponder are 30V tolerant open drain outputs with 100Ohm


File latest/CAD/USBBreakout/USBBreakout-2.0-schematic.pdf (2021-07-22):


The CH330N only works when it's bus powered, and its UART logic level is dictated by VCC. That's why we use a 3.3V Zener to regulate it.


Status signals from the transponder are 30V tolerant open drain outputs with 100Ohm

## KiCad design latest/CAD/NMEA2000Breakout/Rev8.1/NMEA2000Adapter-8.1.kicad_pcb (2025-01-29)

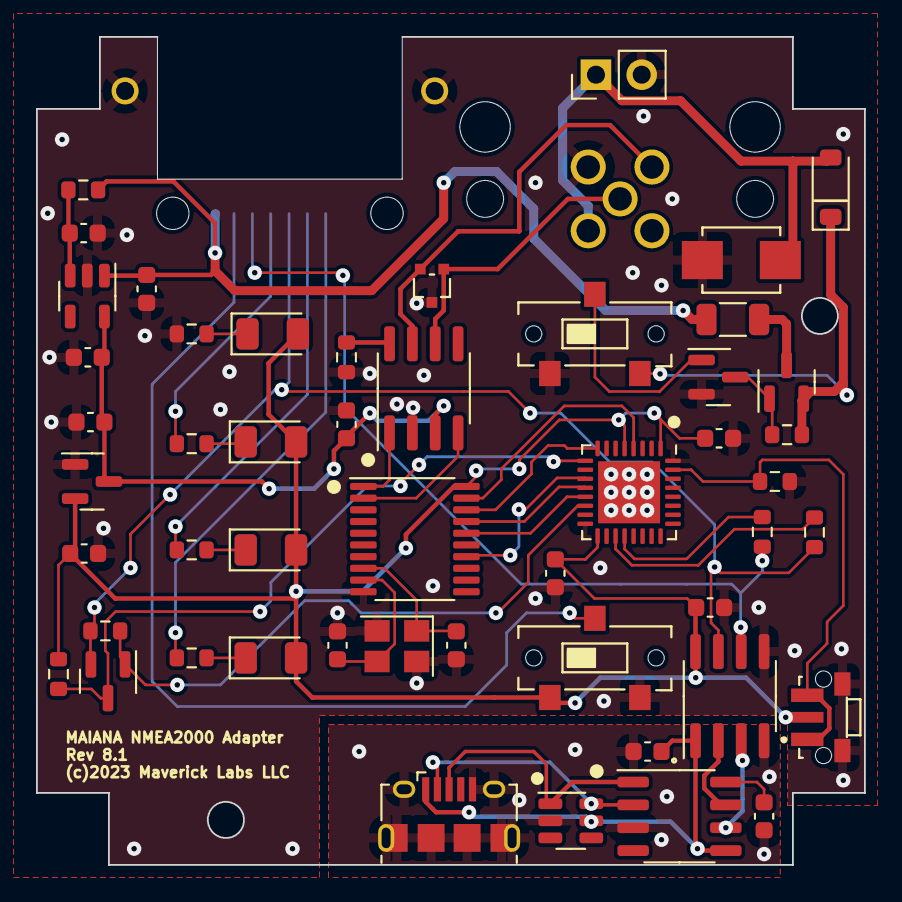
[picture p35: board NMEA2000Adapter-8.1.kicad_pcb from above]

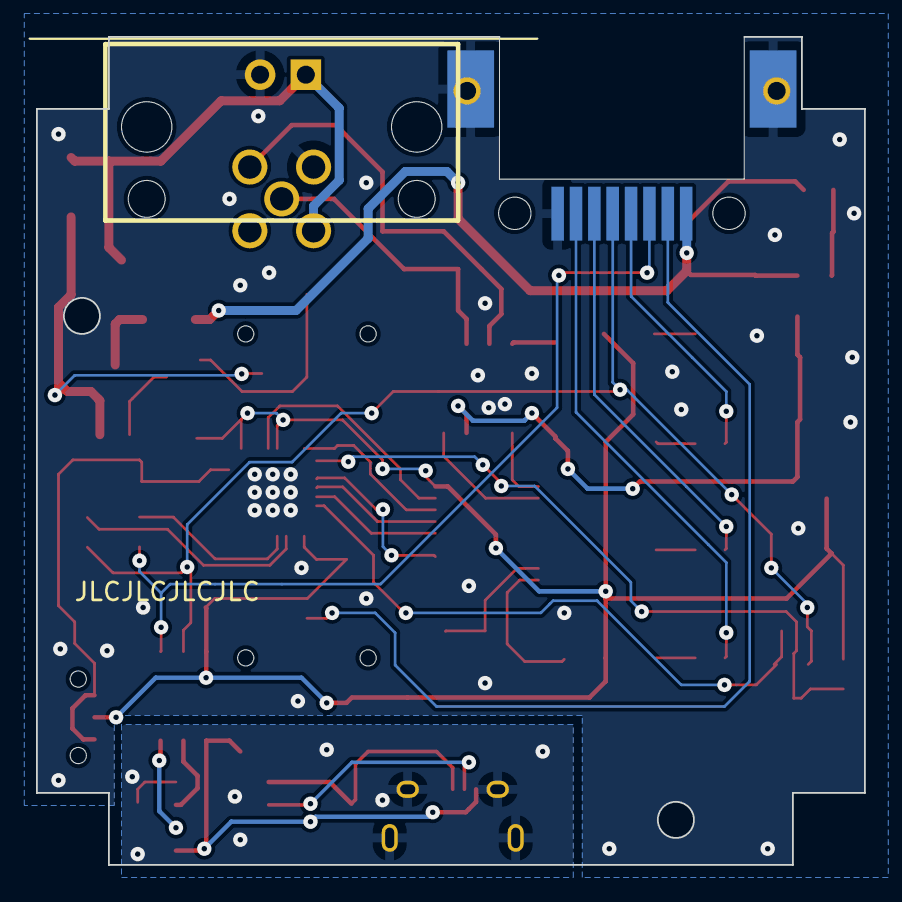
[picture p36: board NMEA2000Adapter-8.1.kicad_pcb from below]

Board: 2 copper layers, 46.0 x 46.0 mm, 52 parts (2 on the bottom side), 44 nets.

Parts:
C1, C2, C3, C11, C12, C13: 0.1uF; C_0603_1608Metric
C4, C5: 20pF; C_0603_1608Metric
C6, C7, C8, C9, C10: 1uF; C_0603_1608Metric
D1, D2, D3, D4: LED; LED_1206_3216Metric
D5: PESD1CAN-U; SOT323
D6: SMBJ16CA; DIOM4336X265N
D8: D_Schottky; D_SOD-123
J1: 12-3701-05; MICRO_C_5PIN
J2: RJ-82A86MMNL
J3: USB_B_Micro; USB_Micro-B_Amphenol_10118194_Horizontal
J4: Conn_01x02; PinHeader_1x02_P2.54mm_Vertical
Q1, Q3: BSS138; SOT-23
Q2: AO3401A; SOT-23
R1, R2, R3, R4: 2k2; R_0603_1608Metric
R5, R6, R7, R8, R9, R10: 10k; R_0603_1608Metric
R11, R12: 0R; R_0603_1608Metric
SW1, SW2: CL-SB-12B-01T
SW3: TS-1814; TE_1977066-1
TH1: BSMD1206-050-16V; R_1206_3216Metric
U1: STM32L432KBUx; QFN-32-1EP_5x5mm_P0.5mm_EP3.45x3.45mm
U2: MCP2515-xST; TSSOP-20_4.4x6.5mm_P0.65mm
U3: MCP2551-I-SN; SOIC-8_3.9x4.9mm_P1.27mm
U4: SRV05-4; SOT-23-6
U5: CH340N; SO-8_3.9x4.9mm_P1.27mm
U6: ISO7721DR; SOIC-8_3.9x4.9mm_P1.27mm
U7: TJ5205SF5-5.0; SOT-23-5
U8: SE8533X2-HF; SOT-23
Y1: X322516MOB4SI; Crystal_SMD_3225-4Pin_3.2x2.5mm

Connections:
+3.3V: C2.1, C10.1, C12.1, C13.1, D1.2 (A), D2.2 (A), D3.2 (A), D4.2 (A), R10.1, SW2.1, SW3.2, U1.1 (VDD), U1.5 (VDDA), U1.17 (VDD), U2.20 (VDD), U6.8 (VDD2), U8.2 (VO)
+5V: C8.1, C9.1, C11.1, U3.3 (VDD), U7.5 (OUT), U8.3 (VI)
+12V: D6.2, D8.2 (A), J1.2, J4.1
/CAN/CAN_H: D5.2, J1.4, U3.7 (CANH)
/CAN/CAN_L: D5.1, J1.5, U3.6 (CANL)
/CAN/NRST: U1.4 (NRST), U2.19 (~RESET)
/CAN/SPI_CS: U1.8 (PA2), U2.18 (~CS)
/CAN/SPI_MISO: U1.12 (PA6), U2.17 (SO)
/CAN/SPI_MOSI: U1.13 (PA7), U2.16 (SI)
/CAN/SPI_SCK: U1.11 (PA5), U2.14 (SCK)
/Connections/AIS_RX_EVENT: J2.P$6 (6), R3.2
/Connections/AIS_TX_EVENT: J2.P$7 (7), R4.2
/Connections/GPS_STATUS: J2.P$4 (4), R2.2
/Connections/MCU_UART_RX: R12.2, U1.20 (PA10)
/Connections/MCU_UART_TX: R11.2, U1.19 (PA9)
/Connections/TRANSPONDER_UART_TX: J2.P$5 (5), Q3.2 (S), R9.2, R11.1, U6.7 (VIA)
/Connections/TX_DISABLE: J2.P$2 (2), SW2.C
/Connections/V_OUT: C7.1, J2.P$1 (1), R6.1, TH1.1, U7.1 (IN)
/MCU/BOOT0: R8.1, SW3.1, SW3.3, U1.31 (PH3)
/Power/PWR_CTRL: Q1.1 (G), SW1.C
/Power/V_IN: D8.1 (K), Q2.2 (S), R5.1, SW1.3
CH340_RX: U5.7 (RX), U6.2 (VOA)
CH340_TX: U5.6 (TX), U6.3 (VIB)
D+: J3.3 (D+), U4.1 (IO1), U5.1 (D+)
D-: J3.2 (D-), U4.6 (IO4), U5.2 (D-)
GND: C2.2, C4.2, C5.2, C6.2, C7.2, C8.2, C9.2, C10.2, C11.2, C12.2, C13.2, D5.3, D6.1, J1.3, J2.P$8 (8), J2.P$9, J2.P$10, J2.P$11, J2.P$12, J4.2, Q1.2 (S), R1.2, R7.2, R8.2, SW1.1, SW2.3, SW3.S1 (SHIELD), SW3.S2 (SHIELD), U1.16 (VSS), U1.32 (VSS), U1.33 (VSS), U2.10 (VSS), U3.2 (VSS), U6.5 (GND2), U7.2 (GND), U8.1 (GND), Y1.2, Y1.4
GND2: C1.2, C3.2, J3.5 (GND), J3.6 (Shield), U4.2 (VN), U5.3 (GND), U6.4 (GND1)
NMEA_RX: Q3.3 (D), R10.2, U1.9 (PA3)
NMEA_RX_EN: Q3.1 (G), R9.1, U1.14 (PB0)
unnamed: D1.1 (K), R1.1
unnamed: D2.1 (K), R2.1
unnamed: D3.1 (K), R3.1
unnamed: D4.1 (K), R4.1
unnamed: Q1.3 (D), Q2.1 (G), R5.2
unnamed: Q2.3 (D), TH1.2
unnamed: U2.2 (RXCAN), U3.4 (RXD)
unnamed: U2.1 (TXCAN), U3.1 (TXD)
unnamed: R7.1, U3.8 (Rs)
unnamed: C1.1, U5.8 (V3)
unnamed: C6.1, R6.2, U7.3 (EN)
TRANSPONDER_UART_RX: J2.P$3 (3), R12.1, U6.6 (VOB)
VBUS: C3.1, J3.1 (VBUS), U4.5 (VP), U5.5 (VCC), U6.1 (VDD1)
XTL1: C5.1, U2.8 (OSC2), Y1.1
XTL2: C4.1, U2.9 (OSC1), Y1.3

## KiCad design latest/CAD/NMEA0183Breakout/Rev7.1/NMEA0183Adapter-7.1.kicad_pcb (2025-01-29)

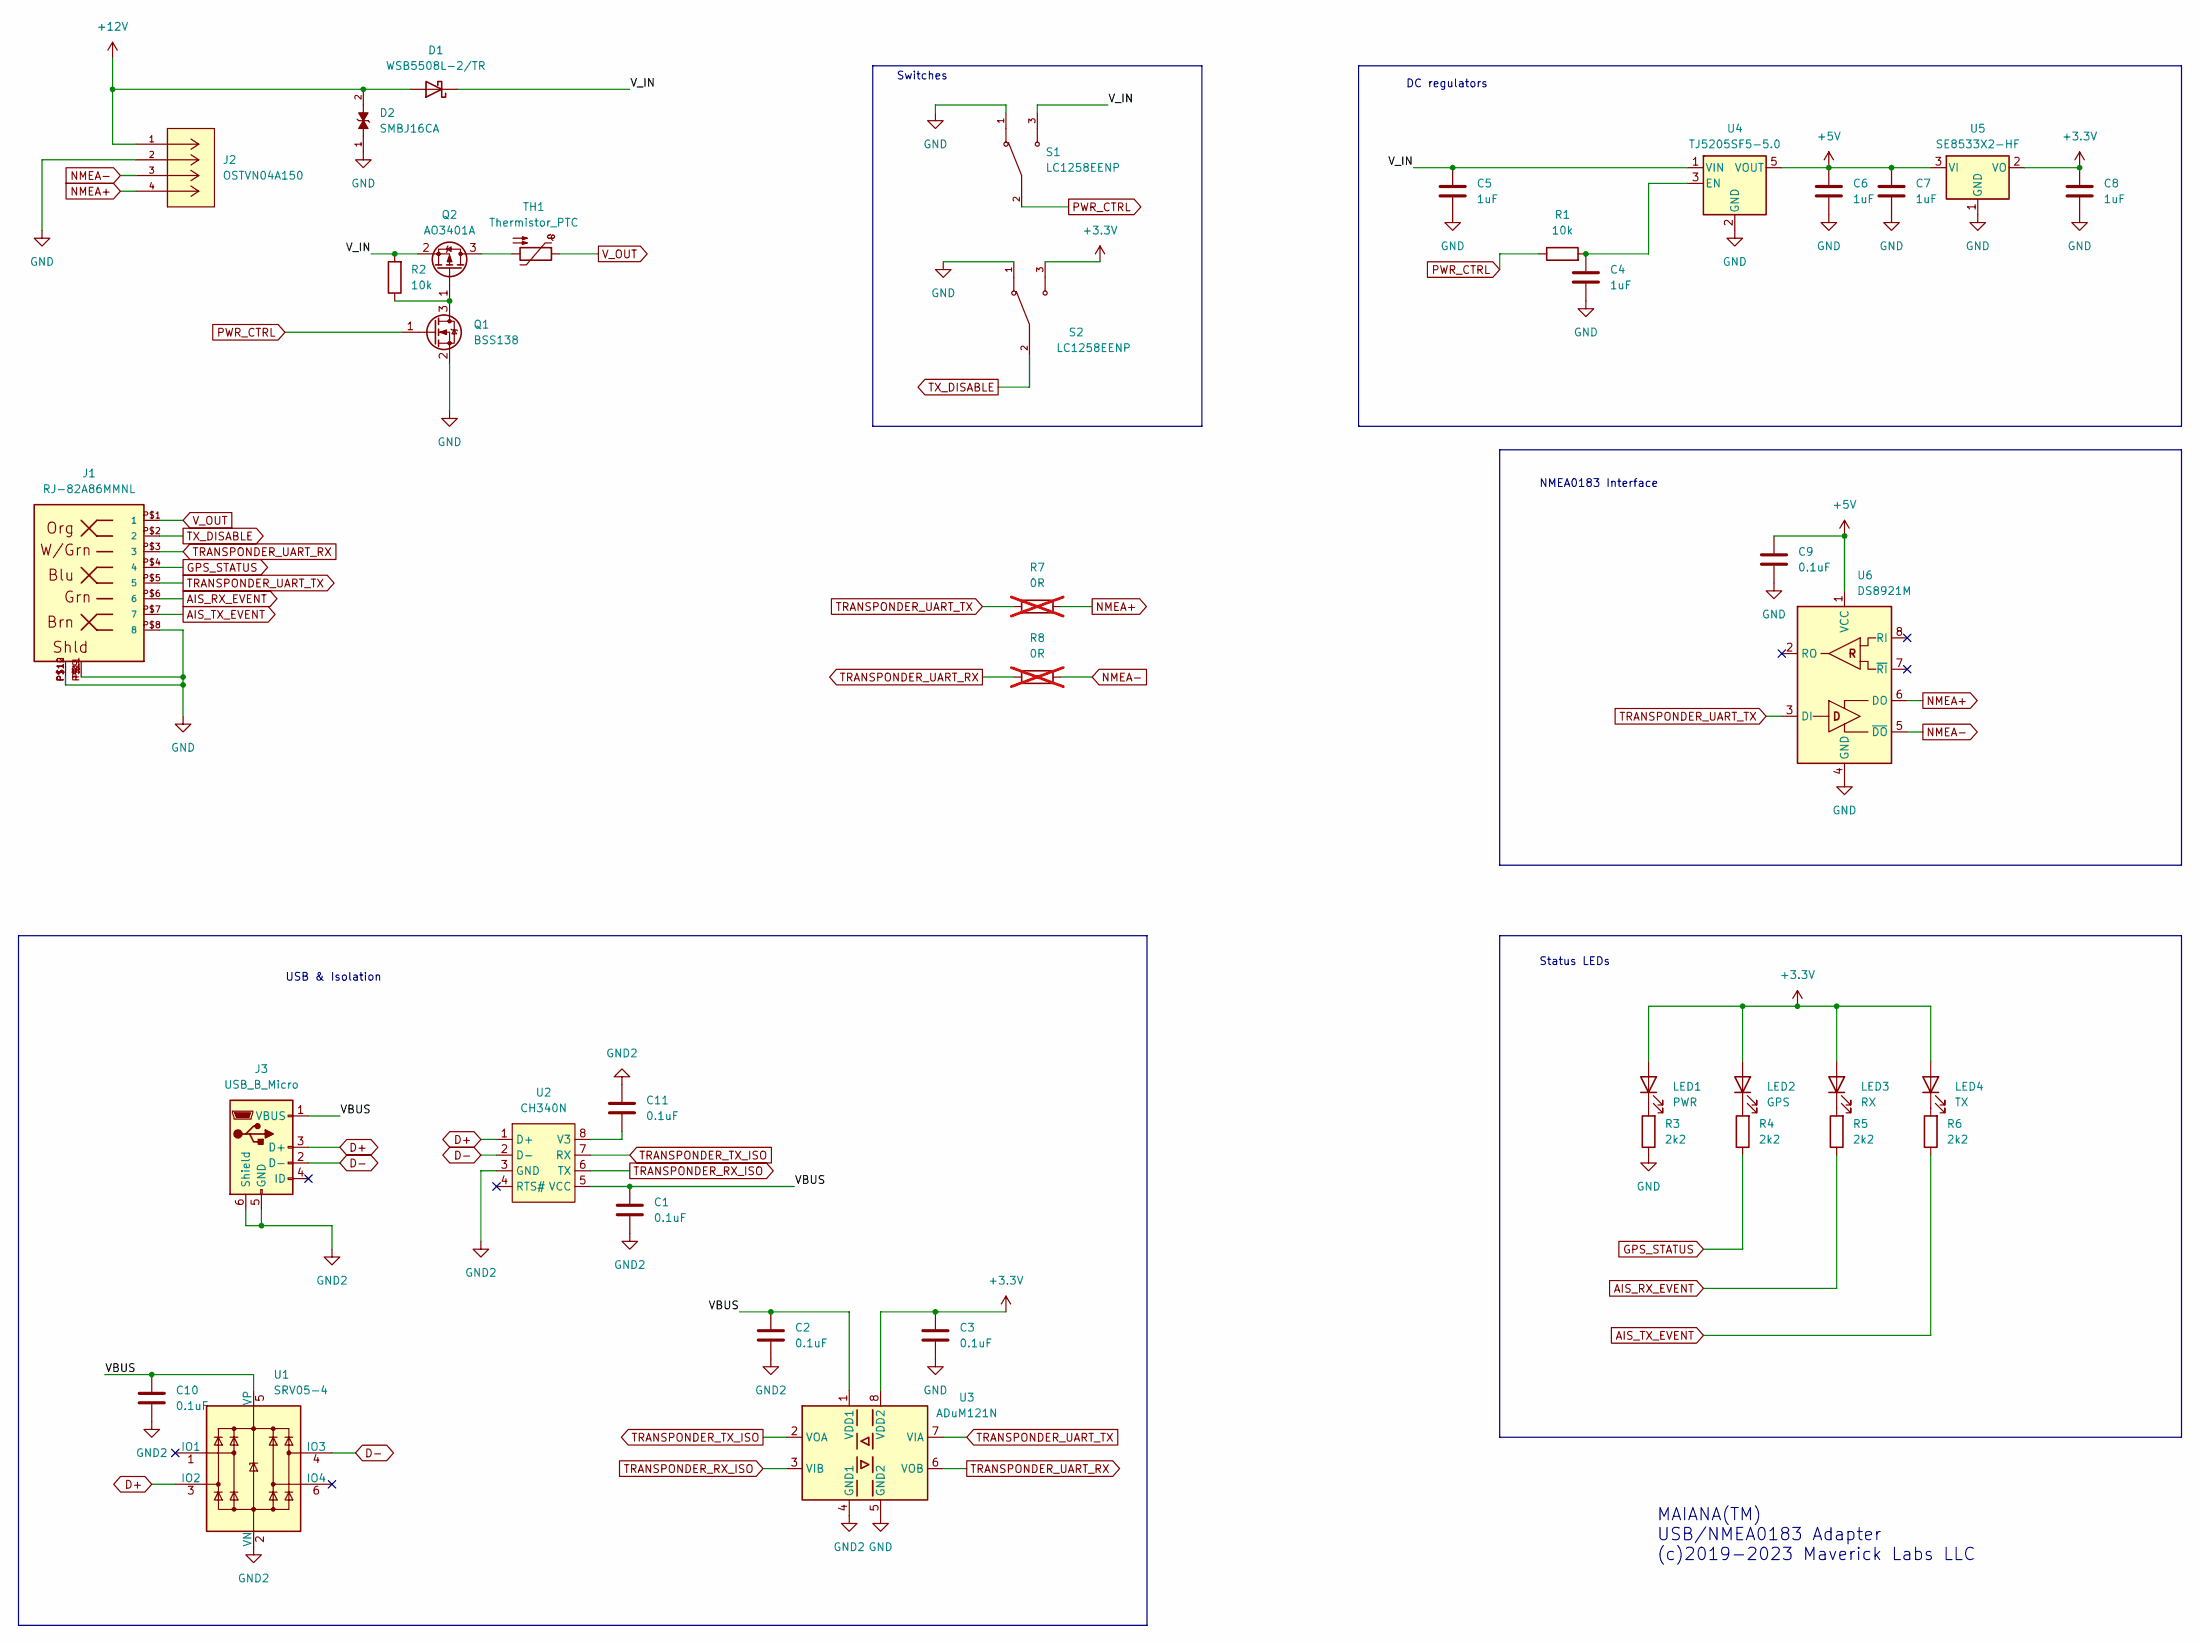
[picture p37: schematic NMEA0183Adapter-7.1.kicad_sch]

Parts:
C1, C2, C3, C9, C10, C11: 0.1uF; C_0603_1608Metric
C4, C5, C6, C7, C8: 1uF; C_0603_1608Metric
D1: WSB5508L-2/TR; D_SOD-123
D2: SMBJ16CA; DIOM4336X265N; PARTREV I2102
J1: RJ-82A86MMNL; PARTNO RJ-82A86MMNL
J2: OSTVN04A150; CONN_OSTVN04A150_OST; MANUFACTURER_PART_NUMBER OSTVN04A150; DIGI-KEY_PART_NUMBER_1 ED10563-ND
J3: USB_B_Micro; USB_Micro-B_Amphenol_10118194_Horizontal
LED1: PWR; LED_1206_3216Metric
LED2: GPS; LED_1206_3216Metric
LED3: RX; LED_1206_3216Metric
LED4: TX; LED_1206_3216Metric
Q1: BSS138; SOT-23
Q2: AO3401A; SOT-23
R1, R2: 10k; R_0603_1608Metric
R3, R4, R5, R6: 2k2; R_0603_1608Metric
R7, R8: 0R; R_0603_1608Metric; not fitted
S1, S2: LC1258EENP; SW_LC1258EENP; PARTREV C
TH1: Thermistor_PTC; R_1206_3216Metric
U1: SRV05-4; SOT-23-6
U2: CH340N; SO-8_3.9x4.9mm_P1.27mm
U3: ADuM121N; SOIC-8_3.9x4.9mm_P1.27mm
U4: TJ5205SF5-5.0; SOT-23-5
U5: SE8533X2-HF; SOT-23
U6: DS8921M; SOIC-8_3.9x4.9mm_P1.27mm

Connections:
+3.3V: C3.1, C8.1, LED1.2 (A), LED2.2 (A), LED3.2 (A), LED4.2 (A), S2.3, U3.8 (VDD2), U5.2 (VO)
+5V: C6.1, C7.1, C9.1, U4.5 (VOUT), U5.3 (VI), U6.1 (VCC)
+12V: D1.2 (A), D2.2, J2.1
/VBUS: C1.1, C2.1, C10.1, J3.1 (VBUS), U1.5 (VP), U2.5 (VCC), U3.1 (VDD1)
/V_IN: C5.1, D1.1 (K), Q2.2 (S), R2.2, S1.3, U4.1 (VIN)
AIS_RX_EVENT: J1.P$6 (6), R5.1
AIS_TX_EVENT: J1.P$7 (7), R6.1
D+: J3.3 (D+), U1.3 (IO2), U2.1 (D+)
D-: J3.2 (D-), U1.4 (IO3), U2.2 (D-)
GND: C3.2, C4.2, C5.2, C6.2, C7.2, C8.2, C9.2, D2.1, J1.P$8 (8), J1.P$9, J1.P$10, J1.P$11, J1.P$12, J2.2, Q1.2 (S), R3.1, S1.1, S2.1, U3.5 (GND2), U4.2 (GND), U5.1 (GND), U6.4 (GND)
GND2: C1.2, C2.2, C10.2, C11.1, J3.5 (GND), J3.6 (Shield), U1.2 (VN), U2.3 (GND), U3.4 (GND1)
GPS_STATUS: J1.P$4 (4), R4.1
NMEA+: J2.4, R7.1, U6.6 (DO)
NMEA-: J2.3, R8.1, U6.5 (~DO)
unnamed: LED1.1 (K), R3.2
unnamed: LED2.1 (K), R4.2
unnamed: LED3.1 (K), R5.2
unnamed: LED4.1 (K), R6.2
unnamed: Q1.3 (D), Q2.1 (G), R2.1
unnamed: Q2.3 (D), TH1.2
unnamed: C11.2, U2.8 (V3)
unnamed: C4.1, R1.2, U4.3 (EN)
PWR_CTRL: Q1.1 (G), R1.1, S1.2
TRANSPONDER_RX_ISO: U2.6 (TX), U3.3 (VIB)
TRANSPONDER_TX_ISO: U2.7 (RX), U3.2 (VOA)
TRANSPONDER_UART_RX: J1.P$3 (3), R8.2, U3.6 (VOB)
TRANSPONDER_UART_TX: J1.P$5 (5), R7.2, U3.7 (VIA), U6.3 (DI)
TX_DISABLE: J1.P$2 (2), S2.2
V_OUT: J1.P$1 (1), TH1.1

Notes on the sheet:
USB & Isolation
Status LEDs
MAIANA(TM) USB/NMEA0183 Adapter (c)2019-2023 Maverick Labs LLC
NMEA0183 Interface
DC regulators
Switches

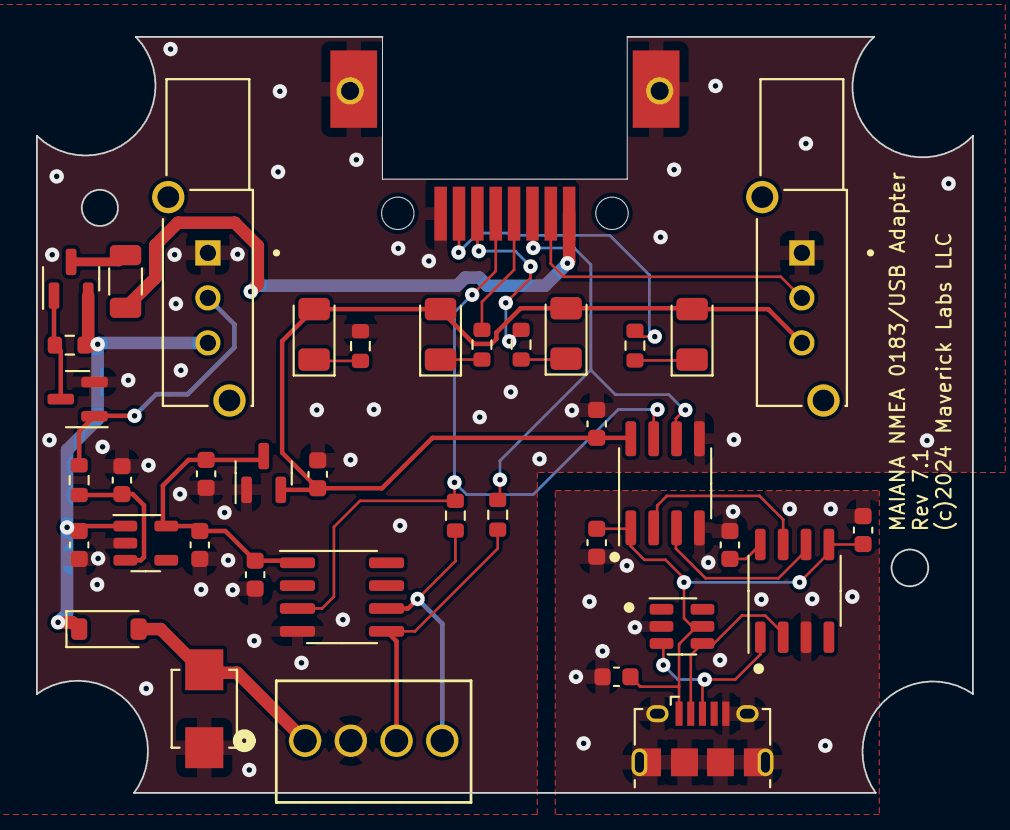
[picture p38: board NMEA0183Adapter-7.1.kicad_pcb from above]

Board: 2 copper layers, 52.0 x 42.0 mm, 39 parts (0 on the bottom side), 29 nets.

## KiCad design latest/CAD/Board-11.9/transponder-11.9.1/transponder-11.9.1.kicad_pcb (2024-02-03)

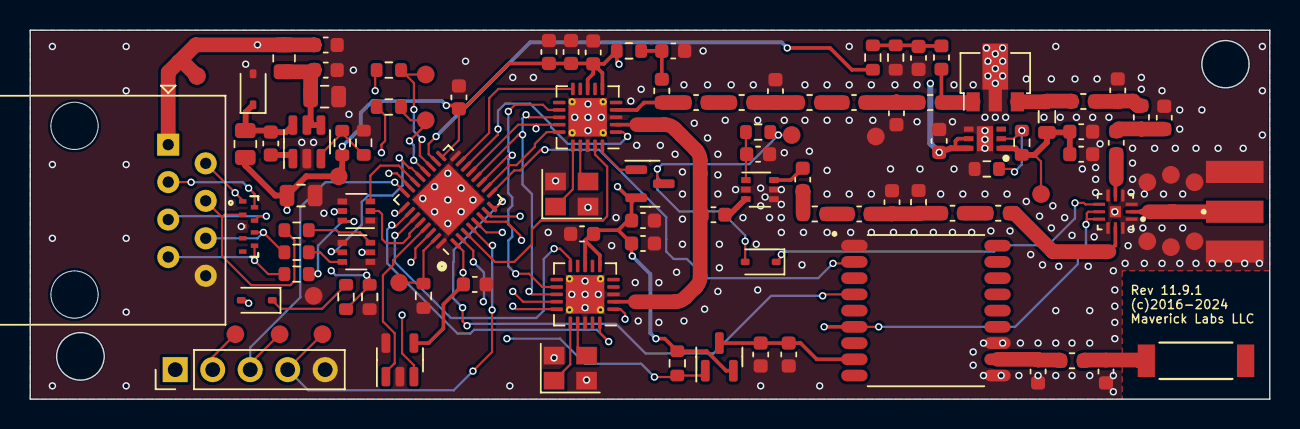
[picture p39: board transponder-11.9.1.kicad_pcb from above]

Board: 4 copper layers, 84.0 x 25.0 mm, 109 parts (0 on the bottom side), 79 nets.

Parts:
AE1: 1575AT43A0040E; ANT_1575AT_JOT
C1, C2, C16, C18: 2.2nF; C_0603_1608Metric
C3, C9, C11, C19, C27, C31: 22nF; C_0603_1608Metric
C4, C5: 3.3pF; C_0603_1608Metric
C6, C8, C12: 91pF; C_0603_1608Metric
C7, C10, C23, C24, C30: 2.2uF; C_0603_1608Metric
C13, C20: 470pF; C_0603_1608Metric
C14, C17: 110pF; C_0603_1608Metric
C15: 36pF; C_0603_1608Metric
C21: 20pF; C_0603_1608Metric
C22: 16pF; C_0603_1608Metric
C25, C26, C34, C35: 0.1uf; C_0603_1608Metric
C28: 22uF; C_0805_2012Metric
C29: 10uF; C_0805_2012Metric
C32: 4pF; C_0603_1608Metric
C33: 2.2pF; C_0603_1608Metric
CR1: D3V3X8U9LP3810-7; U-DFN3810-9TYPE_B_DIO
D1, D3, D4: BAT54WS; D_SOD-323
IC1: LDFPVR; SON65P200X200X100-7N-D
J1: RJ45; RJ45_Amphenol_54602-x08_Horizontal
J2: Conn_01x05; PinHeader_1x05_P2.54mm_Vertical
J3: CON-SMA-EDGE-S; RFSOLUTIONS_CON-SMA-EDGE-S
L1, L2: 270nH; L_0603_1608Metric
L3: 10nH; L_0603_1608Metric
L4: 2.2uH; L_0805_2012Metric
L5: 13nH; L_0603_1608Metric
L6: 39nH; L_0603_1608Metric
L7: 20nH; L_0603_1608Metric
L8, L9: 470nH; L_0603_1608Metric
L10: 47nH; L_0603_1608Metric
L11: 68nH; L_0603_1608Metric
L12, L13: 4.7uH; R_0805_2012Metric
L14: 5.6nH; L_0603_1608Metric
Q1: AFT05MS004NT1; SOT-89-3
Q2, Q7: AO3401A; SOT-23
R1: 220R; R_0603_1608Metric
R2, R6, R9, R10, R11: 10k; R_0603_1608Metric
R3: 3k3; R_0603_1608Metric
R4: 22R; R_0603_1608Metric
R5: 47k; R_0603_1608Metric
R7: 51k; R_0603_1608Metric
R8: 16k; R_0603_1608Metric
R12, R13, R17: 1k1; R_0603_1608Metric
R14, R15, R16: 100R; R_0603_1608Metric
TP1: TP_1.0MM
TP2, TP3, TP4, TP5, TP6, TP7, TP8, TP9, TP10, TP11, TP12, TP13, TP14, TP15, TP16, TP17, TP18, TP19: TP_1.2MM
U1, U2: Si4460; QFN-20-1EP_4x4mm_P0.5mm_EP2.6x2.6mm_ThermalVias
U3: BGA2800,115; SOT-363_SC-70-6
U4: L76L-M33; XCVR_L76L-M33
U5: STM32L432KBUx; QFN-32-1EP_5x5mm_P0.5mm_EP3.45x3.45mm
U6: AP3211K; SOT-23-6
U7: 24LC01BT/OT; SOT-23-5
U8: SKY13330-397LF; QFN50P200X200X65-13N
U9, U10: SI1926DL-T1-E3; SOT-363_SC-70-6
Y1, Y2: ECS-300-10-33B-CKM-TR; Crystal_SMD_3225-4Pin_3.2x2.5mm

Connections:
+3.3V: C7.2, C8.2, C9.2, C10.2, C11.2, C12.2, C28.1, C34.2, C35.2, J2.1, L12.2, Q2.2 (S), Q7.2 (S), R4.1, R7.1, R9.1, TP8.1, U1.6 (VDD), U1.8 (VDD), U2.6 (VDD), U2.8 (VDD), U4.6 (V_BCKP), U5.1 (VDD), U5.5 (VDDA), U5.17 (VDD), U7.4 (V_{CC}), U8.8 (EN), U8.9 (VCC)
/Connections/GPS_STATUS: U5.21 (PA11), U9.2 (G1)
/Connections/HOST_GPS_STATUS: CR1.2, J1.4, R14.1
/Connections/HOST_RX_STATUS: CR1.7, J1.6, R15.1
/Connections/HOST_TX_OFF: CR1.1, D3.2 (A), J1.2
/Connections/HOST_TX_STATUS: CR1.6, J1.7, R16.1
/Connections/HOST_UART_RX: CR1.8, J1.5, R12.1
/Connections/HOST_UART_TX: CR1.9, J1.3, R13.1
/Connections/MCU_TX_OFF: U5.22 (PA12), U10.3 (D2)
/Connections/MCU_UART_RX: R13.2, TP12.1, U5.20 (PA10)
/Connections/MCU_UART_TX: R12.2, TP11.1, U5.19 (PA9)
/Connections/RX_STATUS: U5.7 (PA1), U9.5 (G2)
/Connections/TX_STATUS: U5.28 (PB5), U10.2 (G1)
/Connections/V_IN: C24.2, C25.2, IC1.5 (EN), IC1.6 (VIN), J1.1, L13.1, TP10.1
/GNSS/GPS_1PPS: U4.4 (1PPS), U5.8 (PA2)
/GNSS/GPS_EN: Q2.1 (G), R9.2, U5.2 (PC14)
/GNSS/GPS_OUT: U4.2 (TXD1), U5.9 (PA3)
/MCU/RX_CLK: U2.20 (GPIO3), U5.26 (PB3)
/MCU/RX_CS: U2.15 (~SEL), U5.6 (PA0)
/MCU/RX_DATA: U2.10 (GPIO1), U5.27 (PB4)
/MCU/RX_SDN: U2.1 (SDN), U5.25 (PA15)
/MCU/SPI_MISO: U1.13 (SDO), U2.13 (SDO), U5.12 (PA6)
/MCU/SPI_MOSI: U1.14 (SDI), U2.14 (SDI), U5.13 (PA7)
/MCU/SPI_SCK: U1.12 (SCLK), U2.12 (SCLK), U5.11 (PA5)
/MCU/TRX_CKL: U1.19 (GPIO2), U5.3 (PC15)
/MCU/TRX_CS: U1.15 (~SEL), U5.10 (PA4)
/MCU/TRX_DATA: U1.10 (GPIO1), U5.15 (PB1)
/MCU/TRX_SDN: U1.1 (SDN), U5.14 (PB0)
/MCU/V_PA_BIAS: R3.1, U5.18 (PA8)
/Power/V_PA: C13.2, C23.2, IC1.1 (VOUT), L4.1, R5.1, TP9.1
/Receiver/RF_IN: L2.2, U8.11 (RF2)
/Receiver/TRX_OUT: C21.1, L9.1, U1.4 (TX)
/Receiver/V_LNA: D4.2 (A), Q7.3 (D), R1.1, TP13.1
GND: C3.2, C6.1, C7.1, C8.1, C9.1, C10.1, C11.1, C12.1, C13.1, C14.1, C15.1, C17.1, C19.1, C20.1, C22.1, C23.1, C24.1, C25.1, C26.1, C28.2, C29.2, C30.1, C31.1, C32.1, C33.1, C34.1, C35.1, CR1.3, D1.2 (A), IC1.4 (GND_1), IC1.7 (GND_2), J1.8, J2.5, J3.G1, J3.G2, J3.G3, J3.G4, L3.1, Q1.2 (S), R2.2, R6.2, R8.2, R10.2, R11.2, TP2.1, TP3.1, TP4.1, TP5.1, TP6.1, TP7.1, TP18.1, TP19.1, U1.3 (RXn), U1.18 (GND), U1.21 (GND), U2.3 (RXn), U2.18 (GND), U2.21 (GND), U3.2 (G), U3.4 (G), U3.5 (G), U4.1 (GND), U4.10 (GND), U4.12 (GND), U5.16 (VSS), U5.32 (VSS), U5.33 (VSS), U6.2 (GND), U7.2 (V_{SS}), U7.5 (WP), U8.1 (GND), U8.3 (GND), U8.4 (GND), U8.6 (GND), U8.10 (GND), U8.12 (GND), U8.13 (GND), U9.1 (S1), U9.4 (S2), U10.1 (S1), U10.4 (S2), Y1.2, Y1.4, Y2.2, Y2.4
NRST: J2.4, TP17.1, U5.4 (NRST)
unnamed: AE1.1, C33.2, L14.1
unnamed: C1.2, U3.3
unnamed: C2.1, U3.6
unnamed: C2.2, L1.1
unnamed: C4.1, C5.1, C6.2, L3.2
unnamed: C4.2, L1.2
unnamed: C5.2, L2.1
unnamed: C14.2, L5.2, L6.1
unnamed: C15.2, C16.1, L6.2
unnamed: C17.2, C18.2, L7.1
unnamed: C18.1, L11.2
unnamed: C19.2, L8.2, R2.1, R3.2
unnamed: C20.2, L9.2, R4.2
unnamed: C21.2, L10.1
unnamed: C22.2, L10.2, L11.1
unnamed: C27.2, D1.1 (K), L12.1, U6.6 (SW)
unnamed: D3.1 (K), R17.2
unnamed: D4.1 (K), U8.7 (CTRL)
unnamed: IC1.2 (ADJ/NC), R5.2, R6.1
unnamed: L4.2, L5.1, Q1.3 (D)
unnamed: L7.2, L8.1, Q1.1 (G)
unnamed: C30.2, C31.2, Q2.3 (D), U4.8 (VCC)
unnamed: Q7.1 (G), U1.20 (GPIO3)
unnamed: J3.1, TP1.1, U8.2 (RF1)
unnamed: R10.1, TP14.1, U5.31 (PH3)
unnamed: C1.1, U1.2 (RXp), U2.2 (RXp)
unnamed: U1.17 (XIN), Y1.3
unnamed: U1.16 (XOUT), Y1.1
unnamed: U2.17 (XIN), Y2.3
unnamed: U2.16 (XOUT), Y2.1
unnamed: C3.1, R1.2, U3.1 (Vcc)
unnamed: C32.2, L14.2, U4.11 (RF_IN)
unnamed: U5.29 (PB6), U7.1 (SCL)
unnamed: U5.30 (PB7), U7.3 (SDA)
unnamed: C27.1, U6.1 (BS)
unnamed: C26.2, C29.1, L13.2, U6.4 (EN), U6.5 (IN)
unnamed: R7.2, R8.1, U6.3 (FB)
unnamed: R14.2, U9.6 (D1)
unnamed: R15.2, U9.3 (D2)
unnamed: R16.2, U10.6 (D1)
unnamed: R11.1, R17.1, U10.5 (G2)
PA_OUT: C16.2, U8.5 (RF3)
SWCLK: J2.3, TP16.1, U5.24 (PA14)
SWDIO: J2.2, TP15.1, U5.23 (PA13)

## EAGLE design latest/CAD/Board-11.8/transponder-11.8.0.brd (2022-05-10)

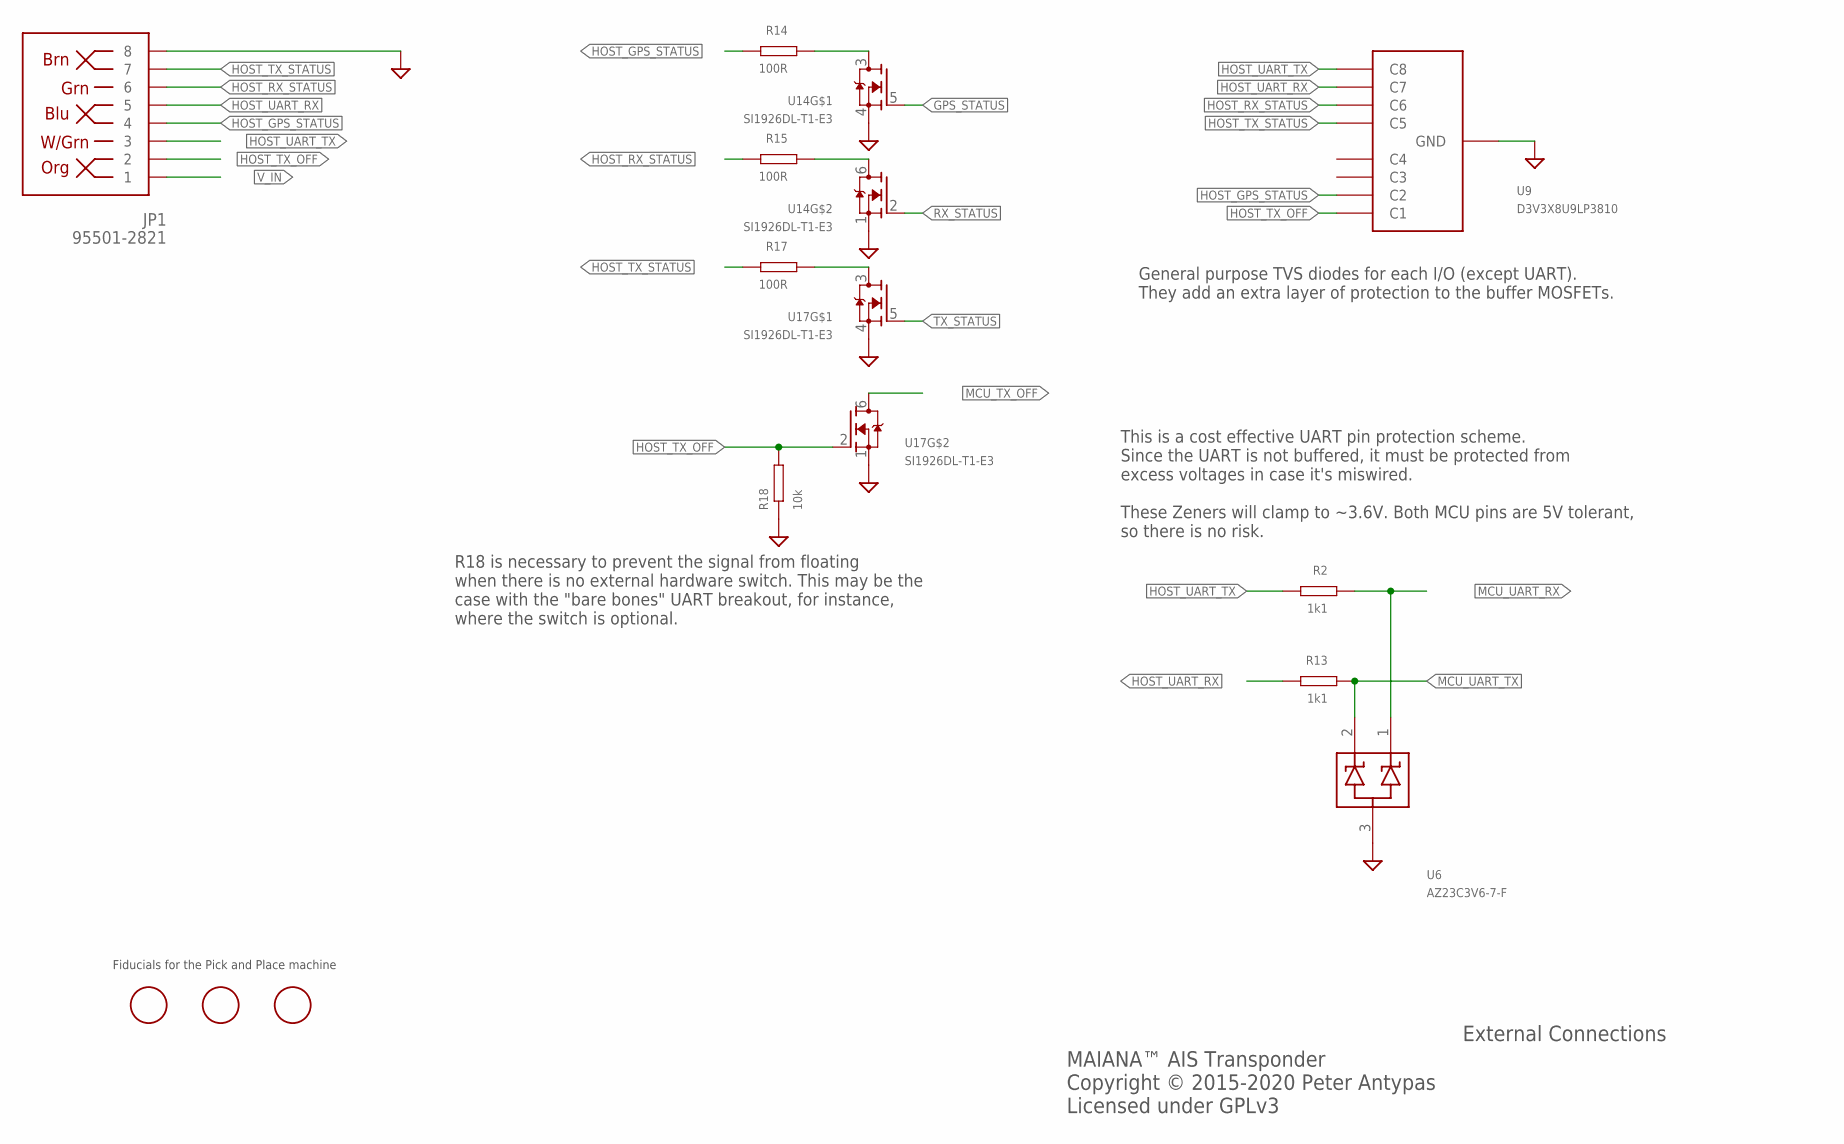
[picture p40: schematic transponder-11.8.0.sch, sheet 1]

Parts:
JP1: 95501-2821; RJ45-8; PARTNO 95501-2821
R2, R13: 1k1; 0603; PARTNO CR0603JA0112G
R14, R15, R17: 100R; 0603; PARTNO RMC1/16K101FTP
R18: 10k; 0603; PARTNO CR0603JA0103G
U6: AZ23C3V6-7-F; SOT-23; PARTNO AZ23C3V6-7-F
U9: D3V3X8U9LP3810; U-DFN3810-9(B)
U14, U17: SI1926DL-T1-E3; SOT363; PARTNO SI1926DL-T1-E3
U$1, U$2, U$3: FIDUCIAL; FIDUCIAL_1MM

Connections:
GND: JP1.8, R18.P$1, U6.3, U9.P$3 (GND), U14.1 (S), U14.4 (S), U17.1 (S), U17.4 (S); also elsewhere on the board
GPS_STATUS: U14.5 (G); also elsewhere on the board
HOST_GPS_STATUS: JP1.4, R14.P$2, U9.P$2 (C2)
HOST_RX_STATUS: JP1.6, R15.P$2, U9.P$7 (C6)
HOST_TX_OFF: JP1.2, R18.P$2, U9.P$1 (C1), U17.2 (G)
HOST_TX_STATUS: JP1.7, R17.P$2, U9.P$6 (C5)
HOST_UART_RX: JP1.5, R13.P$2, U9.P$8 (C7)
HOST_UART_TX: JP1.3, R2.P$2, U9.P$9 (C8)
MCU_TX_OFF: U17.6 (D); also elsewhere on the board
MCU_UART_RX: R2.P$1, U6.1; also elsewhere on the board
MCU_UART_TX: R13.P$1, U6.2; also elsewhere on the board
unnamed: R14.P$1, U14.3 (D)
unnamed: R15.P$1, U14.6 (D)
unnamed: R17.P$1, U17.3 (D)
RX_STATUS: U14.2 (G); also elsewhere on the board
TX_STATUS: U17.5 (G); also elsewhere on the board
V_IN: JP1.1; also elsewhere on the board

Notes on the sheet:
External Connections
MAIANA™ AIS Transponder Copyright © 2015-2020 Peter Antypas Licensed under GPLv3
Fiducials for the Pick and Place machine
R18 is necessary to prevent the signal from floating when there is no external hardware switch. This may be the case with the "bare bones" UART breakout, for instance, where the switch is optional.
This is a cost effective UART pin protection scheme. Since the UART is not buffered, it must be protected from excess voltages in case it's miswired. These Zeners will clamp to ~3.6V. Both MCU pins are 5V tolerant, so there is no risk.
General purpose TVS diodes for each I/O (except UART). They add an extra layer of protection to the buffer MOSFETs.

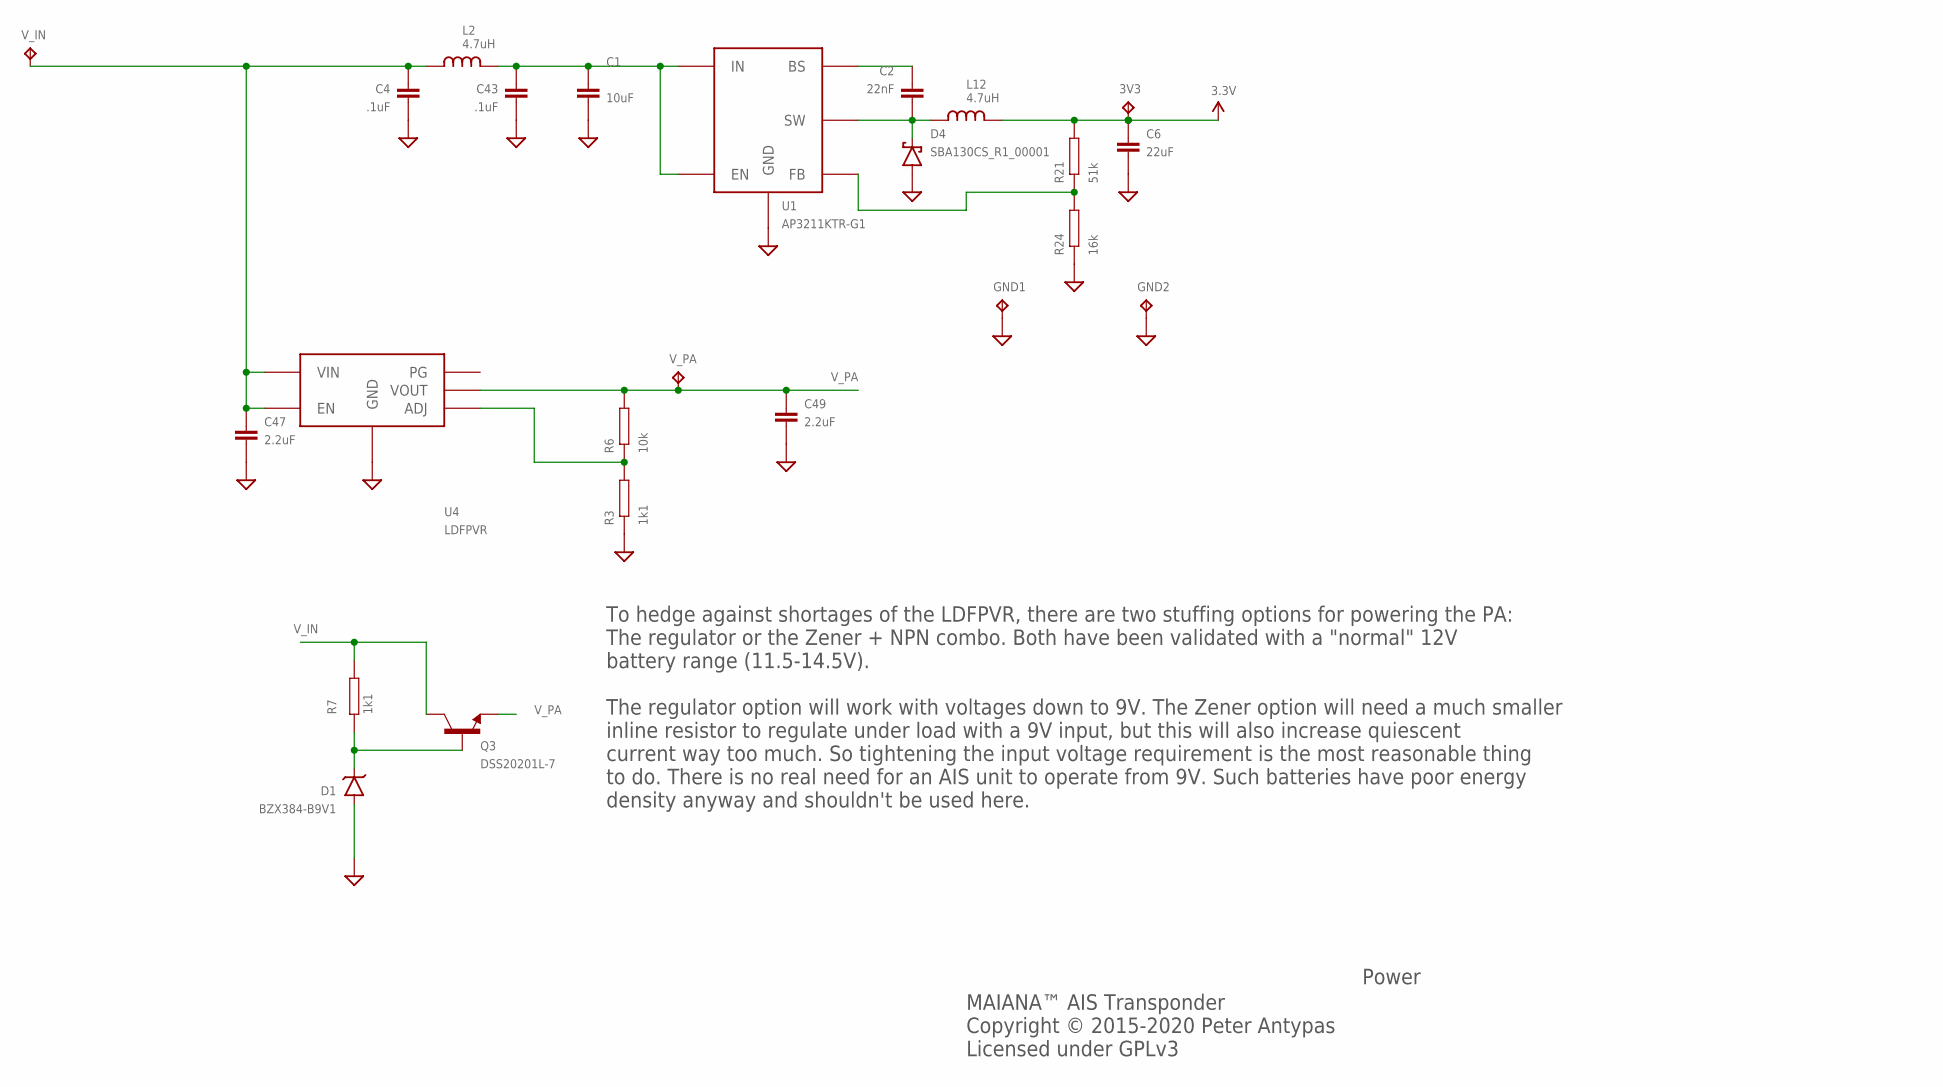
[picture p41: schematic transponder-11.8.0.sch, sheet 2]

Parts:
3V3: TPTP12R; TP12R
C1: 10uF; 0805; PARTNO EMK212ABJ106KG-T
C2: 22nF; 0603; PARTNO CL10B223KA8NNNC
C4, C43: .1uF; 0603; PARTNO 0603B104K250CT
C6: 22uF; 0805; PARTNO CL21A226KOQNNNE
C47, C49: 2.2uF; 0603; PARTNO 0603X225K160CT
D1: BZX384-B9V1; SOD323; PARTNO BZX384-B9V1
D4: SBA130CS_R1_00001; SOD323; PARTNO SBA130CS_R1_00001
GND1, GND2: TPTP12R; TP12R
L2, L12: 4.7uH; 0805; PARTNO CMP201209UD4R7MT
Q3: DSS20201L-7; SOT23-3; PARTNO DSS20201L-7
R3, R7: 1k1; 0603; PARTNO CR0603JA0112G
R6: 10k; 0603; PARTNO CR0603JA0103G
R21: 51k; 0603; PARTNO CR0603FA5102G
R24: 16k; 0603; PARTNO RC0603FR-0716KL
U1: AP3211KTR-G1; SOT23-6; PARTNO AP3211KTR-G1
U4: LDFPVR; DFN6-2X2
V_IN: TPTP12R; TP12R
V_PA: TPTP12R; TP12R

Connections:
3.3V: 3V3.TP, C6.P$1 (1), L12.P$2 (2), R21.P$2; also elsewhere on the board
GND: C1.P$2 (2), C4.P$2 (2), C6.P$2 (2), C43.P$2 (2), C47.P$2 (2), C49.P$2 (2), D1.A, D4.A, GND1.TP, GND2.TP, R3.P$1, R24.P$1, U1.2 (GND), U4.P$4 (GND), U4.P$7 (GND); also elsewhere on the board
unnamed: C2.P$2 (2), D4.C, L12.P$1 (1), U1.6 (SW)
unnamed: D1.C, Q3.1 (B), R7.P$1
unnamed: C2.P$1 (1), U1.1 (BS)
unnamed: R21.P$1, R24.P$2, U1.3 (FB)
unnamed: C1.P$1 (1), C43.P$1 (1), L2.P$2 (2), U1.4 (EN), U1.5 (IN)
unnamed: R3.P$2, R6.P$1, U4.P$2 (ADJ)
V_IN: C4.P$1 (1), C47.P$1 (1), L2.P$1 (1), Q3.3 (C), R7.P$2, U4.P$5 (EN), U4.P$6 (VIN), V_IN.TP; also elsewhere on the board
V_PA: C49.P$1 (1), Q3.2 (E), R6.P$2, U4.P$1 (VOUT), V_PA.TP; also elsewhere on the board

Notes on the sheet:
MAIANA™ AIS Transponder Copyright © 2015-2020 Peter Antypas Licensed under GPLv3
Power
To hedge against shortages of the LDFPVR, there are two stuffing options for powering the PA: The regulator or the Zener + NPN combo. Both have been validated with a "normal" 12V battery range (11.5-14.5V). The regulator option will work with voltages down to 9V. The Zener option will need a much s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

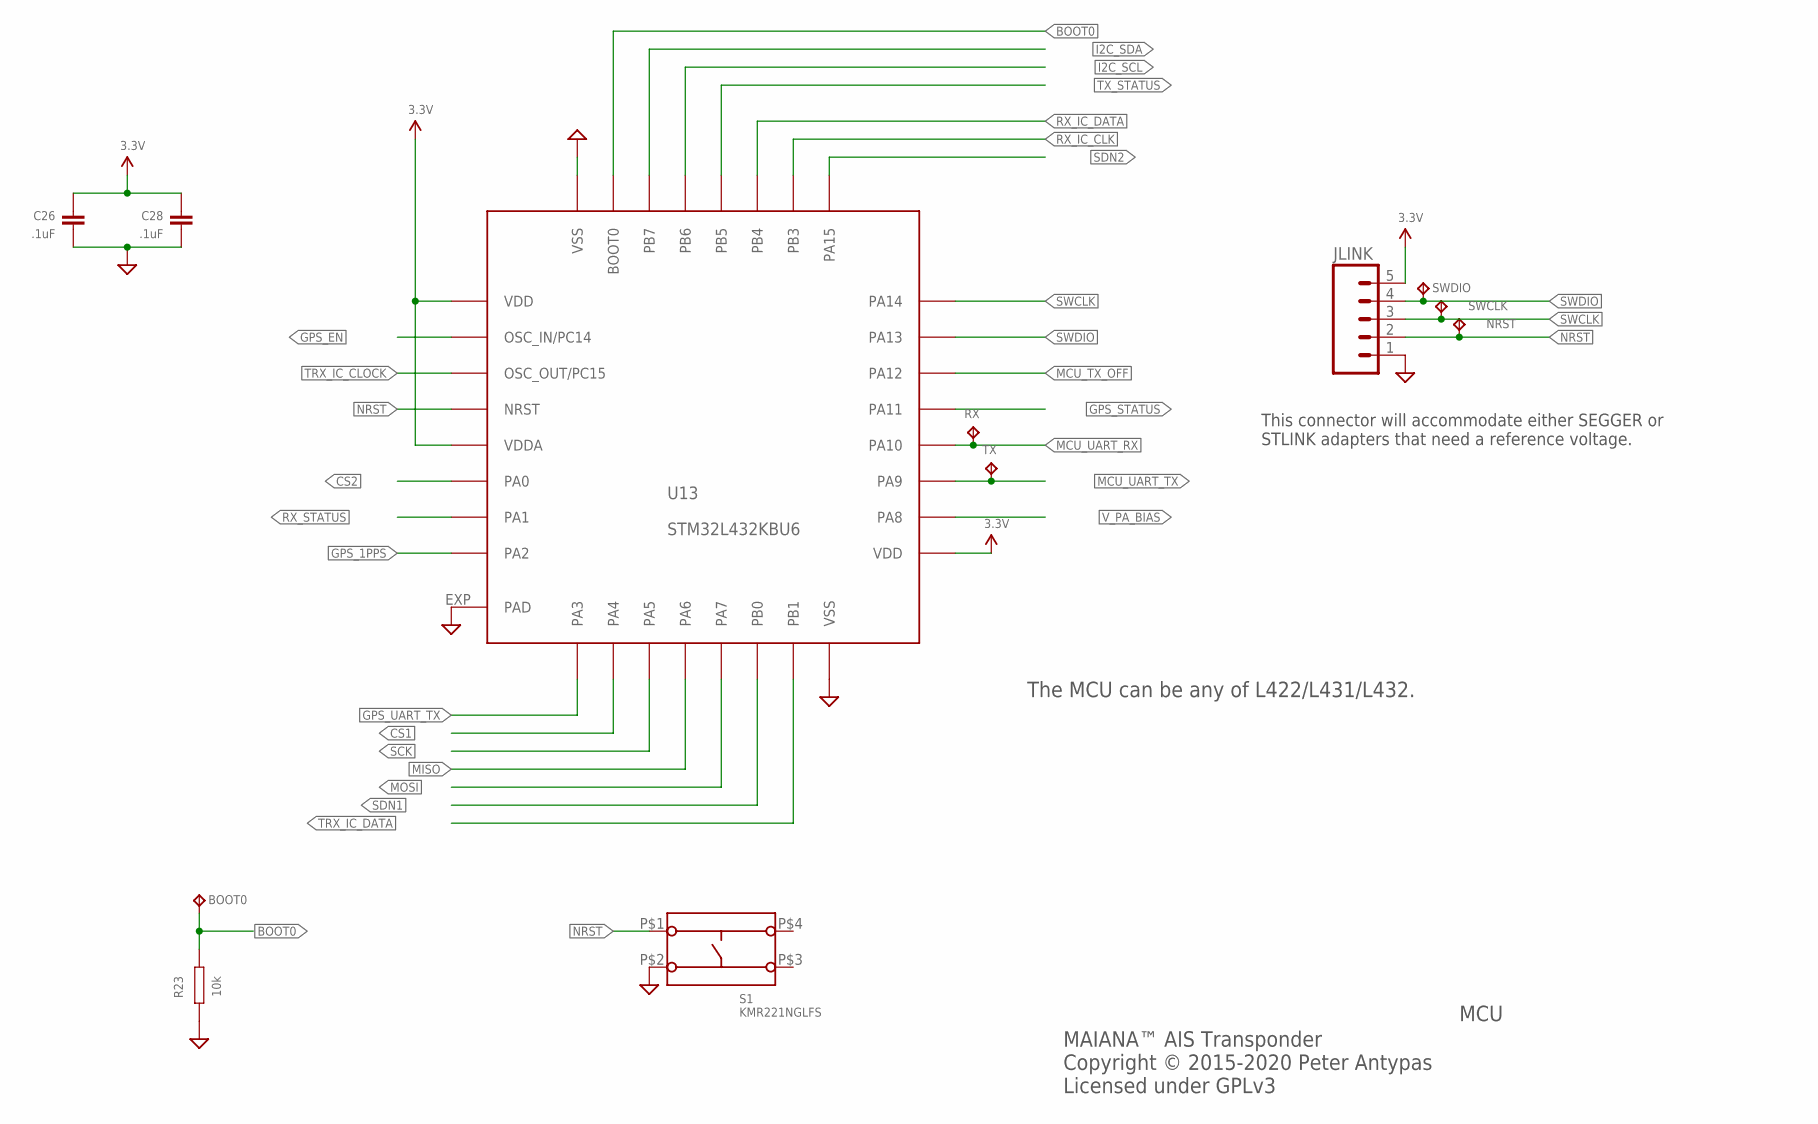
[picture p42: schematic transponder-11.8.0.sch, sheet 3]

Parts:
BOOT0: TPTP12R; TP12R
C26, C28: .1uF; 0603; PARTNO 0603B104K250CT
JLINK: M05PTH; 1X05
NRST: TPTP12R; TP12R
R23: 10k; 0603; PARTNO CR0603JA0103G
RX: TPTP12R; TP12R
S1: KMR221NGLFS
SWCLK: TPTP12R; TP12R
SWDIO: TPTP12R; TP12R
TX: TPTP12R; TP12R
U13: STM32L432KBU6; QFN32; PARTNO STM32L432KBU6

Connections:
3.3V: C26.P$1 (1), C28.P$1 (1), JLINK.5, U13.1 (VDD), U13.5 (VDDA), U13.17 (VDD); also elsewhere on the board
BOOT0: BOOT0.TP, R23.P$1, U13.31 (BOOT0)
CS1: U13.10 (PA4); also elsewhere on the board
CS2: U13.6 (PA0); also elsewhere on the board
GND: C26.P$2 (2), C28.P$2 (2), JLINK.1, R23.P$2, S1.P$2 (S2), U13.16 (VSS), U13.32 (VSS), U13.EXP (PAD); also elsewhere on the board
GPS_1PPS: U13.8 (PA2); also elsewhere on the board
GPS_EN: U13.2 (OSC_IN/PC14); also elsewhere on the board
GPS_STATUS: U13.21 (PA11); also elsewhere on the board
GPS_UART_TX: U13.9 (PA3); also elsewhere on the board
I2C_SCL: U13.29 (PB6); also elsewhere on the board
I2C_SDA: U13.30 (PB7); also elsewhere on the board
MCU_TX_OFF: U13.22 (PA12); also elsewhere on the board
MCU_UART_RX: RX.TP, U13.20 (PA10); also elsewhere on the board
MCU_UART_TX: TX.TP, U13.19 (PA9); also elsewhere on the board
MISO: U13.12 (PA6); also elsewhere on the board
MOSI: U13.13 (PA7); also elsewhere on the board
NRST: JLINK.2, NRST.TP, S1.P$1 (S1), U13.4 (NRST)
RX_IC_CLK: U13.26 (PB3); also elsewhere on the board
RX_IC_DATA: U13.27 (PB4); also elsewhere on the board
RX_STATUS: U13.7 (PA1); also elsewhere on the board
SCK: U13.11 (PA5); also elsewhere on the board
SDN1: U13.14 (PB0); also elsewhere on the board
SDN2: U13.25 (PA15); also elsewhere on the board
SWCLK: JLINK.3, SWCLK.TP, U13.24 (PA14)
SWDIO: JLINK.4, SWDIO.TP, U13.23 (PA13)
TRX_IC_CLOCK: U13.3 (OSC_OUT/PC15); also elsewhere on the board
TRX_IC_DATA: U13.15 (PB1); also elsewhere on the board
TX_STATUS: U13.28 (PB5); also elsewhere on the board
V_PA_BIAS: U13.18 (PA8); also elsewhere on the board

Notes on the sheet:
MCU
MAIANA™ AIS Transponder Copyright © 2015-2020 Peter Antypas Licensed under GPLv3
The MCU can be any of L422/L431/L432.
This connector will accommodate either SEGGER or STLINK adapters that need a reference voltage.

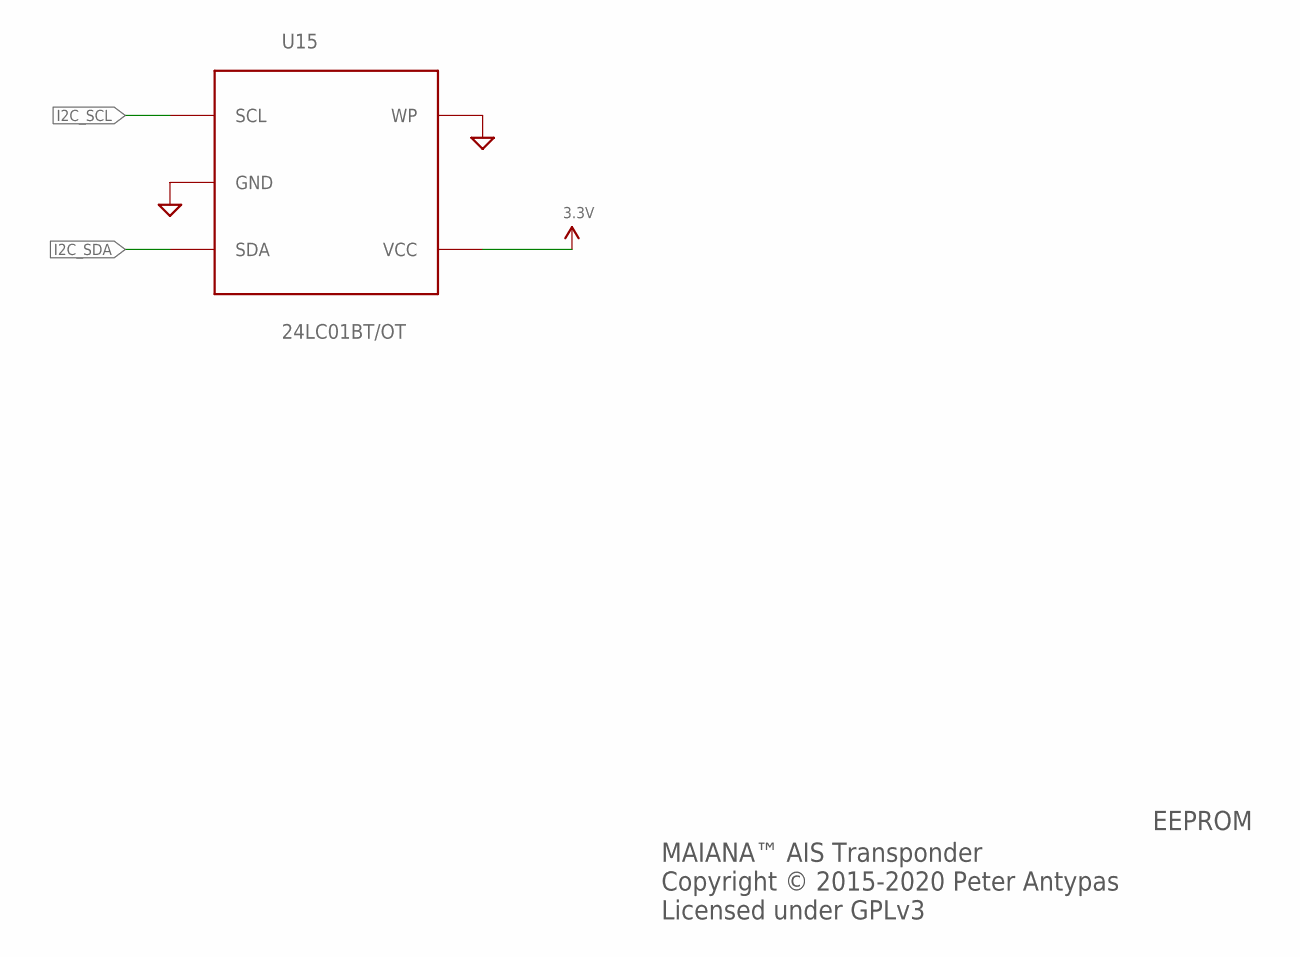
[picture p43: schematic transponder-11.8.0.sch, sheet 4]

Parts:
U15: 24LC01BT/OT; SOT23-5; PARTNO 24LC01BT/OT

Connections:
3.3V: U15.4 (VCC); also elsewhere on the board
GND: U15.2 (GND), U15.5 (WP); also elsewhere on the board
I2C_SCL: U15.1 (SCL); also elsewhere on the board
I2C_SDA: U15.3 (SDA); also elsewhere on the board

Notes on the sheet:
EEPROM
MAIANA™ AIS Transponder Copyright © 2015-2020 Peter Antypas Licensed under GPLv3

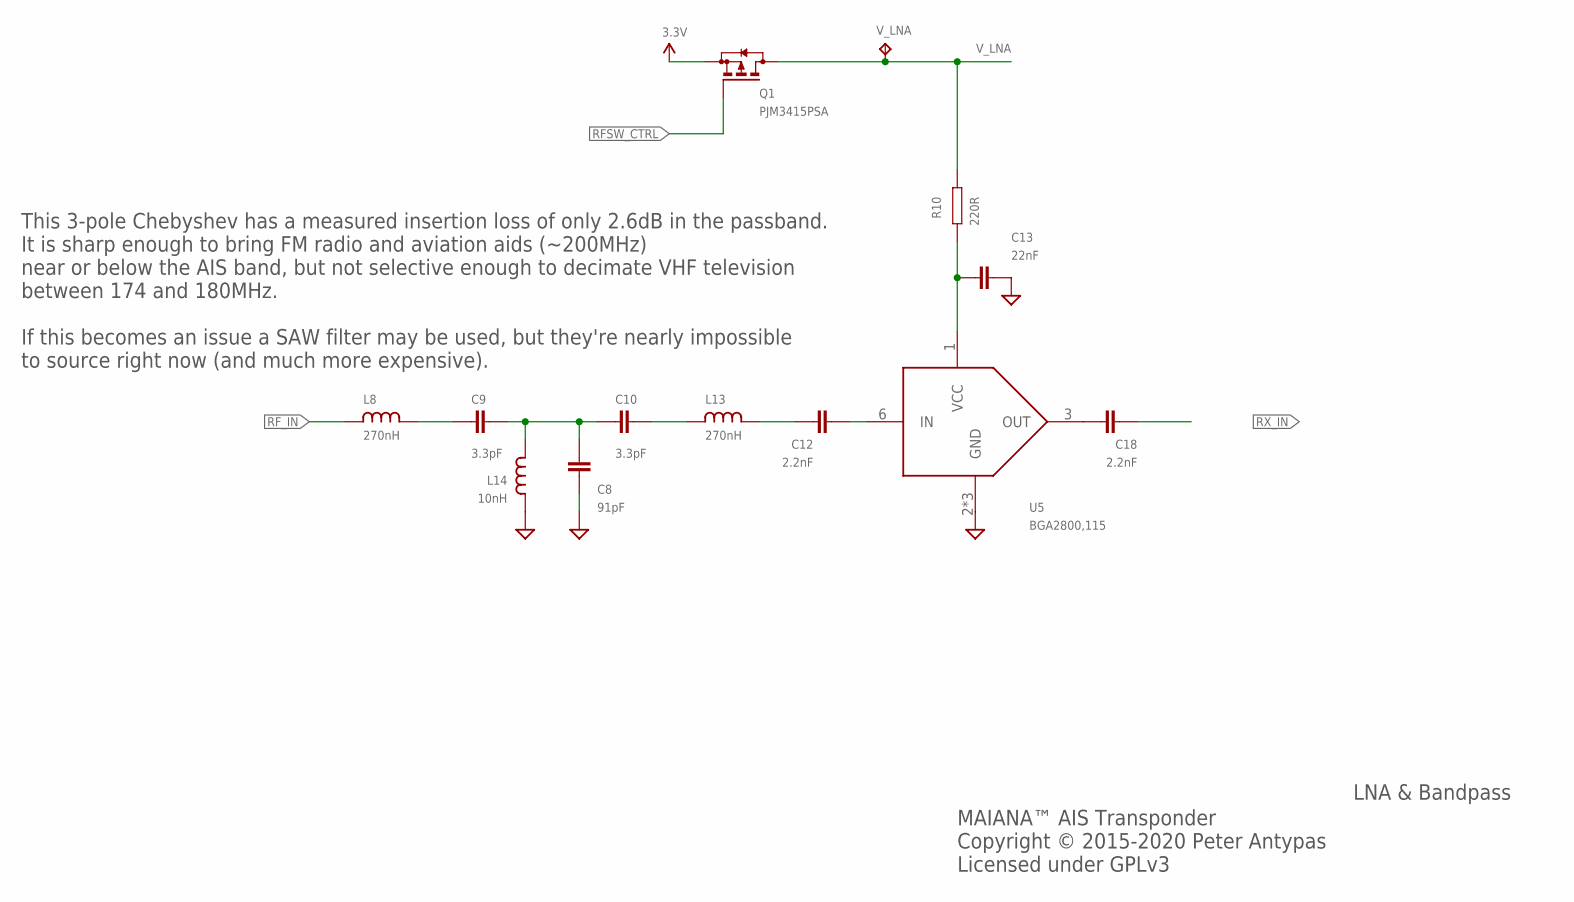
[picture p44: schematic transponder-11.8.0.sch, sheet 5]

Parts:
C8: 91pF; 0603; PARTNO CC0603JRNPO9BN910
C9, C10: 3.3pF; 0603; PARTNO 0603N3R3B500CT
C12, C18: 2.2nF; 0603; PARTNO 0603N222J500CT
C13: 22nF; 0603; PARTNO CL10B223KA8NNNC
L8, L13: 270nH; 0603; PARTNO LQW18ANR27G00D
L14: 10nH; 0603; PARTNO LQW18AN10NG00D
Q1: PJM3415PSA; SOT23; PARTNO PJM3415PSA
R10: 220R; 0603; PARTNO CR0603FA2200G
U5: BGA2800,115; SOT363; PARTNO BGA2800,115
V_LNA: TPTP12R; TP12R

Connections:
3.3V: Q1.2 (S); also elsewhere on the board
GND: C8.P$2 (2), C13.P$2 (2), L14.P$1 (1), U5.2 (GND), U5.4 (GND), U5.5 (GND); also elsewhere on the board
unnamed: C12.P$2 (2), U5.6 (IN)
unnamed: C9.P$1 (1), L8.P$2 (2)
unnamed: C8.P$1 (1), C9.P$2 (2), C10.P$1 (1), L14.P$2 (2)
unnamed: C10.P$2 (2), L13.P$1 (1)
unnamed: C12.P$1 (1), L13.P$2 (2)
unnamed: C13.P$1 (1), R10.P$2, U5.1 (VCC)
unnamed: C18.P$1 (1), U5.3 (OUT)
RFSW_CTRL: Q1.1 (G); also elsewhere on the board
RF_IN: L8.P$1 (1); also elsewhere on the board
RX_IN: C18.P$2 (2); also elsewhere on the board
V_LNA: Q1.3 (D), R10.P$1, V_LNA.TP; also elsewhere on the board

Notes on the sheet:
LNA & Bandpass
MAIANA™ AIS Transponder Copyright © 2015-2020 Peter Antypas Licensed under GPLv3
This 3-pole Chebyshev has a measured insertion loss of only 2.6dB in the passband. It is sharp enough to bring FM radio and aviation aids (~200MHz) near or below the AIS band, but not selective enough to decimate VHF television between 174 and 180MHz. If this becomes an issue a SAW filter may be us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

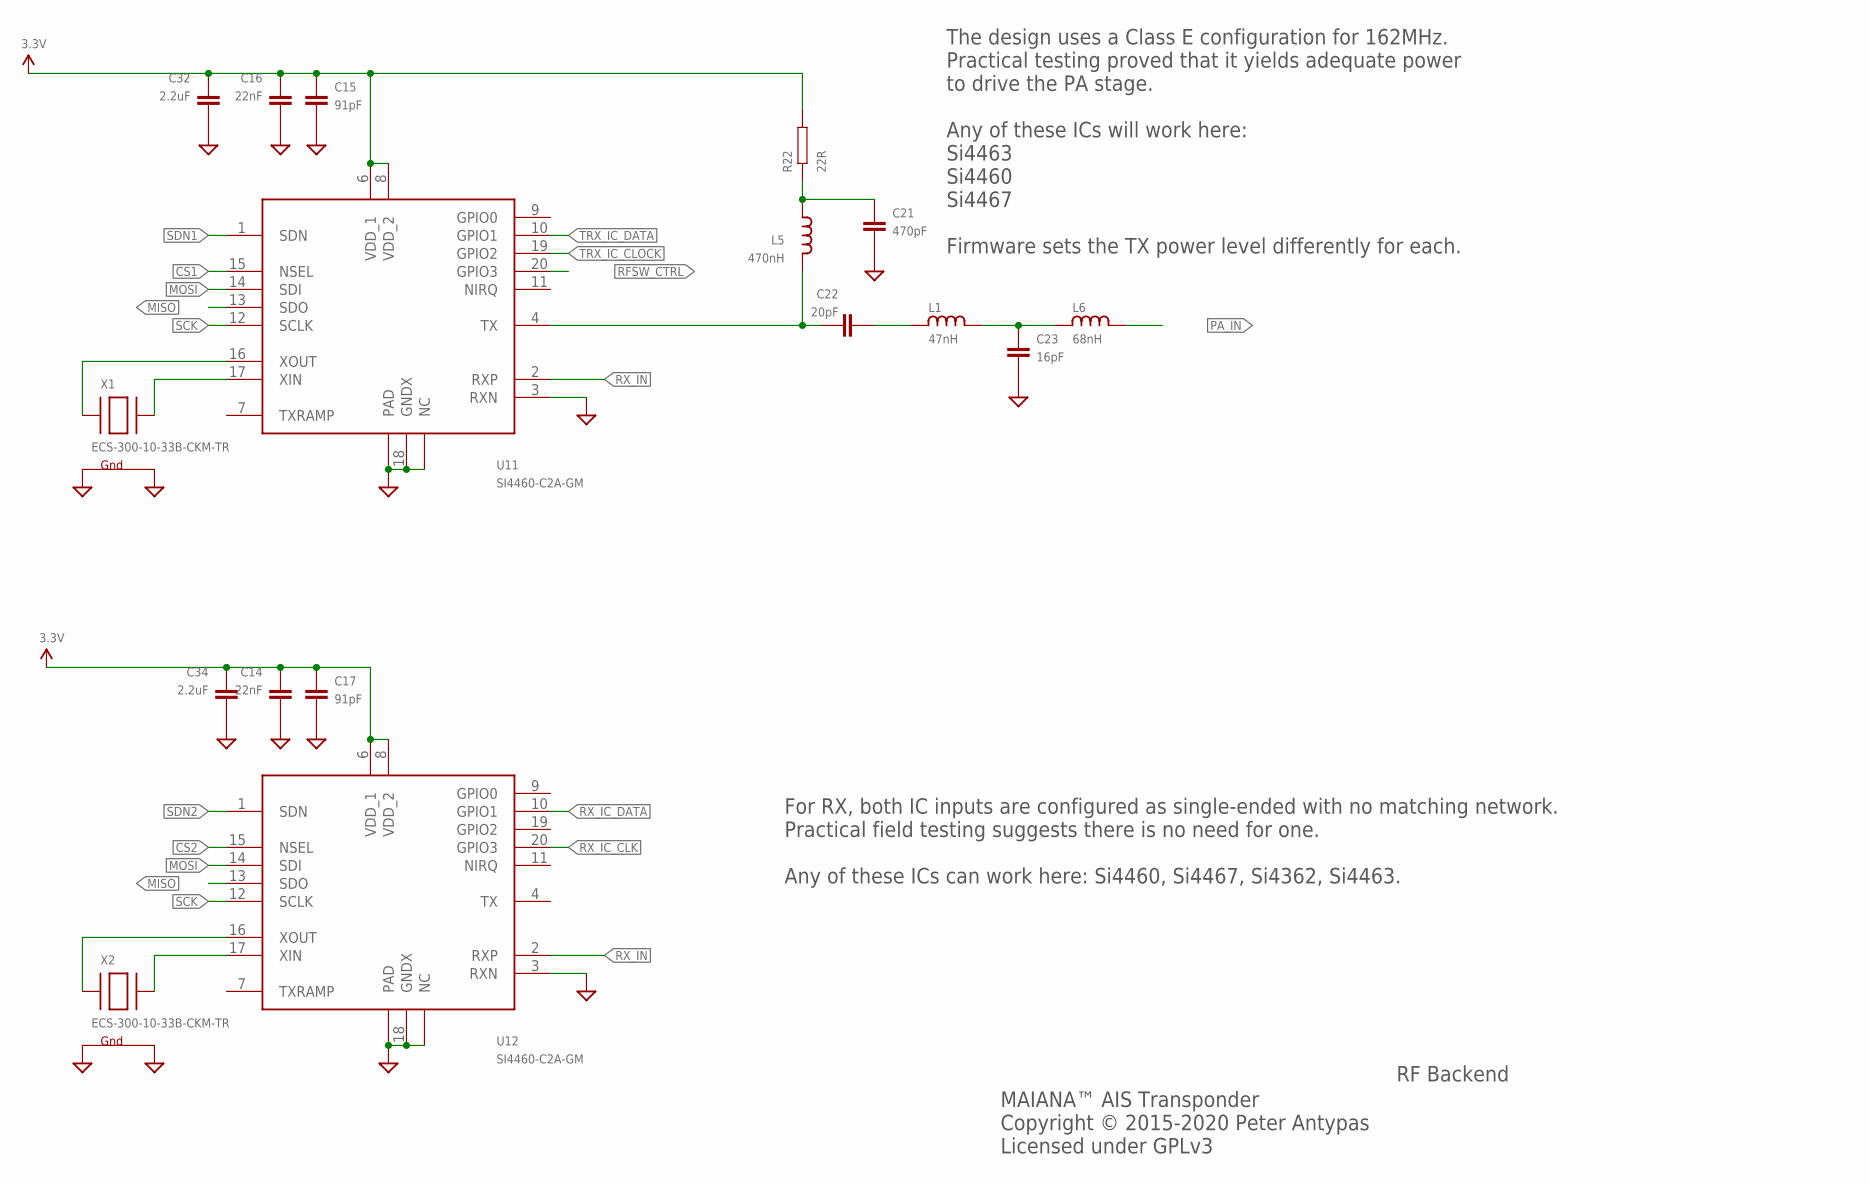
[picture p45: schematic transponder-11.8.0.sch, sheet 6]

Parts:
C14, C16: 22nF; 0603; PARTNO CL10B223KA8NNNC
C15, C17: 91pF; 0603; PARTNO CC0603JRNPO9BN910
C21: 470pF; 0603; PARTNO 0603B471K500CT
C22: 20pF; 0603; PARTNO CL10C200JB8NNNC
C23: 16pF; 0603; PARTNO 0603N160G500CT
C32, C34: 2.2uF; 0603; PARTNO 0603X225K160CT
L1: 47nH; 0603; PARTNO LQW18AN47NG00D
L5: 470nH; 0603; PARTNO HBLS1608-R47J
L6: 68nH; 0603; PARTNO LQW18AN68NG00D
R22: 22R; 0603; PARTNO RC0603JR-0722RL
U11, U12: SI4460-C2A-GM; QFN20; PARTNO SI4460-C2A-GM
X1, X2: ECS-300-10-33B-CKM-TR; NX3225; PARTNO ECS-300-10-33B-CKM-TR

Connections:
3.3V: C14.P$1 (1), C15.P$1 (1), C16.P$1 (1), C17.P$1 (1), C32.P$1 (1), C34.P$1 (1), R22.P$2, U11.6 (VDD_1), U11.8 (VDD_2), U12.6 (VDD_1), U12.8 (VDD_2); also elsewhere on the board
CS1: U11.15 (NSEL); also elsewhere on the board
CS2: U12.15 (NSEL); also elsewhere on the board
GND: C14.P$2 (2), C15.P$2 (2), C16.P$2 (2), C17.P$2 (2), C21.P$2 (2), C23.P$2 (2), C32.P$2 (2), C34.P$2 (2), U11.3 (RXN), U11.5 (NC), U11.18 (GNDX), U11.EXP (PAD), U12.3 (RXN), U12.5 (NC), U12.18 (GNDX), U12.EXP (PAD), X1.2 (G2), X1.4 (G1), X2.2 (G2), X2.4 (G1); also elsewhere on the board
MISO: U11.13 (SDO), U12.13 (SDO); also elsewhere on the board
MOSI: U11.14 (SDI), U12.14 (SDI); also elsewhere on the board
unnamed: C23.P$1 (1), L1.P$2 (2), L6.P$1 (1)
unnamed: U12.16 (XOUT), X2.1 (X1)
unnamed: U12.17 (XIN), X2.3 (X2)
unnamed: U11.16 (XOUT), X1.1 (X1)
unnamed: U11.17 (XIN), X1.3 (X2)
unnamed: C22.P$1 (1), L5.P$2 (2), U11.4 (TX)
unnamed: C21.P$1 (1), L5.P$1 (1), R22.P$1
unnamed: C22.P$2 (2), L1.P$1 (1)
PA_IN: L6.P$2 (2); also elsewhere on the board
RFSW_CTRL: U11.20 (GPIO3); also elsewhere on the board
RX_IC_CLK: U12.20 (GPIO3); also elsewhere on the board
RX_IC_DATA: U12.10 (GPIO1); also elsewhere on the board
RX_IN: U11.2 (RXP), U12.2 (RXP); also elsewhere on the board
SCK: U11.12 (SCLK), U12.12 (SCLK); also elsewhere on the board
SDN1: U11.1 (SDN); also elsewhere on the board
SDN2: U12.1 (SDN); also elsewhere on the board
TRX_IC_CLOCK: U11.19 (GPIO2); also elsewhere on the board
TRX_IC_DATA: U11.10 (GPIO1); also elsewhere on the board

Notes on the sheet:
RF Backend
MAIANA™ AIS Transponder Copyright © 2015-2020 Peter Antypas Licensed under GPLv3
The design uses a Class E configuration for 162MHz. Practical testing proved that it yields adequate power to drive the PA stage. Any of these ICs will work here: Si4463 Si4460 Si4467 Firmware sets the TX power level differently for each.
For RX, both IC inputs are configured as single-ended with no matching network. Practical field testing suggests there is no need for one. Any of these ICs can work here: Si4460, Si4467, Si4362, Si4463.

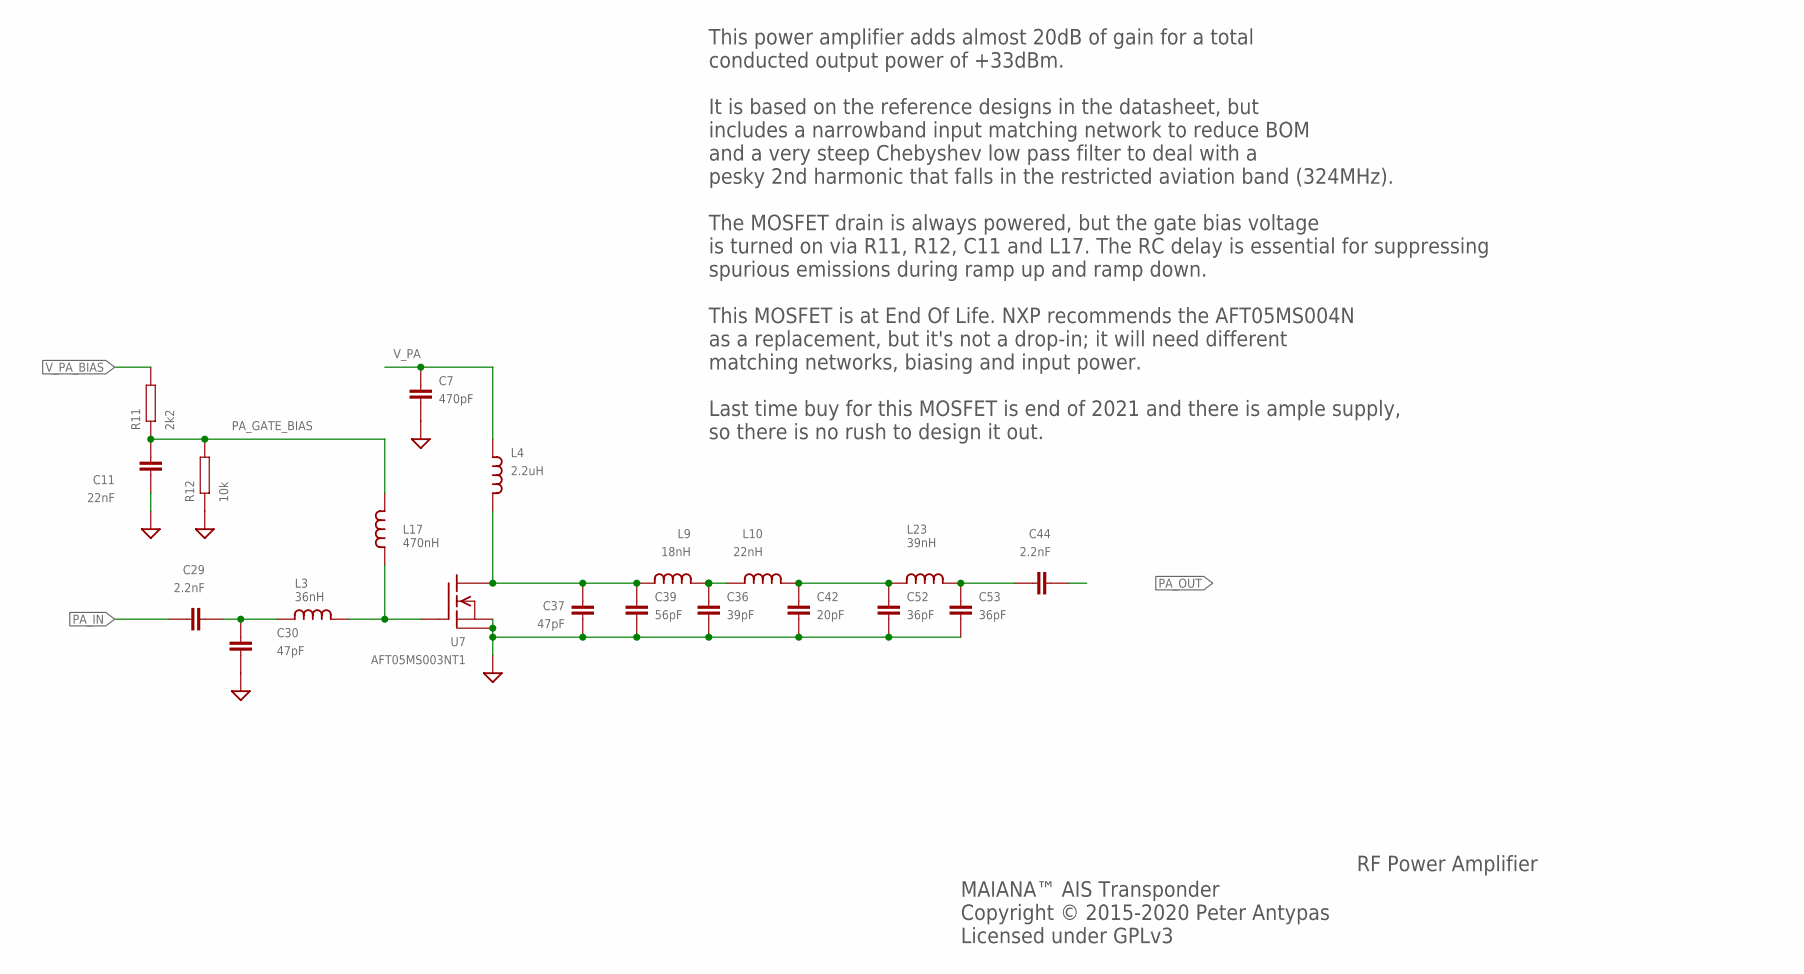
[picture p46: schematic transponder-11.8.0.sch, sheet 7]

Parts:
C7: 470pF; 0603; PARTNO 0603B471K500CT
C11: 22nF; 0603; PARTNO CL10B223KA8NNNC
C29, C44: 2.2nF; 0603; PARTNO 0603N222J500CT
C30, C37: 47pF; 0603; PARTNO 0603N470J500LT
C36: 39pF; 0603; PARTNO 0603N390J500CT
C39: 56pF; 0603; PARTNO 0603N560J500CT
C42: 20pF; 0603; PARTNO CL10C200JB8NNNC
C52, C53: 36pF; 0603; PARTNO 0603N360J500CT
L3: 36nH; 0603; PARTNO LQW18AN36NG00D
L4: 2.2uH; 0805; PARTNO LQM21PN2R2MGSD
L9: 18nH; 0603; PARTNO LQW18AN18NG00D
L10: 22nH; 0603; PARTNO LQW18AN22NJ00D
L17: 470nH; 0603; PARTNO HBLS1608-R47J
L23: 39nH; 0603; PARTNO LQW18AN39NG00D
R11: 2k2; 0603; PARTNO RC0603FR-072K2L
R12: 10k; 0603; PARTNO CR0603JA0103G
U7: AFT05MS003NT1; SOT-89; PARTNO AFT05MS003NT1

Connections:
GND: C7.P$2 (2), C11.P$2 (2), C30.P$2 (2), C36.P$2 (2), C37.P$2 (2), C39.P$2 (2), C42.P$2 (2), C52.P$2 (2), C53.P$2 (2), R12.P$1, U7.2 (S), U7.2@1 (PAD); also elsewhere on the board
unnamed: C37.P$1 (1), C39.P$1 (1), L4.P$2 (2), L9.P$1 (1), U7.3 (D)
unnamed: L3.P$2 (2), L17.P$1 (1), U7.1 (G)
unnamed: C36.P$1 (1), L9.P$2 (2), L10.P$1 (1)
unnamed: C29.P$2 (2), C30.P$1 (1), L3.P$1 (1)
unnamed: C42.P$1 (1), C52.P$1 (1), L10.P$2 (2), L23.P$1 (1)
unnamed: C44.P$1 (1), C53.P$1 (1), L23.P$2 (2)
PA_GATE_BIAS: C11.P$1 (1), L17.P$2 (2), R11.P$1, R12.P$2
PA_IN: C29.P$1 (1); also elsewhere on the board
PA_OUT: C44.P$2 (2); also elsewhere on the board
V_PA: C7.P$1 (1), L4.P$1 (1); also elsewhere on the board
V_PA_BIAS: R11.P$2; also elsewhere on the board

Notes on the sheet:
RF Power Amplifier
MAIANA™ AIS Transponder Copyright © 2015-2020 Peter Antypas Licensed under GPLv3
This power amplifier adds almost 20dB of gain for a total conducted output power of +33dBm. It is based on the reference designs in the datasheet, but includes a narrowband input matching network to reduce BOM and a very steep Chebyshev low pass filter to deal with a pesky 2nd harmonic that falls i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


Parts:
C3: 2.2uF; 0603; PARTNO 0603X225K160CT
C5: 22nF; 0603; PARTNO CL10B223KA8NNNC
Q2: PJM3415PSA; SOT23; PARTNO PJM3415PSA
R1: 10k; 0603; PARTNO CR0603JA0103G
U2: L76L-M33; GPS_MODULE; PARTNO L76L-M33
U10: 1575AT43A0040E; PARTNO 1575AT43A0040E
Z1: 5.6nH; 0603; PARTNO LQW18AN5N6C00D
Z2: 2.2pF; 0603; PARTNO 0603N2R2B500CT
Z3: 4pF; 0603; PARTNO RF18N4R0B500CT

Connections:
3.3V: Q2.2 (S), R1.P$2, U2.P$6 (VBAT); also elsewhere on the board
GND: C3.P$2 (2), C5.P$2 (2), U2.P$1 (GND), U2.P$10 (GND), U2.P$12 (GND), Z2.P$1, Z3.P$1; also elsewhere on the board
GPS_1PPS: U2.P$4 (1PPS); also elsewhere on the board
GPS_EN: Q2.1 (G), R1.P$1; also elsewhere on the board
GPS_UART_TX: U2.P$2 (TX); also elsewhere on the board
unnamed: C3.P$1 (1), C5.P$1 (1), Q2.3 (D), U2.P$8 (VCC)
unnamed: U10.P$1 (RF), Z1.P$1, Z2.P$2
unnamed: U2.P$11 (RFIN), Z1.P$2, Z3.P$2

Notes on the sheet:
GNSS
MAIANA™ AIS Transponder Copyright © 2015-2020 Peter Antypas Licensed under GPLv3
The GNSS RTC is always powered, but its main voltage rail is only turned on explicitly via firmware. This scheme was necessary to prevent the UART output from hijacking the ST ROM bootloader during firmware update. With the migration to a new bootloader this isn't necessary anymore, but I'm leaving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

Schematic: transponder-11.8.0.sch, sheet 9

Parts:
J$1: SMA_EDGE; SMA-EDGE
R4: 10k; 0603; PARTNO CR0603JA0103G
R5: 16k; 0603; PARTNO RC0603FR-0716KL
RF: TPTP10R; TP10R
SWDIO1, SWDIO2, SWDIO3, SWDIO4, SWDIO5, SWDIO6: TPTP12R; TP12R
U3: SKY13330-397LF; QFN12; PARTNO SKY13330-397LF

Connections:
3.3V: U3.P$8 (EN), U3.P$9 (VCC); also elsewhere on the board
GND: J$1.GND@0 (GND), J$1.GND@1 (GND), J$1.GND@2 (GND), J$1.GND@3 (GND), R5.P$1, SWDIO1.TP, SWDIO2.TP, SWDIO3.TP, SWDIO4.TP, SWDIO5.TP, SWDIO6.TP, U3.P$1 (GND), U3.P$3 (GND), U3.P$4 (GND), U3.P$6 (GND), U3.P$10 (GND), U3.P$12 (GND), U3.P$13 (GND); also elsewhere on the board
unnamed: J$1.SIG (SIGNAL), RF.TP, U3.P$2 (RF1)
PA_OUT: U3.P$5 (RF3); also elsewhere on the board
RF_IN: U3.P$11 (RF2); also elsewhere on the board
RX_EN: R4.P$2, R5.P$2, U3.P$7 (CTRL)
V_LNA: R4.P$1; also elsewhere on the board

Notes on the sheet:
Antenna Switch
MAIANA™ AIS Transponder Copyright © 2015-2020 Peter Antypas Licensed under GPLv3
This is a reasonably good RF switch which does not need DC blocking caps. That said, it requires control voltages to be below 2.7V, so a voltage divider was added. RX_EN must be high during RX The 9 test pads here form a footprint for a coaxial pogo pin probe in the test jig.

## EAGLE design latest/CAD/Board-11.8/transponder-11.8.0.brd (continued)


Board: 4 copper layers, 84.0 x 25.0 mm, 121 parts (0 on the bottom side), 79 nets.

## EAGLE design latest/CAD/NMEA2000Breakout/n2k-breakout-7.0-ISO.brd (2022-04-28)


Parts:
C1, C3, C10, C11, C14: 1uF; 0603; PARTNO CC0603KRX5R8BB105
C4, C5, C13: 0.1uF; 0603; PARTNO 06035C104KAT2A
D1: SMBJ14CA; SMB-BIDIR; PARTNO SMBJ14CA
D2, D4, D5, D6, D7: DIODE-SCHOTTKYSOD323; SOD323
D3: PESD1CAN-UX; SOT65P210X110-3N; PARTNO PESD1CAN-UX
F1: BSMD1206-050-16V; R1206; PARTNO BSMD1206-050-16V
IC2: TJ5205SF5-5.0; SOT23-5; PARTNO TJ5205SF5-5.0
J2: RJ-82A86MMNL
J3: 10118194-0001LF; AMPHENOL_10118194-0001LF; PARTNO 10118194-0001LF
J4: 12-3701-05; MICRO_C_5PIN
Q3: SI2307CDS-T1-E3; SOT23; PARTNO SI2307CDS-T1-E3
Q4: BSS138; SOT23; PARTNO BSS138
R1, R8: 10k; 0603; PARTNO RC0603FR-0710KL
R10, R11: 0R; 0603
U1: π122U31; SOIC8; PARTNO π122U31
U6: SE8533X2-HF; SOT23; PARTNO SE8533X2-HF
U$1: CH340N; SOIC-8; PARTNO CH340N
U$2, U$3, U$4: FIDUCIAL; FIDUCIAL_1MM

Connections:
3.3V: C1.P$1 (1), U1.8 (VDD2), U6.2 (VO); also elsewhere on the board
5V: C3.P$1 (1), C10.P$1 (1), IC2.5 (OUT), U6.3 (VIN); also elsewhere on the board
12V: D1.A, J4.2, Q3.2 (S), R1.P$2; also elsewhere on the board
AIS_RX_EVENT: J2.P$6 (6); also elsewhere on the board
AIS_TX_EVENT: J2.P$7 (7); also elsewhere on the board
CAN_H: D3.2, J4.4; also elsewhere on the board
CAN_L: D3.1, J4.5; also elsewhere on the board
CH340_RX: U1.2 (VOA), U$1.7 (RX)
CH340_TX: U1.3 (VIB), U$1.6 (TX)
D+: D4.C, J3.3, U$1.1 (D+)
D-: D5.C, J3.2, U$1.2 (D-)
GND: C1.P$2 (2), C3.P$2 (2), C10.P$2 (2), C11.P$2 (2), C14.P$2 (2), D1.C, D3.3, D6.A, D7.A, IC2.2 (GND), J2.P$8 (8), J2.P$9 (SHLD), J2.P$10 (SHLD), J2.P$11 (SHLD), J2.P$12 (SHLD), J4.3, Q4.2 (S), U1.5 (GND2), U6.1 (GND); also elsewhere on the board
GND-ISO: C4.P$2 (2), C5.P$2 (2), C13.P$1 (1), D2.A, D4.A, D5.A, J3.5, J3.S1 (SHIELD), J3.S2 (SHIELD), J3.S3 (SHIELD), J3.S4 (SHIELD), J3.S5 (SHIELD), J3.S6 (SHIELD), U1.4 (GND1), U$1.3 (GND)
GPS_STATUS: J2.P$4 (4); also elsewhere on the board
MCU_UART_RX: R11.P$1; also elsewhere on the board
MCU_UART_TX: R10.P$1; also elsewhere on the board
unnamed: C4.P$1 (1), U$1.8 (V3)
unnamed: Q3.1 (G), Q4.3 (D), R1.P$1
unnamed: F1.1, Q3.3 (D)
unnamed: C14.P$1 (1), IC2.3 (EN), R8.P$1
PWR_CTRL: Q4.1 (G); also elsewhere on the board
TRANSPONDER_UART_RX: D6.C, J2.P$3 (3), R11.P$2, U1.6 (VOB); also elsewhere on the board
TRANSPONDER_UART_TX: D7.C, J2.P$5 (5), R10.P$2, U1.7 (VIA); also elsewhere on the board
TX_DISABLE: J2.P$2 (2); also elsewhere on the board
VBUS: C5.P$1 (1), C13.P$2 (2), D2.C, J3.1, U1.1 (VDD1), U$1.5 (VCC)
V_OUT: C11.P$1 (1), F1.2, IC2.1 (IN), J2.P$1 (1), R8.P$2

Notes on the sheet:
MAIANA™ AIS Transponder Copyright © 2015-2021 Peter Antypas Licensed under GPLv3
Connections & Power


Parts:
GPS: LEDCHIPLED_1206; CHIPLED_1206; PARTNO TJ-S3216CL9T5ALC2G-A5
ON_OFF: CL-SB-12B-01T; CL-SB-12B; PARTNO CL-SB-12B-01T
PWR: LEDCHIPLED_1206; CHIPLED_1206; PARTNO TJ-S3216CL9T5ALC2G-A5
R2, R3, R4, R5: 2k2; 0603; PARTNO CR0603-FX-2201ELF
RX: LEDCHIPLED_1206; CHIPLED_1206; PARTNO TJ-S3216CL9T5ALC2G-A5
SILENT: CL-SB-12B-01T; CL-SB-12B; PARTNO CL-SB-12B-01T
TX: LEDCHIPLED_1206; CHIPLED_1206; PARTNO TJ-S3216CL9T5ALC2G-A5

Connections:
3.3V: GPS.A, PWR.A, RX.A, SILENT.1, TX.A; also elsewhere on the board
12V: ON_OFF.3; also elsewhere on the board
AIS_RX_EVENT: R4.P$2; also elsewhere on the board
AIS_TX_EVENT: R5.P$2; also elsewhere on the board
GND: ON_OFF.1, R2.P$2, SILENT.3; also elsewhere on the board
GPS_STATUS: R3.P$2; also elsewhere on the board
unnamed: PWR.C, R2.P$1
unnamed: GPS.C, R3.P$1
unnamed: R4.P$1, RX.C
unnamed: R5.P$1, TX.C
PWR_CTRL: ON_OFF.2; also elsewhere on the board
TX_DISABLE: SILENT.2; also elsewhere on the board

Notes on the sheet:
Status signals from the transponder are 30V tolerant open drain outputs with 100Ohm current limiting resistors
MAIANA™ AIS Transponder Copyright © 2015-2021 Peter Antypas Licensed under GPLv3
User Interface


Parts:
C2: 0.1uF; 0603; PARTNO 06035C104KAT2A
Q1: BSS138; SOT23; PARTNO BSS138
R7, R9, R12: 10k; 0603; PARTNO RC0603FR-0710KL
SW1: TS-1814; TE_1977066-1; PARTNO TS-1814
U4: STM32L432KBU6; QFN32; PARTNO STM32L422KBU6

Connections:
3.3V: C2.P$1 (1), R9.P$2, SW1.2, U4.1 (VDD), U4.5 (VDDA), U4.17 (VDD); also elsewhere on the board
BOOT0: R12.P$1, SW1.1, SW1.3 (1), U4.31 (BOOT0); also elsewhere on the board
GND: C2.P$2 (2), R12.P$2, SW1.S1 (SHIELD), SW1.S2 (SHIELD), U4.16 (VSS), U4.32 (VSS), U4.EXP (PAD); also elsewhere on the board
MCU_UART_RX: U4.20 (PA10); also elsewhere on the board
MCU_UART_TX: U4.19 (PA9); also elsewhere on the board
NMEA_RX: Q1.3 (D), R9.P$1, U4.9 (PA3)
NMEA_RX_EN: Q1.1 (G), R7.P$2, U4.14 (PB0)
NRST: U4.4 (NRST); also elsewhere on the board
SPI_CS: U4.8 (PA2); also elsewhere on the board
SPI_MISO: U4.12 (PA6); also elsewhere on the board
SPI_MOSI: U4.13 (PA7); also elsewhere on the board
SPI_SCK: U4.11 (PA5); also elsewhere on the board
SWCLK: U4.24 (PA14); also elsewhere on the board
SWDIO: U4.23 (PA13); also elsewhere on the board
TRANSPONDER_UART_TX: Q1.2 (S), R7.P$1; also elsewhere on the board
TX_DISABLE: U4.18 (PA8); also elsewhere on the board

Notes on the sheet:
MAIANA™ AIS Transponder Copyright © 2015-2021 Peter Antypas Licensed under GPLv3
MCU
The UART signals to and from the transponder flow through this circuit to the isolator and USB adapter. The TX signal from the transponder is branched to the MCU as well via a firmware controlled MOSFET switch (Q1). When the local MCU runs NMEA2000 application firmware, PA9 and PA10 are high z inpu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


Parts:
C6, C7: 0.1uF; 0603; PARTNO 06035C104KAT2A
C8, C9: 20pF; 0603; PARTNO GRM1885C1H200JA01D
R6: 10k; 0603; PARTNO RC0603FR-0710KL
U2: MCP2515-I/ST; TSSOP20; PARTNO MCP2515-I/ST
U3: MCP2551T-I/SN; SOIC127P600X175-8N; PARTNO MCP2551T-I/SN
Y1: X322516MOB4SI; XTAL_ECS-160-10-36-JGN-TR; PARTNO X322516MOB4SI

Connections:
3.3V: C7.P$1 (1), U2.20 (VDD); also elsewhere on the board
5V: C6.P$1 (1), U3.3 (VDD); also elsewhere on the board
CAN_H: U3.7 (CANH); also elsewhere on the board
CAN_L: U3.6 (CANL); also elsewhere on the board
GND: C6.P$2 (2), C7.P$2 (2), C8.P$2 (2), C9.P$2 (2), R6.P$1, U2.10 (GND), U3.2 (VSS), Y1.2 (GND), Y1.4 (GND); also elsewhere on the board
unnamed: R6.P$2, U3.8 (RS)
unnamed: U2.2 (RXCAN), U3.4 (RXD)
unnamed: U2.1 (TXCAN), U3.1 (TXD)
unnamed: C9.P$1 (1), U2.9 (OSC1), Y1.3 (OUT/IN)
unnamed: C8.P$1 (1), U2.8 (OSC2), Y1.1 (IN/OUT)
NRST: U2.19 (!RESET); also elsewhere on the board
SPI_CS: U2.18 (CS); also elsewhere on the board
SPI_MISO: U2.17 (SO); also elsewhere on the board
SPI_MOSI: U2.16 (SI); also elsewhere on the board
SPI_SCK: U2.14 (SCK); also elsewhere on the board

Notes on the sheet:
MAIANA™ AIS Transponder Copyright © 2015-2021 Peter Antypas Licensed under GPLv3
CAN


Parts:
TP1, TP2, TP3, TP4, TP5, TP6, TP7, TP8, TP9, TP10, TP11, TP12, TP13, TP14: TPTP12R; TP12R

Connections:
3.3V: TP6.TP; also elsewhere on the board
5V: TP7.TP; also elsewhere on the board
12V: TP1.TP; also elsewhere on the board
BOOT0: TP5.TP; also elsewhere on the board
CAN_H: TP3.TP; also elsewhere on the board
CAN_L: TP4.TP; also elsewhere on the board
GND: TP2.TP, TP13.TP, TP14.TP; also elsewhere on the board
NRST: TP10.TP; also elsewhere on the board
SWCLK: TP12.TP; also elsewhere on the board
SWDIO: TP11.TP; also elsewhere on the board
TRANSPONDER_UART_RX: TP8.TP; also elsewhere on the board
TRANSPONDER_UART_TX: TP9.TP; also elsewhere on the board

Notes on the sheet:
MAIANA™ AIS Transponder Copyright © 2015-2021 Peter Antypas Licensed under GPLv3
Test Pads



Board: 2 copper layers, 46.0 x 46.0 mm, 71 parts (16 on the bottom side), 45 nets.

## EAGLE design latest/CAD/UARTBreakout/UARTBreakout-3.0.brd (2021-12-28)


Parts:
C1, C2: 1uF; 0603; PARTNO CC0603KRX5R8BB105
D1: SMBJ14CA; SMB-BIDIR; PARTNO SMBJ14CA
D2: WSB5508L-2/TR; SOD123; PARTNO WSB5508L-2/TR
F1: BSMD1206-050-16V; R1206; PARTNO BSMD1206-050-16V
J2: RJ45; RJ45-8; PARTNO 95501-2821
JP2, JP3: M08SILK_FEMALE_PTH; 1X08
U1: SE8533X2-HF; SOT23; PARTNO SE8533X2-HF

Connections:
3.3V: C2.P$1 (1), JP2.1, JP2.2, JP2.3, JP3.1, U1.2 (VO)
12V: D1.A, D2.A, JP3.8
GND: C1.P$2 (2), C2.P$2 (2), D1.C, J2.8, JP2.4, JP3.2, JP3.3, JP3.4, JP3.7, U1.1 (GND); also elsewhere on the board
GPS_LED: J2.4, JP2.7
RX_LED: J2.6, JP2.8
TRANSPONDER_UART_RX: J2.3, JP2.6; also elsewhere on the board
TRANSPONDER_UART_TX: J2.5, JP2.5; also elsewhere on the board
TX_LED: J2.7, JP3.6
TX_OFF: J2.2, JP3.5
V_IN: D2.C, F1.1
V_OUT: C1.P$1 (1), F1.2, J2.1, U1.3 (VIN)

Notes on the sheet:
MAIANA™ AIS Transponder Copyright © 2015-2021 Peter Antypas Licensed under GPLv3
Basic Breakout
Battery input w/ ESD and reverse polarity protection. (Working voltage range: 9-18V)
RJ45 connector from exterior unit
External pin headers
TRANSPONDER_UART_TX: 3.3V UART output from transponder board TRANSPONDER_UART_RX: 3.3V UART input into transponder board RX_LED: Open drain output, pulled low for 20ms during packet RX TX_LED: Open drain output, pulled low to indicate TX enabled, toggled during TX event GPS_LED: Open drain output, 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
A 3.3V/100mA rail is made available for LEDs, a TX_DISABLE signal or other optional components.


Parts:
C4, C5: 0.1uF; 0603
D3: 3V; SOD-323
J1: 10118194-0001LF; AMPHENOL_10118194-0001LF
R8: 75R; 0603
U$1: CH340N; SOIC-8; PARTNO CH340N
U$4: SRV05-4; SOT23-6

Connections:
D+: J1.3, U$1.1 (D+), U$4.3 (IO2)
D-: J1.2, U$1.2 (D-), U$4.1 (IO1)
GND: C4.P$2 (2), C5.P$2 (2), D3.A, J1.5, J1.S1 (SHIELD), J1.S2 (SHIELD), J1.S3 (SHIELD), J1.S4 (SHIELD), J1.S5 (SHIELD), J1.S6 (SHIELD), U$1.3 (GND), U$4.2 (GND); also elsewhere on the board
unnamed: C4.P$1 (1), U$1.8 (V3)
TRANSPONDER_UART_RX: U$1.6 (TX); also elsewhere on the board
TRANSPONDER_UART_TX: U$1.7 (RX); also elsewhere on the board
USB_3V3: C5.P$1 (1), D3.C, R8.P$2, U$1.5 (VCC)
VBUS: J1.1, R8.P$1, U$4.5 (VCC)

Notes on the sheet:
MAIANA™ AIS Transponder Copyright © 2015-2021 Peter Antypas Licensed under GPLv3
USB Interface


Board: 2 copper layers, 55.9 x 17.4 mm, 16 parts (0 on the bottom side), 16 nets.

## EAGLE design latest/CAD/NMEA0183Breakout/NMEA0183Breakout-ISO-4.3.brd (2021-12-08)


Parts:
C1, C2, C7, C8, C9: 1uF; 0603; PARTNO CC0603KRX5R8BB105
D1: SMBJ14CA; SMB-BIDIR; PARTNO SMBJ14CA
D2: WSB5508L-2/TR; SOD123; PARTNO WSB5508L-2/TR
F1: BSMD1206-050-16V; R1206; PARTNO BSMD1206-050-16V
IC1: LD2985BM50R; SOT23-5; PARTNO LD2985BM50R
J2: RJ-82A86MMNL
JP1: OSTVN04A150; 1X04; PARTNO OSTVN04A150
Q3: SI2307CDS-T1-E3; SOT23; PARTNO SI2307CDS-T1-E3
Q4: BSS138; SOT23; PARTNO BSS138
R1, R6: 10k; 0603; PARTNO RC0603FR-0710KL
S1, S2: LC1258EENP; LC1258XXNP; PARTNO LC1258EENP
U5: SE8533X2-HF; SOT23; PARTNO SE8533X2-HF

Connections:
3.3V: C7.P$1 (1), S2.P$3 (3), U5.2 (VO); also elsewhere on the board
5V: C1.P$1 (1), C8.P$1 (1), IC1.5 (OUT), U5.3 (VIN); also elsewhere on the board
12V: D1.A, D2.A, JP1.1
AIS_RX_EVENT: J2.P$6 (6); also elsewhere on the board
AIS_TX_EVENT: J2.P$7 (7); also elsewhere on the board
GND: C1.P$2 (2), C2.P$2 (2), C7.P$2 (2), C8.P$2 (2), C9.P$2 (2), D1.C, IC1.2 (GND), J2.P$8 (8), J2.P$9 (SHLD), J2.P$10 (SHLD), J2.P$11 (SHLD), J2.P$12 (SHLD), JP1.2, Q4.2 (S), S1.P$1 (1), S2.P$1 (1), U5.1 (GND); also elsewhere on the board
GPS_STATUS: J2.P$4 (4); also elsewhere on the board
unnamed: C9.P$1 (1), IC1.3 (EN), R6.P$1
unnamed: Q3.1 (G), Q4.3 (D), R1.P$1
unnamed: F1.1, Q3.3 (D)
PWR_CTRL: Q4.1 (G), S1.P$2 (2)
S1: JP1.3; also elsewhere on the board
S2: JP1.4; also elsewhere on the board
TRANSPONDER_UART_RX: J2.P$3 (3); also elsewhere on the board
TRANSPONDER_UART_TX: J2.P$5 (5); also elsewhere on the board
TX_DISABLE: J2.P$2 (2), S2.P$2 (2)
V_IN: D2.C, Q3.2 (S), R1.P$2, S1.P$3 (3)
V_OUT: C2.P$1 (1), F1.2, IC1.1 (IN), J2.P$1 (1), R6.P$2

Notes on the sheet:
For proper power sequencing, a delay is added to the EN signal of this LDO to ensure the remote unit has fully powered up before enabling the local 3.3V rail

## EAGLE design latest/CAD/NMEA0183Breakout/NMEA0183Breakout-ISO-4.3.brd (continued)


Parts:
C4, C5, C10, C11: 0.1uF; 0603; PARTNO 06035C104KAT2A
J1: 10118194-0001LF; AMPHENOL_10118194-0001LF; PARTNO 10118194-0001LF
U2: π122U31; SOIC8; PARTNO π122U31
U3: CH340N; SOIC-8; PARTNO CH340N

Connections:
3.3V: C11.P$2 (2), U2.8 (VDD2); also elsewhere on the board
CH340_RX: U2.2 (VOA), U3.7 (RX)
CH340_TX: U2.3 (VIB), U3.6 (TX)
D+: J1.3, U3.1 (D+)
D-: J1.2, U3.2 (D-)
GND: C11.P$1 (1), U2.5 (GND2); also elsewhere on the board
GND-ISO: C4.P$2 (2), C5.P$2 (2), C10.P$1 (1), J1.5, J1.S1 (SHIELD), J1.S2 (SHIELD), J1.S3 (SHIELD), J1.S4 (SHIELD), J1.S5 (SHIELD), J1.S6 (SHIELD), U2.4 (GND1), U3.3 (GND)
unnamed: C4.P$1 (1), U3.8 (V3)
TRANSPONDER_UART_RX: U2.6 (VOB); also elsewhere on the board
TRANSPONDER_UART_TX: U2.7 (VIA); also elsewhere on the board
VBUS: C5.P$1 (1), C10.P$2 (2), J1.1, U2.1 (VDD1), U3.5 (VCC)


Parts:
GPS: LEDCHIPLED_1206; CHIPLED_1206; PARTNO TJ-S3216CL9T5ALC2G-A5
PWR: LEDCHIPLED_1206; CHIPLED_1206; PARTNO TJ-S3216CL9T5ALC2G-A5
R2, R3, R4, R5: 2k2; 0603; PARTNO CR0603-FX-2201ELF
RX: LEDCHIPLED_1206; CHIPLED_1206; PARTNO TJ-S3216CL9T5ALC2G-A5
TX: LEDCHIPLED_1206; CHIPLED_1206; PARTNO TJ-S3216CL9T5ALC2G-A5

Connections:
3.3V: GPS.A, PWR.A, RX.A, TX.A; also elsewhere on the board
AIS_RX_EVENT: R4.P$2; also elsewhere on the board
AIS_TX_EVENT: R5.P$2; also elsewhere on the board
GND: R2.P$2; also elsewhere on the board
GPS_STATUS: R3.P$2; also elsewhere on the board
unnamed: PWR.C, R2.P$1
unnamed: GPS.C, R3.P$1
unnamed: R4.P$1, RX.C
unnamed: R5.P$1, TX.C

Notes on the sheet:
Status signals from the transponder are 20V tolerant open drain outputs with 100Ohm current limiting resistors


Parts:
C3: 0.1uF; 0603; PARTNO 06035C104KAT2A
U1: DS8921M; SOIC127P599X175-8N; PARTNO DS8921M
U4: TPD2E1B06DRLR; SOTFL50P160X60-6N; PARTNO TPD2E1B06DRLR

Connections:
5V: C3.P$1 (1), U1.1 (VCC); also elsewhere on the board
GND: C3.P$2 (2), U1.4 (GND), U4.4 (IOB2), U4.5 (IOA2); also elsewhere on the board
S1: U1.5 (DO-), U4.2 (IOB1); also elsewhere on the board
S2: U1.6 (DO+), U4.1 (IOA1); also elsewhere on the board
TRANSPONDER_UART_TX: U1.3 (DI); also elsewhere on the board


Board: 2 copper layers, 52.0 x 42.0 mm, 36 parts (0 on the bottom side), 29 nets.

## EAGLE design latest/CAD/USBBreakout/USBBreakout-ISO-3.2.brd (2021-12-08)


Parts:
C1, C2: 1uF; 0603; PARTNO CC0603KRX5R8BB105
D1: SMBJ14CA; SMB-BIDIR; PARTNO SMBJ14CA
D2: WSB5508L-2/TR; SOD123; PARTNO WSB5508L-2/TR
F1: BSMD1206-050-16V; R1206; PARTNO BSMD1206-050-16V
J1: OSTVN02A150; CONN_OSTVN02A150_OST; PARTNO OSTVN02A150
J3: RJ-82A86MMNL
Q3: SI2307CDS-T1-E3; SOT23; PARTNO SI2307CDS-T1-E3
Q4: BSS138; SOT23; PARTNO BSS138
R1: 10k; 0603; PARTNO RC0603FR-0710KL
U3: SE8533X2-HF; SOT23; PARTNO SE8533X2-HF

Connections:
3.3V: C1.P$1 (1), U3.2 (VO); also elsewhere on the board
12V: D1.A, D2.A, J1.2
AIS_RX_EVENT: J3.P$6 (6); also elsewhere on the board
AIS_TX_EVENT: J3.P$7 (7); also elsewhere on the board
GND: C1.P$2 (2), C2.P$2 (2), D1.C, J1.1, J3.P$8 (8), J3.P$9 (SHLD), J3.P$10 (SHLD), J3.P$11 (SHLD), J3.P$12 (SHLD), Q4.2 (S), U3.1 (GND); also elsewhere on the board
GPS_STATUS: J3.P$4 (4); also elsewhere on the board
unnamed: Q3.1 (G), Q4.3 (D), R1.P$1
unnamed: F1.1, Q3.3 (D)
PWR_CTRL: Q4.1 (G); also elsewhere on the board
TRANSPONDER_UART_RX: J3.P$3 (3); also elsewhere on the board
TRANSPONDER_UART_TX: J3.P$5 (5); also elsewhere on the board
TX_DISABLE: J3.P$2 (2); also elsewhere on the board
V_IN: D2.C, Q3.2 (S), R1.P$2; also elsewhere on the board
V_OUT: C2.P$1 (1), F1.2, J3.P$1 (1), U3.3 (VIN)

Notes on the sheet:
MAIANA™ AIS Transponder Copyright © 2015-2021 Peter Antypas Licensed under GPLv3
Connections and Power


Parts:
GPS: LEDCHIPLED_1206; CHIPLED_1206; PARTNO TJ-S3216CL9T5ALC2G-A5
ON_OFF: CL-SB-12B-01T; CL-SB-12B; PARTNO CL-SB-12B-01T
PWR: LEDCHIPLED_1206; CHIPLED_1206; PARTNO TJ-S3216CL9T5ALC2G-A5
R2, R3, R4, R5: 2k2; 0603; PARTNO CR0603-FX-2201ELF
RX: LEDCHIPLED_1206; CHIPLED_1206; PARTNO TJ-S3216CL9T5ALC2G-A5
SILENT: CL-SB-12B-01T; CL-SB-12B; PARTNO CL-SB-12B-01T
TX: LEDCHIPLED_1206; CHIPLED_1206; PARTNO TJ-S3216CL9T5ALC2G-A5

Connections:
3.3V: GPS.A, PWR.A, RX.A, SILENT.1, TX.A; also elsewhere on the board
AIS_RX_EVENT: R4.P$2; also elsewhere on the board
AIS_TX_EVENT: R5.P$2; also elsewhere on the board
GND: ON_OFF.1, R2.P$2, SILENT.3; also elsewhere on the board
GPS_STATUS: R3.P$2; also elsewhere on the board
unnamed: PWR.C, R2.P$1
unnamed: GPS.C, R3.P$1
unnamed: R4.P$1, RX.C
unnamed: R5.P$1, TX.C
PWR_CTRL: ON_OFF.2; also elsewhere on the board
TX_DISABLE: SILENT.2; also elsewhere on the board
V_IN: ON_OFF.3; also elsewhere on the board

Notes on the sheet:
Status signals from the transponder are 30V tolerant open drain outputs with 100Ohm current limiting resistors
MAIANA™ AIS Transponder Copyright © 2015-2021 Peter Antypas Licensed under GPLv3
User Interface


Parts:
C4, C5, C6, C7: 0.1uF; 0603; PARTNO 06035C104KAT2A
J2: 10118194-0001LF; AMPHENOL_10118194-0001LF; PARTNO 10118194-0001LF
U1: PI122U31; SOIC8; PARTNO Pi122U31
U2: CH340N; SOIC-8; PARTNO CH340N

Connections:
3.3V: C7.P$2 (2), U1.8 (VDD2); also elsewhere on the board
CH340_RX: U1.2 (VOA), U2.7 (RX)
CH340_TX: U1.3 (VIB), U2.6 (TX)
D+: J2.3, U2.1 (D+)
D-: J2.2, U2.2 (D-)
GND: C7.P$1 (1), U1.5 (GND2); also elsewhere on the board
GND-ISO: C4.P$2 (2), C5.P$2 (2), C6.P$1 (1), J2.5, J2.S1 (SHIELD), J2.S2 (SHIELD), J2.S3 (SHIELD), J2.S4 (SHIELD), J2.S5 (SHIELD), J2.S6 (SHIELD), U1.4 (GND1), U2.3 (GND)
unnamed: C4.P$1 (1), U2.8 (V3)
TRANSPONDER_UART_RX: U1.6 (VOB); also elsewhere on the board
TRANSPONDER_UART_TX: U1.7 (VIA); also elsewhere on the board
VBUS: C5.P$1 (1), C6.P$2 (2), J2.1, U1.1 (VDD1), U2.5 (VCC)

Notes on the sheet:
MAIANA™ AIS Transponder Copyright © 2015-2021 Peter Antypas Licensed under GPLv3
USB Isolation



Board: 2 copper layers, 36.0 x 46.0 mm, 28 parts (3 on the bottom side), 25 nets.

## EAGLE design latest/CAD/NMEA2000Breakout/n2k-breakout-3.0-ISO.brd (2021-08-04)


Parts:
C1, C3, C12: 1uF; 0603
C4, C5, C13: 0.1uF; 0603
D1: SMBJ16CA; SMB-BIDIR
D3: PESD1CAN-UX; SOT65P210X110-3N
F1: BSMD1206-050-16V; R1206
IC1: MIC5203-3.3YM5-TR; SOT23-5
J2: RJ-82A86MMNL
J3: 10118194-0001LF; AMPHENOL_10118194-0001LF
J4: 12-3701-05; MICRO_C_5PIN
Q3: DMP3099L-7; SOT23
Q4: BSS138; SOT23
R1, R7: 10k; 0603
U1: π122U31; SOIC8; PARTNO π122U31
U$1: CH340N; SOIC-8; PARTNO CH340N

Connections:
3.3V: C1.P$1 (1), IC1.5 (OUT), U1.8 (VDD2); also elsewhere on the board
12V: D1.A, J4.2, Q3.2 (S), R1.P$2; also elsewhere on the board
AIS_RX_EVENT: J2.P$6 (6); also elsewhere on the board
AIS_TX_EVENT: J2.P$7 (7); also elsewhere on the board
CAN_H: D3.2, J4.4; also elsewhere on the board
CAN_L: D3.1, J4.5; also elsewhere on the board
CH340_RX: U1.2 (VOA), U$1.7 (RX)
CH340_TX: U1.3 (VIB), U$1.6 (TX)
D+: J3.3, U$1.1 (D+)
D-: J3.2, U$1.2 (D-)
GND: C1.P$2 (2), C3.P$2 (2), C12.P$2 (2), D1.C, D3.3, IC1.2 (GND), J2.P$8 (8), J2.P$9 (SHLD), J2.P$10 (SHLD), J2.P$11 (SHLD), J2.P$12 (SHLD), J4.3, Q4.2 (S), U1.5 (GND2); also elsewhere on the board
GND-ISO: C4.P$2 (2), C5.P$2 (2), C13.P$1 (1), J3.5, J3.S1 (SHIELD), J3.S2 (SHIELD), J3.S3 (SHIELD), J3.S4 (SHIELD), J3.S5 (SHIELD), J3.S6 (SHIELD), U1.4 (GND1), U$1.3 (GND)
GPS_STATUS: J2.P$4 (4); also elsewhere on the board
MUX_RX: U1.6 (VOB); also elsewhere on the board
MUX_TX: U1.7 (VIA); also elsewhere on the board
unnamed: C4.P$1 (1), U$1.8 (V3)
unnamed: Q3.1 (G), Q4.3 (D), R1.P$1
unnamed: C12.P$1 (1), IC1.3 (EN), R7.P$1
unnamed: F1.1, Q3.3 (D)
PWR_CTRL: Q4.1 (G); also elsewhere on the board
TRANSPONDER_UART_RX: J2.P$3 (3); also elsewhere on the board
TRANSPONDER_UART_TX: J2.P$5 (5); also elsewhere on the board
TX_DISABLE: J2.P$2 (2); also elsewhere on the board
VBUS: C5.P$1 (1), C13.P$2 (2), J3.1, U1.1 (VDD1), U$1.5 (VCC)
V_OUT: C3.P$1 (1), F1.2, IC1.1 (IN), J2.P$1 (1), R7.P$2

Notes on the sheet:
MAIANA™ AIS Transponder Copyright © 2015-2021 Peter Antypas Licensed under GPLv3
Connections & Power


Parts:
C10: 1uF; 0603
GPS: LEDCHIPLED_1206; CHIPLED_1206; PARTNO TJ-S3216CL9T5ALC2G-A5
ON_OFF: CL-SB-12B-01T; CL-SB-12B
PWR: LEDCHIPLED_1206; CHIPLED_1206; PARTNO TJ-S3216CL9T5ALC2G-A5
Q2: DMP3099L-7; SOT23
R2, R3, R4, R5, R6: 2k2; 0603
RX: LEDCHIPLED_1206; CHIPLED_1206; PARTNO TJ-S3216CL9T5ALC2G-A5
SILENT: CL-SB-12B-01T; CL-SB-12B
TX: LEDCHIPLED_1206; CHIPLED_1206; PARTNO TJ-S3216CL9T5ALC2G-A5

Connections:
3.3V: GPS.A, PWR.A, Q2.2 (S), RX.A, SILENT.1; also elsewhere on the board
12V: ON_OFF.3; also elsewhere on the board
AIS_RX_EVENT: R4.P$2; also elsewhere on the board
AIS_TX_EVENT: R5.P$2, TX.A; also elsewhere on the board
GND: C10.P$2 (2), ON_OFF.1, R2.P$2, SILENT.3, TX.C; also elsewhere on the board
GPS_STATUS: R3.P$2; also elsewhere on the board
unnamed: PWR.C, R2.P$1
unnamed: GPS.C, R3.P$1
unnamed: R4.P$1, RX.C
unnamed: R6.P$1, SILENT.2
unnamed: Q2.3 (D), R5.P$1
PWR_CTRL: ON_OFF.2; also elsewhere on the board
TX_DISABLE: C10.P$1 (1), Q2.1 (G), R6.P$2; also elsewhere on the board

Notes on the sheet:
Status signals from the transponder are 30V tolerant open drain outputs with 100Ohm current limiting resistors
MAIANA™ AIS Transponder Copyright © 2015-2021 Peter Antypas Licensed under GPLv3
User Interface


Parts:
C2: 0.1uF; 0603
R12: 10k; 0603
U4: STM32L422KBU6; QFN32

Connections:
3.3V: C2.P$1 (1), U4.1 (VDD), U4.5 (VDDA), U4.17 (VDD); also elsewhere on the board
BOOT0: R12.P$1, U4.31 (BOOT0); also elsewhere on the board
GND: C2.P$2 (2), R12.P$2, U4.16 (VSS), U4.32 (VSS), U4.EXP (PAD); also elsewhere on the board
GREENPAK_RST: U4.26 (PB3); also elsewhere on the board
MCU_NMEA_IN: U4.9 (PA3); also elsewhere on the board
MCU_UART_RX: U4.20 (PA10); also elsewhere on the board
MCU_UART_TX: U4.19 (PA9); also elsewhere on the board
NRST: U4.4 (NRST); also elsewhere on the board
SPI_CS: U4.8 (PA2); also elsewhere on the board
SPI_MISO: U4.12 (PA6); also elsewhere on the board
SPI_MOSI: U4.13 (PA7); also elsewhere on the board
SPI_SCK: U4.11 (PA5); also elsewhere on the board

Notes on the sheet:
MAIANA™ AIS Transponder Copyright © 2015-2021 Peter Antypas Licensed under GPLv3
MCU


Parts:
C6, C7: 0.1uF; 0603
C8, C9: 20pF; 0603
U2: MCP2515-E/ML; QFN20-4X4
U3: TCAN332DCNT; SOT65P280X145-8N; PARTNO TCAN332DCNT
Y1: ECS-160-10-36-JGN-TR; XTAL_ECS-160-10-36-JGN-TR

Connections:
3.3V: C6.P$1 (1), C7.P$1 (1), U2.18 (VDD), U3.3 (VCC); also elsewhere on the board
CAN_H: U3.7 (CANH); also elsewhere on the board
CAN_L: U3.6 (CANL); also elsewhere on the board
GND: C6.P$2 (2), C7.P$2 (2), C8.P$2 (2), C9.P$2 (2), U2.8 (GND), U2.EXP (GND), U3.2 (GND), Y1.2 (GND), Y1.4 (GND); also elsewhere on the board
unnamed: U2.20 (RXCAN), U3.4 (RXD)
unnamed: U2.19 (TXCAN), U3.1 (TXD)
unnamed: C9.P$1 (1), U2.7 (OSC1), Y1.3 (OUT/IN)
unnamed: C8.P$1 (1), U2.6 (OSC2), Y1.1 (IN/OUT)
NRST: U2.17 (!RESET); also elsewhere on the board
SPI_CS: U2.16 (CS); also elsewhere on the board
SPI_MISO: U2.15 (SO); also elsewhere on the board
SPI_MOSI: U2.14 (SI); also elsewhere on the board
SPI_SCK: U2.12 (SCK); also elsewhere on the board

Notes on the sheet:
MAIANA™ AIS Transponder Copyright © 2015-2021 Peter Antypas Licensed under GPLv3
CAN

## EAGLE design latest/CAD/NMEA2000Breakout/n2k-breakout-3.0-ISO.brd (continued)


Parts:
C11: 0.1uF; 0603
SW1: 1977066-1; TE_1977066-1
U5: SLG46537; STQFN20L

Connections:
3.3V: C11.P$1 (1), U5.P$1 (VDD); also elsewhere on the board
BOOT0: U5.P$12 (IO9); also elsewhere on the board
BTN: SW1.1, SW1.3 (1), U5.P$6 (IO4)
GND: C11.P$2 (2), SW1.2, SW1.S1 (SHIELD), SW1.S2 (SHIELD), U5.P$11 (GND); also elsewhere on the board
GREENPAK_RST: U5.P$16 (IO13); also elsewhere on the board
MCU_NMEA_IN: U5.P$10 (IO8); also elsewhere on the board
MCU_UART_RX: U5.P$19 (IO16); also elsewhere on the board
MCU_UART_TX: U5.P$18 (IO15); also elsewhere on the board
MUX_RX: U5.P$5 (IO3); also elsewhere on the board
MUX_TX: U5.P$7 (IO5); also elsewhere on the board
NRST: U5.P$3 (IO1); also elsewhere on the board
TRANSPONDER_UART_RX: U5.P$14 (IO11); also elsewhere on the board
TRANSPONDER_UART_TX: U5.P$4 (IO2); also elsewhere on the board

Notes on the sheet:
This GreenPAK is: - A 2:1 UART multiplexer for the USB interface (transponder vs this MCU) - A UART Tx buffer (transponder UART->MCU USART2) - A DFU reset circuit for this board's MCU
MAIANA™ AIS Transponder Copyright © 2015-2021 Peter Antypas Licensed under GPLv3
GreenPAK



Board: 2 copper layers, 46.0 x 46.0 mm, 45 parts (2 on the bottom side), 45 nets.

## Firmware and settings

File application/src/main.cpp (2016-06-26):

//
// This file is part of the GNU ARM Eclipse distribution.
// Copyright (c) 2014 Liviu Ionescu.
//

// ----------------------------------------------------------------------------

#include "printf2.h"
#include "GPS.hpp"
#include "RadioManager.hpp"
#include "EventQueue.hpp"
#include "LEDManager.hpp"
#include "TXPacket.hpp"
#include "RXPacketProcessor.hpp"
#include "TXScheduler.hpp"
#include "Utils.hpp"
#include "system_stm32f30x.h"
#include "core_cm4.h"
#include "stm32f30x.h"
#include <diag/Trace.h>
#include "DataTerminal.hpp"
#include "TXScheduler.hpp"
#include "DebugPrinter.hpp"
#include "EEPROM.hpp"
#include "CommandProcessor.hpp"

// ----------------------------------------------------------------------------
//
// Standalone STM32F3 empty sample (trace via DEBUG).
//
// Trace support is enabled by adding the TRACE macro definition.
// By default the trace messages are forwarded to the DEBUG output,
// but can be rerouted to any device or completely suppressed, by
// changing the definitions required in system/src/diag/trace_impl.c
// (currently OS_USE_TRACE_ITM, OS_USE_TRACE_SEMIHOSTING_DEBUG/_STDOUT).
//

// ----- main() ---------------------------------------------------------------

// Sample pragmas to cope with warnings. Please note the related line at
// the end of this function, used to pop the compiler diagnostics status.
#pragma GCC diagnostic push
#pragma GCC diagnostic ignored "-Wunused-parameter"
#pragma GCC diagnostic ignored "-Wmissing-declarations"
#pragma GCC diagnostic ignored "-Wreturn-type"



/*
 * DO NOT FORGET to modify this function when changing GPIO pins elsewhere in code.
 */
void configureUnusedPins();


int
main(int argc, char* argv[])
{
    // At this stage the system clock should have already been configured
    // at high speed.
    printf2_Init(38400);

#ifdef DEBUG
    // Disable buffered memory writes to debug imprecise bus faults
    SCnSCB->ACTLR |= SCnSCB_ACTLR_DISDEFWBUF_Msk;
    //trace_printf("ACTLR: %.8x\n", SCnSCB->ACTLR);
#endif

    printf2("Software revision: %s\r\n", REVISION);

    EEPROM::instance().init();
    /*
     * TODO: Move this out of here
    struct StationData __d;
    __d.mmsi = 987654321;
    __d.len = 0;
    __d.beam = 0;
    strcpy(__d.callsign, "0N0000");
    strcpy(__d.name, "TEST STATION 01");
    EEPROM::instance().writeStationData(__d);
    */

    EventQueue::instance().init();
    EventPool::instance().init();
    TXPacketPool::instance().init();
    CommandProcessor::instance().init();

    LEDManager::instance().clear();
    TXScheduler txScheduler;

    DebugPrinter __db;

#ifdef ENABLE_TERMINAL
    DataTerminal::instance().init();
#endif


#if defined CALIBRATION_MODE
    RadioManager::instance().init();
    RadioManager::instance().transmitCW(CH_86);
#elif defined TX_TEST_MODE
    RadioManager::instance().init();
    GPS::instance().init();
    RadioManager::instance().start();
    //Radio::instance().startReceiving(4);
    txScheduler.startTXTesting();
#else
    RXPacketProcessor packetProcessor;

    RadioManager::instance().init();
    GPS::instance().init();
    RadioManager::instance().start();
#endif


    configureUnusedPins();

    // Configure the watchdog timer
    IWDG_WriteAccessCmd(IWDG_WriteAccess_Enable);
    IWDG_SetPrescaler(IWDG_Prescaler_32);
    IWDG_SetReload(4095); // Max 12-bit value

    IWDG_Enable();

    // Dispatch events issued by ISRs and keep the watchdog happy
    printf2("Starting main event loop\r\n");
    while (true) {
        EventQueue::instance().dispatch();
        IWDG_ReloadCounter();
    }
}



void configureUnusedPins()
{
    // ST Micro recommends configuring all unused GPIOs as low outputs
    GPIO_InitTypeDef gpio;

    // Port A pins
    uint32_t pins = GPIO_Pin_15 | GPIO_Pin_11 | GPIO_Pin_12;
    gpio.GPIO_Pin = pins;
    gpio.GPIO_Mode = GPIO_Mode_OUT;
    gpio.GPIO_Speed = GPIO_Speed_Level_1;
    gpio.GPIO_OType = GPIO_OType_PP;
    gpio.GPIO_PuPd = GPIO_PuPd_NOPULL;
    GPIO_Init(GPIOA, &gpio);
    GPIO_ResetBits(GPIOA, pins);

    // Port B pins
    pins = GPIO_Pin_0 | GPIO_Pin_5;
    gpio.GPIO_Pin = pins;
    GPIO_Init(GPIOB, &gpio);
    GPIO_ResetBits(GPIOB, pins);

    // Port C pins
    pins = GPIO_Pin_14 | GPIO_Pin_15;
    gpio.GPIO_Pin = pins;
    GPIO_Init(GPIOC, &gpio);
    GPIO_ResetBits(GPIOC, pins);
}

#pragma GCC diagnostic pop

// ----------------------------------------------------------------------------

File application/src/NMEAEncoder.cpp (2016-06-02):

/*
 * NMEAEncoder.cpp
 *
 *  Created on: Jan 18, 2016
 *      Author: peter
 */

#include "NMEAEncoder.hpp"
#include "Utils.hpp"
#include <cstdio>
#include <cstring>
#include <algorithm>
#include <diag/Trace.h>
#include "AISChannels.h"

using namespace std;


NMEAEncoder::NMEAEncoder()
    : mSequence(0)
{
}

NMEAEncoder::~NMEAEncoder()
{
}

void NMEAEncoder::encode(RXPacket &packet, vector<string> &sentences)
{
    static uint16_t MAX_SENTENCE_BYTES = 56;
    static uint16_t MAX_SENTENCE_BITS = MAX_SENTENCE_BYTES * 6;

    packet.discardCRC();

    uint16_t numBits = packet.size();
    uint16_t fillBits = 0;

    if ( numBits % 6 ) {
        fillBits = 6 - (numBits%6);
        packet.addFillBits(fillBits);
        numBits = packet.size();
    }

    uint16_t numSentences = 1;
    while ( numBits > MAX_SENTENCE_BITS ) {
        ++numSentences;
        numBits -= MAX_SENTENCE_BITS;
    }


    numBits = packet.size();
    if ( numSentences > 1 ) {
        ++mSequence;

        if ( mSequence > 9 )
            mSequence = 0;
    }


    // Now we know how many sentences we need
    char sentence[85];
    uint16_t pos = 0;

    for ( uint16_t i = 1; i <= numSentences; ++i ) {
        uint8_t k = 0;
        if ( numSentences > 1 )
            sprintf(sentence, "!AIVDM,%d,%d,%d,%c,", numSentences, i, mSequence, AIS_CHANNELS[packet.channel()].designation);
        else
            sprintf(sentence, "!AIVDM,%d,%d,,%c,", numSentences, i, AIS_CHANNELS[packet.channel()].designation);

        k = strlen(sentence);
        uint16_t sentenceBits = 0;

        for ( ; pos < numBits && sentenceBits < MAX_SENTENCE_BITS; pos += 6, sentenceBits += 6 ) {
            uint8_t nmeaByte = (uint8_t)packet.bits(pos, 6);
            nmeaByte += (nmeaByte < 40) ? 48 : 56;
            sentence[k++] = nmeaByte;
        }

        //trace_printf("Sentence bits: %d\n", sentenceBits);


        sentence[k++] = ',';
        if ( numSentences > 1 ) {
            if ( i == numSentences )
                sentence[k++] = '0' + fillBits;
            else
                sentence[k++] = '0';
        }
        else
            sentence[k++] = '0';

        sentence[k++] = '*';
        sprintf(sentence+k, "%.2X", nmeaCRC(sentence));
        sentences.push_back(string(sentence));
    }

}

uint8_t NMEAEncoder::nmeaCRC(const char* buff)
{
    uint8_t p = 1;
    uint8_t crc = buff[p++];
    while ( buff[p] != '*' )
        crc ^= buff[p++];
    return crc;
}

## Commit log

2016-05-29 Added latest Eagle files
    [logic3.1.brd, logic3.1.sch, rf9.1.brd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]
2016-05-29 Build settings, Eagle files
    [logic3.1.sch, rf9.1.sch]
2016-05-30 Added wathcdog timer
2016-05-31 More cleanup
    [logic.brd, logic.sch, rf.brd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]
2016-06-01 Fixed mysterious hard fault
    [main.cpp]
2016-06-05 Changed UART parameters to reduce noise
    [DataTerminal.cpp, GPS.cpp, RadioManager.cpp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]
2016-06-07 Multiplexing to single UART
2016-06-15 Corrected UART
2016-12-03 Final version with split board
2017-03-04 Clarified schematic
2017-11-24 Updated schematics with part values
    [logic.brd, logic.sch]
2020-10-03 Starting migration to new design
    [logic.brd, logic.sch, rf.brd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]
2020-10-03 Added Eagle CAD files
    [transponder-4.3.brd, transponder-4.3.sch, transponder-5.0.brd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]
2020-10-03 Schematic for 5.2
    [transponder-5.0.brd, transponder-5.0.sch]
2020-10-03 Schematic for 6.1
2020-10-03 Switched default build to board 6.x
2020-10-03 Board 6.1.1
    [transponder-6.1.1.brd, transponder-6.1.1.sch]
2020-10-07 Board 6.2.0
    [transponder-6.2.0.brd, transponder-6.2.0.sch]
2020-10-07 Comments in schematic
2020-10-08 Board 6.2 tweak
    [transponder-6.2.0.brd]
2020-10-10 Removed board 6.2
    [transponder-6.2.0.brd, transponder-6.2.0.sch]
2020-10-13 Board 6.1.0 bringup
2020-10-13 TX_OFF switch works now
2020-10-17 RJ45 Breakout
    [rj45-breakout-1.0.brd, rj45-breakout-1.0.sch]
2020-10-17 Removed 6.2
    [rj45-breakout-1.0.brd, rj45-breakout-1.0.sch, transponder-6.2.0.brd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]
2020-10-17 Gerbers and schematic for breakout
2020-11-02 Hard-coded noise floor for now
    [GPS.cpp, Receiver.cpp, Transceiver.cpp]
2020-11-03 Checkpoint. Best RX performance possible with current architecture
2020-11-21 Board 9.3
2020-11-21 Board 9.3 CAD
    [rj45-breakout-9.3.brd, rj45-breakout-9.3.sch, transponder-9.3.0.brd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]
2020-11-25 Build issue w/ different SDKs
    [GPS.cpp, Transceiver.cpp]
2020-12-13 Board 10.x
2020-12-13 Board 10
    [rj45-breakout-10.0.brd, rj45-breakout-10.0.sch, transponder-10.0.1.brd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]
2020-12-25 Restored original CCA headroom, fixed GPIO config for RX IC
    [Receiver.cpp, Transceiver.cpp]
2020-12-25 Board 10.0.1
    [transponder-10.0.1-BOM.xlsx]
2020-12-25 10.0.1 schematic
2020-12-25 10.0.1 gerber update
2021-02-26 Resetting MCU every hour
    [RFIC.cpp, RadioManager.cpp, main.cpp]
2021-03-09 Untested support for STM32L422xx
2021-03-30 Board 10.5
2021-05-24 Support for board 10.5/6 and 10.7
2021-06-01 Board 10.5.x CAD files
    [rj45-breakout-10.5.0.brd, rj45-breakout-10.5.0.sch, transponder-10.5.0.brd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]
2021-06-05 10.5.0 BOM
    [Transponder-10.5.0-BOM.xlsx]
2021-06-05 BSP cleanup + LEDManager
2021-06-27 Board 10.9 bringup
2021-07-10 Board 10.9 Finished
2021-07-11 Updated CAD
    [NMEA0183Breakout-2.0.brd, NMEA0183Breakout-2.0.sch, USBBreakout-1.3.brd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]
2021-07-11 More CAD
2021-07-11 Fill bits was incorrectly set to 0 on all single frame messages
2021-07-30 FreeCAD for 0183 box
    [NMEA0183Breakout-3.0.FCStd]
2021-08-04 N2K breakout final
    [NewNMEA2000Breakout-1.1.FCStd, NewNMEA2000Breakout-1.1.step, n2k-breakout-3.0-ISO.brd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]
2021-08-21 BSP for board 11.0
2021-08-24 Board 11.0 bringup complete
2021-08-27 Board 11.0 final
    [transponder-11.0.0.brd, transponder-11.0.0.sch]
2021-09-23 TX LED logic 100% in FW
2021-10-04 Better way to mange TX LED
2021-10-12 Preliminary support for i2c EEPROM
2021-10-20 Board 11.3.0 is it
2021-10-20 Board 11.3 & UART breakout
    [UARTBreakout-2.0.brd, UARTBreakout-2.0.sch, transponder-11.3.0.brd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]
2021-10-20 UART breakout photo
2021-10-29 GPS LED wasn't turning off after loss of fix
    [GPS.cpp]
2021-11-15 Bootloader flashes LEDs
2021-11-19 N2K adapter schematic
2021-11-19 N2K adapter gerbers
2021-11-19 N2K adapter Eagle files
    [n2k-breakout-4.0-ISO.brd, n2k-breakout-4.0-ISO.sch]
2021-12-08 Updated USB breakout CAD
    [USBBreakout-ISO-3.2.brd, USBBreakout-ISO-3.2.sch]
2021-12-08 Updated NMEA0183 breakout
    [NMEA0183Breakout-ISO-4.3.brd, NMEA0183Breakout-ISO-4.3.sch]
2021-12-28 New UART+USB breakout
    [UARTBreakout-3.0.brd, UARTBreakout-3.0.sch]
2021-12-28 Antenna parts
    [antenna_cap-7.0.FCStd, antenna_cap-7.0.step, antenna_cap-9.0.FCStd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]
2021-12-28 Board 11.5.2
    [transponder-11.5.2.brd, transponder-11.5.2.sch]
2022-02-11 Fixed BSP for board 11.0
2022-02-12 New N2K adapter board
2022-02-24 Fixed UI to enable FW update when board boots in 'rescue' mode
2022-03-11 Board 7
2022-04-28 Latest n2k adapter CAD
    [n2k-breakout-7.0-ISO.brd, n2k-breakout-7.0-ISO.sch]
2022-05-10 Board 11.8.0
    [transponder-11.8.0.brd, transponder-11.8.0.sch]
2023-03-01 Support for 10.0.1
    Regression for support of latest software on board 10.0.1
    Essentially it boils down to sense of the GPS_EN line and RX_EN line
2023-09-27 Detecting RF IC initialization error
    [RFIC.cpp, RadioManager.cpp, main.cpp]
2024-01-25 Board 11.9.0
    [connections.kicad_sch, gnss.kicad_sch, mcu.kicad_sch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]
2024-02-03 Board 11.9.1
    [connections.kicad_sch, gnss.kicad_sch, mcu.kicad_sch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]
2024-02-17 Removed 11.9.0
    [connections.kicad_sch, gnss.kicad_sch, mcu.kicad_sch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]
2024-06-15 Added 4.4.1 binary for L432 boards
2025-01-29 KiCad projects for N2K and 0183 adapters
    [NMEA0183Adapter-7.1.kicad_pcb, NMEA0183Adapter-7.1.kicad_sch, NMEA2000Adapter-8.1.kicad_pcb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]
2025-07-09 Fixed build under GCC 13+
    [NMEAEncoder.cpp]

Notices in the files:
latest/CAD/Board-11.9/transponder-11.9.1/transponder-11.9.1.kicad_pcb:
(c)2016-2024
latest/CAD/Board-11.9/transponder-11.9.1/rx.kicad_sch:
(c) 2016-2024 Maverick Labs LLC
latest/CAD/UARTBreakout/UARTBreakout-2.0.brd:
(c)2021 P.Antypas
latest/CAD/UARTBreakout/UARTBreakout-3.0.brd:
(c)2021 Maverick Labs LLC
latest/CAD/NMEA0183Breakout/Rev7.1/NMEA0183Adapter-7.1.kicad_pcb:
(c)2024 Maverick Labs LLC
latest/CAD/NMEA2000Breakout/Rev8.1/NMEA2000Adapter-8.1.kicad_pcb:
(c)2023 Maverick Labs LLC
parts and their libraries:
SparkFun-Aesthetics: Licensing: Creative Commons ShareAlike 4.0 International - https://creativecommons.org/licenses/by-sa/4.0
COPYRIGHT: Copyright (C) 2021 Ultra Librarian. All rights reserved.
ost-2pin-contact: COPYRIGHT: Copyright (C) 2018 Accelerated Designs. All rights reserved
